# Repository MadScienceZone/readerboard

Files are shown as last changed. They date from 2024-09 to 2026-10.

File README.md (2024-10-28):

# Readerboard + Busylight
An Electronic Readerboard 64x8 Sign with Discrete "busylight status" LEDs (Arduino-powered).
There is also a smaller, standalone Busylight unit which just provides a status indicator with a 360° view. This was
previously developed in its own dedicated [github project](https://github.com/MadScienceZone/busylight), but it is
now merged into this one.

The next round of development will adapt the firmware and hardware design to drive the various RGB matrix displays
the author bought a couple of years ago from Adafruit as well.

## Description
This is mostly just a thing I put together for [hack value](http://www.catb.org/~esr/jargon/html/H/hack-value.html).

I had been experimenting for years with ideas for LED matrix readerboard design and
implementation, mostly focused on a 64x7 or 64x8 array of single-color LEDs.

Meanwhile, another weekend's idea to solve my need for an office availability
indicator resulted in the Busylight project, which consisted of a set of seven
360° rings of LEDs stacked in a column. By lighting different LED colors or
flashing them in different patterns, a number of statuses could be indicated
to anyone in viewing range.

In late 2024, when the readerboard project was at a point where I had upgraded
it to a full-color RGB LED design and I had a working prototype, it became
apparent that the busylight project should be merged with this one since the
readerboard includes a busylight-style status indicator, making it a superset
of the other device. Now they share a common firmware code base.

The project includes source code for the firmware that runs on the Busylight and Readerboard units,
PCB fabrication files, schematics, and support programs. The latter includes a server which manages
multiple devices attached to a central computer. Requests may be made over the local network to the
server to request changes to what the units are displaying.

The construction and operation of the system, including the protocol used to communicate with the hardware
and the server, is fully documented.

### 64x8 RGB Readerboard
The main project point is to
implement a 64x8 LED matrix display with 8 status LEDs available alongside the main matrix display,
which is driven by an Arduino microcontroller board attached directly to the back of the PCB.

It accepts commands sent via direct USB connection or over RS-485 serial network. The latter can accommodate multiple
daisy-chained units.  A full system can address up to 63 devices, although multiple RS-485 and/or USB circuits
will be required to have that many devices active at once.

### 64x8 Monochrome Readerboard
You can assemble a readerboard using the same PCB as the RGB version, but using monochrome LEDs instead of
RGB ones. A firmare source switch and recompile is needed for the microcontroller to correctly drive the hardware
in this configuration.

### Busylight
The Busylight unit is a 7-LED status indicator with 360° field of visibility. These can be used, for example,
to indicate if someone is busy or available to visitors, or on the phone. Or it could indicate the status
of a process, room occupancy, etc. (The 8 LED status LEDs on the Readerboard units are intended to achieve the
same purpose and accept the same commands as the Busylight units do.)

My original used these colors:
* Green: interrupt at will.
* Yellow: interrupt if important (this is shown if I happen to have anything scheduled on my Google calendars, such as a meeting or just some time blocked out to focus on a project)
* Red: in a meeting (this is shown if I'm actually connected to a video conference meeting)
* Flashing red: in a meeting, and my microphone is unmuted
* Flashing blue/red: urgent status
* Strobing green: (along with other lights) low-priority meeting, be aware I'm on camera but interruptions are ok

#### Software
On the PC, the normal mode of operation is to run the `busylightd` daemon. This monitors a set of Google calendars and reports busy/free times with the green and yellow
lights. It also responds to external signals from other processes which can inform it of other status changes.

In my case, I used [Hammerspoon](https://www.hammerspoon.org) which provides extensible automation capabilities for MacOS systems, including a very handy plugin that detects
when you join or leave a Zoom call, and tracks the state of the mute controls while in the meeting. I just configured that to send the appropriate signals to the
*busylightd* process when those statuses changed.

The upshot of that is that I can leave this running, put busy time on my calendars, join Zoom calls, and so forth, while the light indicator automatically displays
the appropriate colors.

##### API Access
To get access to the Google calendar API, you'll need to register with Google and get an API key. If I were distributing this as a pre-made app, I'd include my API key
with the distribution, but as a DIY project, if you make one of these based on my design, you're essentially creating your own app anyway so it makes sense to get a
separate API key for yours.

##### Documentation
There's a *busylight(1)* manual page included which explains the setup and operation of the software.

A schematic of how I wired up the hardware is also included, although it's fairly trivial, and can be adjusted to suit your needs.

##### GUI Tool
A simple tcl/tk script is supplied which provides a convenient front-end to the *busylight* program, with the addition of task time tracking.

A *blight(1)* manual page is provided to explain it.

# Release notes
See the `CHANGELOG.md` file.
## Current Status
I have a prototype Busylight and Readerboard built and being debugged.

There's a lot of pre-release development work underway which makes it to the `develop` branch occasionally.
This is where you can find the prototypes and experimental software and firmware images before they're ready
for full release (in which time they will be moved to the `main` branch).

## Copyright
This is all the original work of the author (Steve Willoughby). Copyright © 2023, 2024, All rights reserved. 
Portions based on prior work by the same author © 2008-2012. Released as open-source hardware and software 
under the terms and conditions of the BSD 3-Clause license.

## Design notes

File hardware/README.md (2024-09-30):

# Hardware
This directory contains the hardware design and manufacturing files necessary to understand and create
the PC boards for the readerboard and busylight devices.

## Readerboard
In the `readerboard` subdirectory, there is:
 * Schematic capture files prepared with KiCAD: `readerboard.kicad_*`
 * PCB layout design file prepared with the open source PCB program: `readerboard.pcb`
 * A `fab` subdirectory containing archives of files ready to be sent to a fab to be turned into physical circuit boards:
    * `readerboard-3.3.0.zip` Revision 3.3.0, can be assembled as RGB or single-color.
 * A PDF file `readerboard.pdf` produced from the `readerboard.pcb` file which shows all the board layers and drill locations.
 * A PDF file `readerboard_schematic.pdf` produced from the KiCAD files which is a human-readable schematic diagram.

## Busylight
In the `busylight` subdirectory, there is:
 * Schematic capture files prepared with KiCAD: `busyight.kicad_*` 
 * PCB layout design files prepared with the open source PCB program: `busylight.pcb`, `lighttree.pcb`, `lighttree-smd.pcb`
    * The `-smd` version is a variant which uses surface-mount resistors instead of through-hole components.
 * A `fab` subdirectory containing archives of files ready to be sent to a fab to be turned into physical circuit boards:
    * `busylight-2.1.1.zip` Revision 2.1.1 Busylight shield for the SparkFun Pro Micro.
    * `lighttree-1.1.zip` Revision 1.1 light tree octagonal disc to hold 8 LEDs for a level of the busylight unit.
    * `lighttree-1.1-S.zip` As above, but the alternate version of the board which uses surface-mount components.
 * PDF files `busylight.pdf`, `lighttree.pdf`, and `lighttree-smd.pdf` produced from the PCB files which shows the board layers and drill locations.
 * A PDF file `busylight_schematic.pdf` produced from the KiCAD files which is a human-readable schematic diagram.

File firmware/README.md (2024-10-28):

# Readerboard Firmware
The files in the `readerboard` sketch directory assume the Arduino Mega 2560 or Due (because I think that has adequate power for this task but mostly because I have a drawer full of them looking for something to do). My prototype that I actually built is based on the Due. I intend to make another and test it with a 2560 as well.

The font bitmaps are specified in `*.font` files in an easy-to-edit format and then "compiled" into `*.ino` files using the `mkfont` script.
Just run `make` in the `readerboard` directory to rebuild the font files if needed.

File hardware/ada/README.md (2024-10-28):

# Adafruit Matrix Support
The Arduino shield boards in this directory are experimental. If they work as expected, they can be used with the firmware as yet another model of readerboard
which uses the Adafruit 32x16, 32x32, and 64x64 RGB matrix boards, as well as a 64x16 display formed from two 32x16 boards connected together.

There are two shield designs here:
## adashield
This is an adaptation of the readerboard shield for our original 64x8 RGB matrix, but without any LEDs, and a ribbon cable connector intended to be
attached to one of the Adafruit matrix boards instead. It supports optional external EEPROM and RS-485 chips as the original 64x8 readerboard does,
as well as an 8-LED status "busylight" display (which is also external to the shield board, so a ribbon cable connector is supplied for that as well).
It also accommodates the same speaker output as the original readerboard.

## adashield_qs
This is a slight variation on the above shield for another of the author's personal projects which also uses readerboards and LED displays. It differs
in that it does not offer audio output, but supports 13 external discrete LEDs in addition to the RGB matrix, and an I2C-bus-connected LED alphanumeric
display.

## Directory Layout
The schematics and PCB layout files (in Kicad and gEDA PCB formats respectively) are in the main directory. The `fab` subdirectory contains zip archives
of the gerber files needed to have the actual printed circuit boards manufactured.

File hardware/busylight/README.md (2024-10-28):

# Busylight
This device is the author's original "busylight" project which gives a visual indicator of when he is on a video call, has an open microphone, or is otherwise
busy, so those nearby are aware. It has many other uses, such as indicating the status of long-running processes, occupancy status of rooms, etc.

It consists of a main board to which a SparkFun Pro Micro controller board is attached, and a set of "light tree" boards which make up the LED display itself.

## Directory Layout
The schematics and PCB layout files (in Kicad and gEDA PCB formats respectively) are in the main directory. The `fab` subdirectory contains zip archives
of the gerber files needed to have the actual printed circuit boards manufactured.

Two sets of light tree PCB files are provided. The ones with `-smt` added to their name use surface-mount resistors while the others use through-hole SIP resistor array packages.
Both are set up to use 3mm or 5mm through-hole LEDs, but these are actually mounted perpendicular to the board edges, with the leads soldered to the top and bottom board surfaces.

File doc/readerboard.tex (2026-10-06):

% NEED	ORDER
% 5	-	J0 stacking pins: 1x10, 5x8
% 5	-	J1a 179-TBLH10-381-08BK	or 6-pin
% 10	-	J2,J3 2p header
% 5	-	J4 3p header
% 5	-	J5 2p euro terminal block
% 6	-	J6 10p IDC header | 10p w2b header
% 6	-	10p IDC socket    | 10p w2b plug w/pins
% 10	-	J7,J8 16p IDC header | half 16p w2b header
% 10	-	16p IDC socket       | half 16p w2b plug w/pins
% 5	-	C0 10uF elec	(2560)
% 5	-	C1 0.1uF 
% 5 	-	D0 2A
% 25	-	R0-R4 10K
% 5	-	R5 1K (DUE)
% 5	-	R6 4x ___ ohms
% 5	-	R7 4x ___ ohms
% 5	-	R8 4x ___ ohms
% 5	-	R9 ___ ohms
% 5	-	R10 ___ ohms
% 15	-	2p shunt
% 5	-	U0 THVD1439DR
% 5	-	U1 24LC256
% 10	-	U2,3 ULN2003
%
% Nameplate R built-in jumper
% Nameplate G built-in jumper
% Nameplate B built-in jumper
% Button A 12V white 3v 450
% Button B 12V white 3v 450
% Button C 12V white 3v 450
% Button D 12V white 3v 450
% Button X R 12V 2v 500
% Button X G 12V 3v 450
% Button X B 12V 3v 450
% Button L R 12V 2v 500
% Button L Y 12V 2v 500
% Button L G 12V 3v 450
% Heartbeat B 12V 3v 450
%
% 16	-	white square button w/LED ABCD
% 4	-	lart switch
% 4	0	sets of r/g/y led side lights
% 4 	-	large round white button X
% 4 	-	RGB LED for X buttons
% 8	-	adafruit backpack segment displays
% 4	-	RGB nameplate lights
% 8	-	power connections? PSU?
% 
%
% 30	-	1N4148 diode
% 10	0	female centronics PCB 90deg sockets
% 5	-	8p IDC header | 8p w2b header
% 5	-	8p IDC socket | 8p w2b plug w/pins
% 5	-	10p euro terminal block
% 10-20	-	36p stacking headers | half sockets only w/o pins

% TODO: ^Jp in strings
% TODO: ^Up in strings
% TODO: H takes 0-63 value
% TODO: HK takes $-terminated list
% TODO: I takes height parameter
% TODO: Q returns matrix dimensions
% TODO: {up} and {down}
\input common
\frontmatter
\definecolor{reservedslot}{gray}{0.8}
\newcommand\api{\acronym{API}}
\newcommand\pc{\acronym{PC}}
\newcommand\cli{\acronym{CLI}}
\newcommand\ascii{\acronym{ASCII}}
\newcommand\led{\acronym{LED}}
\newcommand\ltp{\acronym{LTP}}
\newcommand\msb{\acronym{MSB}}
\newcommand\codetype[1]{\z{#1}}
\newcommand\ixz[1]{\index{#1@\z{#1}}\z{#1}}
\newcommand\tUnused{\cellcolor{gray!50}}
\newcommand\tControl{\cellcolor{yellow!50}}
\newcommand\tForbidden{\cellcolor{red!50}}
\newcommand\tSpecial{\cellcolor{blue!25}}
\newcommand\MUST{\mc{MUST}}
\newcommand\SHOULD{\mc{SHOULD}}
%\colorlet{tableheader}{blue!40}
%\colorlet{tablesubhead}{blue!20}
%\colorlet{recordbox}{blue!15}
%\colorlet{recordtext}{black}
%\usetikzlibrary{positioning,shapes,shadows,arrows}
%\tikzstyle{program}=[rectangle, draw=black, rounded corners, fill=recordbox, drop shadow,
%	anchor=north, text=recordtext, text width=2cm]
%\tikzstyle{instance}=[rectangle, draw=black, rounded corners, fill=green!15, drop shadow,
%	anchor=north, text=black, text width=3cm]
%\tikzstyle{line}=[-, thick]
%\tikzstyle{myarrow}=[->, >=triangle 45, thick]
\hypersetup{
	pdftitle={Readerboard User's Guide},
	pdfkeywords={Open Source Readerboard Hardware and Software},
	pdfauthor={Steve Willoughby / Mad Science Zone},
	pdfsubject={Readerboard Project Documentation * (c) 2023, 2024 * Creative Commons Licensing (See Document for details)},
	colorlinks=true,
	linkcolor=blue!30!black,
}
\thispagestyle{empty}
	\begin{center}
		{\Huge Readerboard and Busylight \\ User's Guide}

		\bigskip

		{\large Includes details on assembly, installation, and programming these messaging units.}

	\end{center}

\vfill
\begin{center}
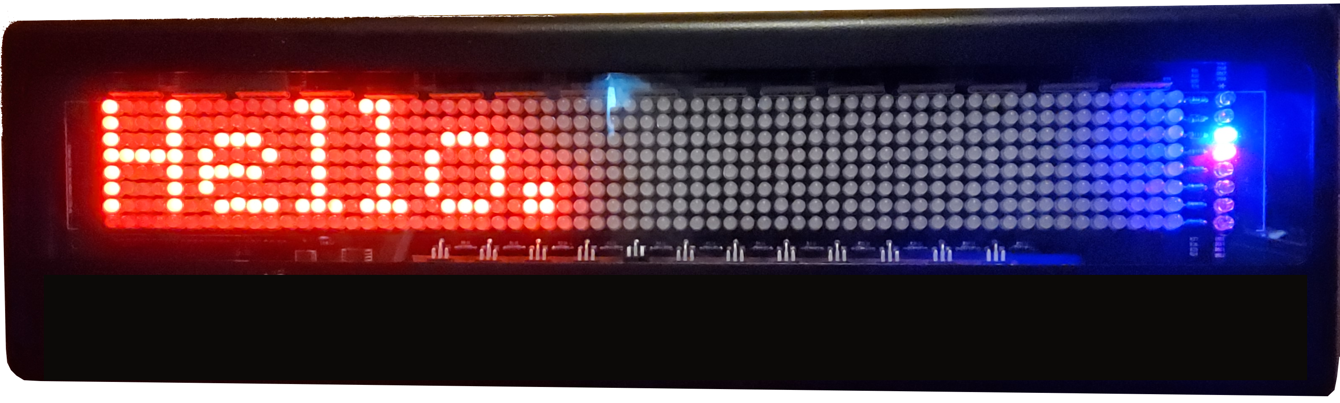
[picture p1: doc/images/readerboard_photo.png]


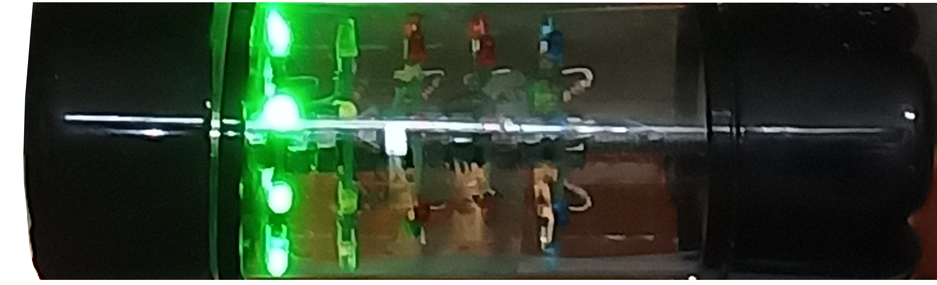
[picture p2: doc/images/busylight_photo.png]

\end{center}
\vfill
%\end{flushright}
\newpage
The information in this document, and the hardware and software it describes, are hobbyist
works created as an educational exercise and as a matter of personal interest for recreational
purposes.

It is not to be considered an industrial-grade or retail-worthy product.
It is assumed that the user has the necessary understanding and skill to use it appropriately.  The author makes NO
representation as to suitability or fitness for any purpose whatsoever, and disclaims any and all liability or 
warranty to the full extent permitted by applicable law.  It is explicitly not designed for use where the safety
of persons, animals, property, or anything of real value depends on the correct operation of the software.

As an educational exercise, it is assumed that the user has the necessary skill to appropriately set up, build,
and use this project. Do not proceed to use, whether exactly as provided in the repository or with modifications
of your own, unless you know exactly what you're doing and have verified that your actions and the product
materials are suitable for your purpose and function as expected.

\strut\vfill

\begin{center}\bfseries
	For Readerboard hardware (\acronym{PCB}) version 3.4.2, 
	Busylight hardware version 2.2.1 (light tree version 1.1), and firmware version 2.3.8.

	(Experimental support for Adafruit 16$\times$32, 32$\times$32, 16$\times$32$\times$2, and 64$\times$64 \acronym{RGB} matrix displays is a work in progress
	with current \acronym{PCB} revision 0.0.0.)
\end{center}

\strut\vfill

\noindent Copyright \copyright\ 2023, 2024 by Steven L. Willoughby
(aka MadScienceZone), Aloha, Oregon, USA. All Rights Reserved.
This document is released under the terms and conditions of the
Creative Commons ``Attribution-NoDerivs 3.0 Unported'' license.
In summary, you are free to use, reproduce, and redistribute this 
document provided you give full attribution to its author and do not
alter it or create derivative works from it.  See
\begin{center}
\href{http://creativecommons.org/licenses/by-nd-3.0}{http://creativecommons.org/licenses/by\-nd\-/\-3.0/} 
\end{center}
for the full set of licensing terms.

\begin{center}
\LJimg[width=.25in]{cc}\LJimg[width=.25in]{by}\LJimg[width=.25in]{nd}
\end{center}

\newpage
\tableofcontents
\newpage
\listoffigures
\listoftables
\mainmatter

%%%%%%%%%%%%%%%%%%%%%%%%%%%%%%%%%%%%%%%%%%%%%%%%%%%%%%%%%%%%%%%%%%%%%%%%%%%%%%%%%%%%%%%%%%%%%%%%%%%%
%  _   _    _    ____  ______        ___    ____  _____ 
% | | | |  / \  |  _ \|  _ \ \      / / \  |  _ \| ____|
% | |_| | / _ \ | |_) | | | \ \ /\ / / _ \ | |_) |  _|  
% |  _  |/ ___ \|  _ <| |_| |\ V  V / ___ \|  _ <| |___ 
% |_| |_/_/   \_\_| \_\____/  \_/\_/_/   \_\_| \_\_____|
%
\chapter{Hardware}
\epigraph{People who are really serious about software should make their own hardware.}{---Alan Kay}
\LJversal{A}{s a hobby project,} the design of the hardware and software for the read\-erboard
project ``grew in the telling'' as new ideas sprang to mind. As of this writing, there are three
different models of hardware prototypes which were designed and created.

\section{Version 1}
The initial prototype (\acronym{PCB} 1.0.1) was a fairly large board, approximately 20\sfrac{5}{8}$\times$6\sfrac{5}{8}$''$
with an \led\ pitch of \sfrac{1}{3}$''$.

It requires an Arduino Mega 2560 or Arduino Due to drive it. A custom-made shield board attaches to
the Arduino, which provides connectors for power and ribbon cables to drive the display (one to control
the matrix, the other for the 8 status \led s which appear in a horizontal row along the bottom
right of the matrix).

%One of the problems with this board is the use of the obsolete \acronym{TPIC6B595} chip. Later boards
%replaced this with a newer version. While it's technically possible to use the newer \acronym{STPIC6D595} chips
%on the 1.0.1 board, doing so requires a non-standard placement of the newer chip on the older chip's pads, 
%bending pins up, soldering jumper wires, possibly cutting traces, and and due
%to a pinout incompatibility between the two chips, the firmware also needs to be altered. As such, we don't
%recommend going this route. It would be best to use the newer board with the chips it was designed for.

\section{Version 2}
This version was based on the 1.0 design, but shrunk to a board size of about 18\sfrac{3}{16}$\times$5\sfrac{3}{16}$''$
with an \led\ pitch of \sfrac{1}{4}$''$. It also replaced the obsolete \acronym{TPIC6B595} with the newer \acronym{STPIC6D595} chip.
Further, it relocated the ribbon cable which connects the Arduino controller to the \led\ matrix, moved the
eight status \led s to a vertical column to the right of the matrix, and switched to resistor arrays
for the matrix current limiting resistors, instead of the individual discrete resistors used on the 1.0.1 board.

\section{Version 2}
Version 2.1 was a significant change to the 2.0 board in terms of how it interfaces with the Arduino, although it had the same size and physical
layout as the 2.0 board.

This one eliminates the need for the ribbon cables and shield board. Instead, the Arduino controller mounts
directly to the back of the display board. This means that the lower portion of the left edge of the enclosure
has all of the external connections in one place, including power, \acronym{RS-485} in and out, and the 
\acronym{USB} connector(s) on the Arduino itself.

\section{Version 3}
Revision 3.\Var{x} of the hardware expands on the version 2.1 design by replacing the single-color \led s with
\acronym{RGB} \led s arranged into 24 logical rows---each of the eight physical rows is logically a row of red,
green, and blue \led\ elements.

Note that the discrete status \led s are mislabeled on the revision 3.2.2 \acronym{PCB}. L$_0$ should be the \led\
on the bottom (canonically green) and L$_7$ is on top (white).

\subsection{Version 3.4.1 (current model)}
Version 3.4 added support for playing sounds on a speaker and added a diode (D520) to prevent
the Arduino from trying to power the \led s by itself if it is powered from the \acronym{USB}
port but the external 9\,V supply is not active.

\subsection{Version 3.3.1}
Version 3.3 of the hardware corrects some minor issues with the 3.2.2 revision by adding a cutout to avoid colliding with the
connectors on the Arduino board and adjusting the mounting holes slightly. It also corrects the mislabeled L$_0$--L$_7$ \led s

Additionally, it adds R51 for Arduino Due reset circuits, J3 to manually reset the Arduino, and J4, R52, R53, and U16 to support the addition of a external
\acronym{EEPROM} chip for microcontrollers (such as the Due) which don't have one onboard.

This was further improved with revision 3.3.1 (the current version), which replaced terminal block J1 with a higher-density terminal
which allows easier interconnection of two \acronym{CAT6} cables without the need for off-board splices. The power supply now connects to
a new terminal block J5. The power to the \acronym{RS-485} transceiver chip is also now switchable to either 3.3\,V or 5\,V so it can be
appropriately matched to the operating voltage of the Arduino board without damaging the Arduino's input ports.

\section{Firmware Implications}
The boards before \acronym{PCB} revision 3.3.0 are not supported by the firmware as currently stored in the project repository. They were prototype ideas
which were never built, so this shouldn't be a problem. 

There are compile-time switches documented starting on p.~\pageref{config-fw} which adjust the firmware
image for different microcontrollers, default settings---or the only settings if your hardware does not
include an \acronym{EEPROM} memory---and possibly, in the future, different board revisions.

\section{Construction}
Once you have created a printed circuit board (\acronym{PCB}) from the fabrication files included with the
readerboard Git repository and obtained the parts as listed in Figure~\ref{fig:bom}, carefully solder the components
in place. 

{\bfseries Warning! Danger! Only perform the assembly operation if you are qualified to do so. Soldering electronic components
may be hazardous due to the high temperatures, sharp objects, electrical voltages, potentially toxic materials,
and other dangers. This requires skill and expertise as well as personal protection equipment to perform safely.}
Please also observe all precautions to avoid damaging the electronic components themselves from harm due to
heat or static electricity discharge.
\newcommand\mouser[1]{{\sffamily\footnotesize#1}}
\begin{table}
	\begin{tabular}{lrll}\toprule
		{\bfseries Part No.}&{\bfseries Qty}&{\bfseries Mouser}&{\bfseries Description}\\\midrule
		&1&&Printed circuit board rev 3.2.2\\
		&1&&Arduino Due or Mega 2560\\
		C0--9,11,12&12&\mouser{810-FA18X7R1H10400}&\SI{0.1}{\micro\farad} capacitor\\
		C10&1&\mouser{667-ECA-1HM100I}&\SI{10}{\micro\farad} electrolytic capacitor\\
		C13&1&&\SI{100}{\micro\farad} electrolytic capacitor\\
		D0--511&512&[1]&\led, 5mm, \acronym{RGB}, common cathode\\
		D512&1&&\led, 5mm, green\\
		D513--14&2&&\led, 5mm, amber (yellow)\\
		D515--16&2&&\led, 5mm, red\\
		D517--18&2&&\led, 5mm, blue\\
		D519&1&&\led, 5mm, white\\
		D520&1&&power diode, 4\,A\\
		J0&1&&Arduino stacking pin set\\
		J1a,b&2&\mouser{179-TBLH10-381-08BK}&8-position terminal block\\
		J2,3&2&\mouser{649-69190-102HLF}&2-position jumper header\\
		J4&1&&3-position jumper header\\
		J5,6&2&&2-position Euro-style terminal block\\
		P0--2&3&&2-position jumper shunt\\
		Q0--23&24&\mouser{942-IRF9530NPBF}&\mc{IRF9530} p-channel \acronym{MOSFET}\\
		Q24&1&&\mc{2N2222} or \mc{BC547} \mc{NPN} transistor\\
		R0--7,35--51&24&\mouser{604-MFR-24FRF521K}&1K resistor\\
		R8--23&16&&4$\times$360$\Omega$ resistor array, isolated\\
		R24,29--31&4&\mouser{603-MFR-25FTE52-300R}&300$\Omega$ resistor\\
		R25--28&4&&360$\Omega$ resistor\\
		R32--34,52--54&6&\mouser{603-MFR-25FRF5210K}&10K resistor\\
		R$_{\text{TERM}}$&1&&120$\Omega$ resistor\\
		U0,12,13&3&\mouser{595-CD74HCT238PWR}&\mc{CD74HCT238PWR} non-inverting 3-to-8 decoder\\
		U1,2,14,15&4&&\mc{ULN2803CDWR} octal NPN Darlington array\\
		U3--10&8&&\mc{STPIC6D595MTR} power 8-bit shift register\\
		U11&1&\mouser{595-THVD1439VDR}&\mc{THVD1439} half-duplex RS-485 driver/receiver\\
		U16&1&\mouser{579-24LC256T-E/SN}&\mc{AT24C256} \acronym{EEPROM}\\
		%X0&1&&\mc{AT24C256} \acronym{EEPROM} module\\
		&24&&\mc{TO}-220 heat sinks for Q0--23 (optional)\\
		&1&&9V 2A DC power supply\\
		\bottomrule
		\multicolumn{4}{p{\textwidth}}{\tiny[1] I found these at Amazon.com: \href{https://www.amazon.com/EDGELEC-Tri-Color-Multicolor-Diffused-Resistors/dp/B077XGF3YR}{EDGELEC 5mm RGB Tri-Color 4Pin LED Diodes Common Cathode}.}
	\end{tabular}
	\caption{Bill of Materials\label{fig:bom}}
\end{table}

\subsection{Suggested Order}
For best results, solder components in a way that allows best access to the solder points without some parts getting
in the way of connecting subsequent ones. For example:

\begin{enumerate}
	\item Solder all the surface mount chips first: U0--U15 (and optionally, U16).
		\begin{itemize}
			\item U0, U12, U13: CD74HCT238PWR
			\item U1, U2, U14, U15: ULN2803CDWR (ULN2803A SOP-18 packages may be used if aligned to the top 18 pads, leaving the bottom two empty, if they have otherwise identical pinouts and characteristics)
			\item U3--U10: STPIC6D595MTR
			\item U11: THVD1439DR (Note that this chip is oriented 180$^{\circ}$ from the other chips on the board, with pin~1 to the lower right.)
			\item If needed for your microcontroller (Arduino Due, usually), solder U16: AT24C256 \acronym{EEPROM} chip.
		\end{itemize}
	\item Solder the discrete resistors: R0--R7, R24--R51, and R54 (and optionally, R52 and R53). See below first to ensure the correct values are used
		for R24--R31 based on your choice of corresponding \led s.
		\begin{itemize}
			\item R0--R7, R35--50: 1K
			\item R24, R29--R31: 300$\Omega$
			\item R25--R28: 360$\Omega$
			\item R32--R34: 10K
			\item If U16 is installed, solder in R52--R53: 10K
			\item If using sound output, solder in R54: 10K
		\end{itemize}
	\item Solder the \SI{0.1}{\micro\farad} capacitors: C0--C9, C11--C12.
	\item Solder the resistor arrays: R8--R23.
	\item Solder the \acronym{RGB} \led s D0--D511. Ensure that the common cathode goes to pin~2 so that pins 1, 3, and 4
		are respectvely the red, green, and blue anodes.
	\item Solder the single-color \led s D512--D519 in the colors of your choice, being mindful of the polarity. The anode has a square pin on the \acronym{PCB}. Our recommendation:
		\begin{itemize}
			\item D512 (bottom): green (with R24=300$\Omega$)\footnote{Resistor values based on typical \led\ voltage and current ratings. Check to see what is appropriate for your components.}
			\item D513: amber\footnote{In deference to the effort my high school drama teacher went through to get us to refer to any yellow stage lights and gels as ``amber'' and the
				preference to using ``amber'' for signal lamp colors in other contexts and regions, both terms will be used interchangeably in this project.} (with R25=360$\Omega$)
			\item D514: amber (with R26=360$\Omega$)
			\item D515: red (with R27=360$\Omega$)
			\item D516: red (with R28=360$\Omega$)
			\item D517: blue (with R29=300$\Omega$)
			\item D518: blue (with R30=300$\Omega$)
			\item D519 (top): white (with R31=300$\Omega$)
		\end{itemize}
	\item \strong{If you are using an Arduino Due:} solder R51 (1K).
	\item \strong{If you are using an Arduino Mega 2560:} Solder the \SI{10}{\micro\farad} capacitor C10, being mindful of the correct polarity. \strong{Do not solder both R51 and C10. Only one or the other will be appropriate for a given microcontroller.}
	\item Solder the Arduino bus stacking pins (six connectors---1$\times$10-pin, 5$\times$8-pin---all labeled collectively as ``J0'').
		Ensure the pins extend down and out the back of the board.
	\item Solder the 2-pin headers J2 and J3, and the 3-pin header J4.
	\item Solder the terminal blocks J1 (which is actually a pair of 8-pin terminal blocks J1a and J1b), and J5.
\end{enumerate}

\subsection{Option: Using Single-Color LEDs}
If you don't need \acronym{RGB} \led s for your application, the same \acronym{PCB}
may be used with single-color 5mm \led s instead. Simply solder them onto the board so
that their cathode is on pin~2 and the anode is on pin~4 of the \led\ footprint. This
means the \led s will electrically all be connected to the blue circuit. 

Since they won't be used, omit parts U0, U2, U12, U14, C0, C11, Q0--Q15, R0--R7, and R35--R42.

Set the firmware value \z{HW\_MODEL} to \z{MODEL\_3xx\_MONOCHROME} and recompile the firmware. This
changes the behavior of the controller so that it understands it can only drive one color which
is attached to the blue color plane. Now, all colors (other than ``off'') will turn the \led s
on.

\section{Busylight Devices}
The readerboard units are designed to be compatible with another project by the author. The ``Busylight''
is a small stand-alone indicator which can be used to indicate simple statuses like room occupancy or
whether someone is busy, free, on a phone call, etc.

The busylight can drive up to seven \led s. If directly connected to a host computer
via \acronym{USB}, it can be powered entirely from the \acronym{USB} port. Starting with version 2,
it can also receive commands via \acronym{RS-485} network. In that case it can be powered by a 9\,V
supply over the same \acronym{CAT5}, \acronym{CAT5e}, or \acronym{CAT6} cable carrying the serial
communications.

\subsection{Firmware}
Starting with revision 2 of the Busylight, it is driven by a firmware image compiled from the same
source code as the Readerboard units. Setting the compiler preprocessor symbol
\z{HW\_MODEL} to \z{MODEL\_BUSYLIGHT\_2} will cause the Arduino compiler to prepare the image
for a Busylight, excluding the code that drives the readerboard-specific functions.
In such firmware images, \z{HW\_MC} should be set to \z{HW\_MC\_PRO} since the Busylight is
based on the SparkFun Arduino-compatible Pro Micro microcontroller.

Also set the \z{SERIAL\_VERSION\_STAMP} symbol to reflect the device serial number, hardware and firmware
revision numbers. See Chapter~\ref{chap:firmware} starting on p.~\pageref{chap:firmware} for more information
about preparing firmware images.

\subsection{Construction}
Once you have created a printed circuit board (\acronym{PCB}) from the fabrication
files included with the Git repository and obtained the parts
as listed in Figure \ref{fig:busylightbom}, carefully solder the components in place.

\strong{Warning! Danger! Only perform the assembly operation if you
are qualified to do so. Soldering electronic components may be
hazardous due to the high temperatures, sharp objects, electrical
voltages, potentially toxic materials, and other dangers. This requires skill and expertise as well as personal protection equipment
to perform safely.} Please also observe all precautions to avoid damaging
the electronic components themselves from harm due to heat or static electricity discharge.
\begin{table}
    \begin{center}
	\begin{tabular}{lrll}\toprule
		{\bfseries Part}&{\bfseries Qty}&&{\bfseries Description}\\\midrule
		&1&&Printed circuit board rev 2.1\\
		&7&&\led\ tier printed circuit board rev 1.1\\
		%&7&&\led\ ring printed circuit board (if desired)\\
		&1&&SparkFun Pro Micro Arduino-compatible $\mu$C, \strong{5\,V version}\\
		C0&1&&\SI{0.1}{\micro\farad} capacitor\\
		C1&1&&\SI{100}{\micro\farad} capacitor\\
		D0&1&&power diode, 1\,A\\
		J0&1&&8-pin DIN connector, \acronym{PCB} mount\\
		J1&1&&16-pin Euro-style terminal block\\
		J2&1&&Arduino stacking pin set\\
		J3&1&&2-pin Euro-style terminal block\\
		P0&1&&8-pin DIN plug\\
		Q0&1&&BC547 or 2N2222 NPN transistor\\
		R0--3&4&&10K resistor\\
		U0&1&\mouser{595-ULN2003AIDR}&\mc{ULN2003A} NPN Darlington array\\
		U1&1&&\mc{THVD1439} half-duplex RS-485 driver/receiver\\
		  &14&&5-pin bussed resistor network (2/\led\ tier)*\\
		  &56&&\led, 5\,mm or 3\,mm, through-hole (8/\led\ tier)$\dagger$\\
		  &1&&\sfrac14$''$ screw rod\\
		  &1&&Enclosure$\ddagger$\\
		  &8&&Nylon spacers between (and above and below) the tiers\\
		  &2&&\sfrac14$''$ hex nuts\\
		\bottomrule
		\multicolumn{4}{p{\textwidth}}{\tiny *Choose each tier's pair of resistor arrays appropriately for the voltage drop
		for the LEDs to be used on that tier. Assuming a 5\,V supply and
		typical LED characteristics for a desired 20\,mA current draw, that would be 150$\Omega$ or larger for red and amber LEDs and 100$\Omega$ or larger
		for blue, green, and white LEDs. Check your LED datasheet to confirm. Examples: Mouser \mouser{652-4605X-1LF-100} (100$\Omega$)
		or \mouser{652-4605X-1LF-150} (150$\Omega$).

		\noindent$\dagger$Choose LED colors as desired for each tier (standard is green, 2$\times$amber, 2$\times$red,
		blue, and white).

		\noindent$\ddagger$One idea for an inexpensive enclosure is a clear plastic tube storage container with an inside
		diameter large enough to hold the LED tier boards.}
	\end{tabular}
	    \caption{Bill of Materials (Busylight)\label{fig:busylightbom}}
    \end{center}
\end{table}

\subsection{Suggested Order}
For best results, solder components in a way that allows best access to the
solder points without some parts getting in the way of connecting subsequent ones. For example:
\begin{enumerate}
	\item Solder the surface mount components:
		\begin{itemize}
			\item U0 \acronym{ULN2003A} 7-circuit \acronym{NPN} Darlington transistor array.
				Note that the board was designed for narrow \acronym{SOIC-16} packages but
				there is an additional column of pads for a wider version of this chip.
			\item U1 \acronym{THVD1439} \acronym{RS-485} driver/receiver.
		\end{itemize}
	\item Solder through-hole components:
		\begin{itemize}
			\item R0--R2 10K resistors
			\item C0 \SI{0.1}{\micro\farad} capacitor
		\end{itemize}
	\item Solder the sockets:
		\begin{itemize}
			\item J0 8-pin DIN socket
			\item J1 16-circuit Euro-style terminal block (alternatively you may choose to
				directly solder the \acronym{CAT6} wires into the holes on the \acronym{PCB}.
			\item Arduino stacking pins.
		\end{itemize}
	\item Place the microcontroller board onto the stacking pins.
	\item Build each \led\ tier of 8 \led s:
		\begin{itemize}
			\item Solder eight 3\,mm \led s around the edge of the board with their leads straddling
				the edge, so the anode is on the side of the \acronym{PCB} labelled ``anode side'' and the
				cathode is on the ``cathode side.'' Solder the leads to the exposed pads and trim the
				leads so they don't extend past the pads.
			\item Solder the two resistor arrays, making sure to select the correct values for the specific
				\led s used on this tier board.
		\end{itemize}
	\item Assemble the tier stack by threading the tiers onto the \sfrac14$''$ threaded rod with nylon spacers between them,
		secured in place with hex nuts on either end of the stack. The following assumes the use of a length of \acronym{CAT6}
		cable between the \acronym{PCB} and the light tree stack.
		\begin{itemize}
			\item Solder one end of the cable to P0, the 8-bin \acronym{DIN} plug. Suggested color assignments:
				\begin{itemize}
					\item Pin 1 (sixth tier/blue): blue	
					\item Pin 2 (third tier/amber): brown/white
					\item Pin 3 (fifth tier/red): orange/white
					\item Pin 4 (fourth tier/red): orange
					\item Pin 5 (seventh tier/white): blue/white
					\item Pin 6 (second tier/amber): brown
					\item Pin 7 (+5\,V supply): green
					\item Pin 8 (bottom tier/green): green/white
				\end{itemize}
			\item Strip the insulation from the green wire to the height of the assembled tier tree.
				As each tier is added, thread this bare wire through the ``V+'' hole of each tier, soldering it to
				each tier along the way.
			\item Attach the wire for each tier to its ``GND'' hole.
			\item Thread the remaining wires through the larger holes to pass them up to the next tiers.
		\end{itemize}
\end{enumerate}

\section{Controller for Adafruit Matrices}
We obtained a number of pre-made \acronym{RGB} \led\ matrix displays from Adafruit which have a similar
(but not quite the same) control logic to our own design, which allows us to also control those boards using
only a slight variation in our hardware and firmware design.

The hardware to drive them is a small shield board that plugs onto an Arduino Due or Mega 2560. It incorporates the
same control circuitry as our original readerboard circuit described above, without the actual \led s themselves or
the discrete chips that drive the rows and columns of the display, since those are already on the pre-made displays.

This shield provides two ribbon cable connectors: J7, a 16-pin cable which sends the control signals to the matrix display,
and J8, a 10-pin cable that can drive an 8-\led\ discrete status display such as is on the busylight and our original readerboard.

The following describes the assembly of one of these shield boards.
\begin{table}
	\begin{tabular}{lrll}\toprule
		{\bfseries Part}&{\bfseries Qty}&{\bfseries Mouser}&{\bfseries Description}\\\midrule
		&1&&AdaShield Printed circuit board rev 0.0.0\\
		&1&&Arduino Due or Mega 2560\\
		C0&1&&\SI{100}{\micro\farad} electrolytic capacitor\\
		C1&1&\mouser{810-FA18X7R1H10400}&\SI{0.1}{\micro\farad} capacitor\\
		C2&1&\mouser{667-ECA-1HM100I}&\SI{10}{\micro\farad} electrolytic capacitor\\
		D0&1&&power diode, 1\,A\\
		J0&1&&Arduino stacking pin set\\
		J1a,b&2&&8-position terminal block\\
		J2,3&2&&2-position jumper header\\
		J4&1&&3-position jumper header\\
		J5,6&2&&2-position Euro-style terminal block\\
		J7&1&&16-position \acronym{IDC} header\\
		J8&1&\mouser{517-89110-0101}&10-position \acronym{IDC} header\\
		P0--2&3&&2-position jumper shunt\\
		Q0&1&&\mc{2N2222} or \mc{BC547} \mc{NPN} transistor\\
		R0--5&6&\mouser{603-MFR-25FRF5210K}&10K resistor\\
		R6&1&\mouser{604-MFR-24FRF521K}&1K resistor\\
		R$_{\text{TERM}}$&1&&120$\Omega$ resistor\\
		U0&1&&\mc{THVD1439} half-duplex RS-485 driver/receiver\\
		U1&1&&\mc{AT24C256} \acronym{EEPROM}\\
		U2&1&&\mc{ULN2803CDWR} octal NPN Darlington array\\
		&1&&9V 2A DC power supply\\
		\bottomrule
	\end{tabular}
	\caption{Bill of Materials for AdaSheild Board\label{fig:bom-ada}}
\end{table}

\subsubsection{AdaShield/QS Variation}
The author produced a variation on the AdaSheild boards for another project, but they may still be useful for
general use as an alternative to the above-described board in that it lacks a speaker output, but adds an I$^2$C alphanumeric
\led\ display output and expands the discrete \led\ output from 8 \led s to 14.

\begin{table}
	\begin{tabular}{lrll}\toprule
		{\bfseries Part}&{\bfseries Qty}&{\bfseries Mouser}&{\bfseries Description}\\\midrule
		&1&&AdaShield/QS Printed circuit board rev 0.0.0\\
		&1&&Arduino Due or Mega 2560\\
		C0&1&\mouser{667-ECA-1HM100I}&\SI{10}{\micro\farad} electrolytic capacitor\\
		C1&1&\mouser{810-FA18X7R1H10400}&\SI{0.1}{\micro\farad} capacitor\\
		D0&1&&power diode, 2\,A\\
		J0&1&&Arduino stacking pin set\\
		J1a,b&2&&8-position terminal block\\
		J2,3&2&&2-position jumper header\\
		J4&1&&3-position jumper header\\
		J5&1&&2-position Euro-style terminal block\\
		J6&1&&10-position \acronym{IDC} header\\
		J7,8&2&&16-position \acronym{IDC} header\\
		P0--2&3&&2-position jumper shunt\\
		R0--4&5&\mouser{603-MFR-25FRF5210K}&10K resistor\\
		R5&1&\mouser{604-MFR-24FRF521K}&1K resistor\\
		R6-8&3&&Resistor array, isolated, 4-resistors*\\
		R9,10&2&&Resistor*\\
		R$_{\text{TERM}}$&1&&120$\Omega$ resistor\\
		U0&1&&\mc{THVD1439} half-duplex RS-485 driver/receiver\\
		U1&1&&\mc{AT24C256} \acronym{EEPROM}\\
		U2,3&2&\mouser{595-ULN2003AIDR}&\mc{ULN2003A} NPN Darlington array\\
		&1&&9V 2A DC power supply\\
		\bottomrule
		\multicolumn{4}{p{\textwidth}}{\tiny*R6--10 each limit current to the discrete \led s. Choose their values appropriately
		for the supply voltage and current needs of the \led s to be driven.}
	\end{tabular}
	\caption{Bill of Materials for AdaSheild Board (QS Variant)\label{fig:bom-ada-qs}}
\end{table}

%%%%%%%%%%%%%%%%%%%%%%%%%%%%%%%%%%%%%%%%%%%%%%%%%%%%%%%%%%%%%%%%%%%%%%%%%%%%%%%%%%%%%%%%%%%%%%%%%%%%
%  ____  ____   ___ _____ ___   ____ ___  _     
% |  _ \|  _ \ / _ \_   _/ _ \ / ___/ _ \| |    
% | |_) | |_) | | | || || | | | |  | | | | |    
% |  __/|  _ <| |_| || || |_| | |__| |_| | |___ 
% |_|   |_| \_\\___/ |_| \___/ \____\___/|_____|
%
\chapter{Protocol Description}\label{chap:protocol}
{\setlength{\epigraphwidth}{.5\textwidth}
\epigraph{I don't stand on protocol. Just call me your Excellency.}{---Henry Kissinger}}
\LJversal{T}{he control protocol} used to display information on the readerboard sign is very simple.
Commands are expressed largely in plain \ascii\ characters and are executed immediately
as they are received.\footnote{Technically, they may even be executed \emph{while} they
are being received.}
%It is not necessarily required for a command to be fully received first,
%so it is possible that the sign will have started operating on part of the command (e.g.,
%moving the current cursor column position) even if the rest of the command could not be
%performed.

In addition to plain, printable 7-bit \ascii\ characters, a few control codes are
recognized as described below. String data may include any 8-bit value except as otherwise
indicated.

%\section{JSON}
%The organization of the rest of this chapter is oriented toward a description of the
%protocol used to control the hardware directly over a \acronym{USB} or \acronym{RS-485}
%connection. However, you can set up a central server which is connected to all the
%readerboard signs and busylight indicators in a small area (via \acronym{USB} or \acronym{RS-485}).
%This allows clients to send commands to the server over the network for control of the readerboards.
%
%The protocol between clients and servers uses messages which are simple \acronym{JSON} representations
%of the underlying hardware protocol, which is more convenient for network clients and servers to use.
%Since this mirrors the hardware protocol, those \acronym{JSON} objects will be listed below as well.
%
%As a general rule, these messages are each terminated with a newline, and may not contain newlines otherwise.
%
%Clients and servers \MUST\ accept \acronym{UTF-8} but \SHOULD\ emit 7-bit \acronym{ASCII} with standard \acronym{JSON} escape
%codes for codepoints greater than 127.
\section{Web Service API}
The organization of the rest of this chapter is oriented toward a description of the
protocol used to control the hardware directly over a \acronym{USB} or \acronym{RS-485}
connection. However, you can set up a central server which is connected to all the
readerboard signs and busylight indicators in a small area (via \acronym{USB} and/or \acronym{RS-485}).
This allows clients to send commands to the server over the \acronym{LAN} for control of the readerboards.

The protocol between clients and servers uses messages which are simple \acronym{HTTP} requests
posted to the server's listening port \acronym{URL}. If the server were configured to run
on \z{example.org} on port \z{43210}, then all client requests to that server would begin with

\begin{Coding}
	|http://example.org:43210/readerboard/v1/|\Var*{message}|?a=|\Var*{targets}
\end{Coding}

\subsection{Message Data Fields}
As a general rule, if a message expects a field that is not provided, where possible, a suitable ``zero'' value will be assumed
for that field. Any extra fields sent that were not expected are silently ignored.

Boolean fields may have values \z{true} or \z{false}; if they are presented without a value, they are considered to be
\z{true}, and if completely missing they are assumed to be \z{false}. Thus,

\begin{Coding}
	\dots|/readerboard/v1/|\Var*{message}|?a=|\Var*{targets}|&status=true|
\end{Coding}

\noindent is equivalent to

\begin{Coding}
	\dots|/readerboard/v1/|\Var*{message}|?a=|\Var*{targets}|&status|
\end{Coding}

\noindent and

\begin{Coding}
	\dots|/readerboard/v1/|\Var*{message}|?a=|\Var*{targets}|&status=false|
\end{Coding}

\noindent is equivalent to

\begin{Coding}
	\dots|/readerboard/v1/|\Var*{message}|?a=|\Var*{targets}
\end{Coding}

\subsection{Message Target Addresses}
Every message also has a field called ``\z{a}'' which is a comma-separated list of target readerboards to which the message
applies.

So, for example, the message containing \z{a=2} would cause the server to transmit the corresponding command to the readerboard with address 2 directly connected to it via \acronym{USB}, or
would transmit to the \acronym{RS-485} network the command starting with the hex byte \z{92}$_{16}$. (Why that byte value is sent will make sense after you read the protocol
description that follows.)

If multiple devices are targeted, e.g., with a message containing the field \z{a=2,5,37} with address 15 (i.e., \z{0F}$_{16}$) configured as the global address \Var{ad$_G$},
it will transmit to the \acronym{RS-485} network a command starting with the hex byte sequence \z{BF}$_{16}$ \z{03}$_{16}$ \z{02}$_{16}$ \z{05}$_{16}$ \z{25}$_{16}$, or---if applicable---will send the message directly to any of devices 2, 5, and 37 which are directly connected via \acronym{USB}.

\section{Direct Host-to-Device Communication}
The host \acronym{PC} (which may or may not be running the server program) connects to one or more
readerboard and/or busylight devices by direct wire. The remainder of this chapter describes the
protocol used for this communication. If you consider the standard \acronym{ISO} \acronym{OSI} network
protocol stack, there are three layers of concern for us here, as illustrated in Figure~\ref{figure-layers}.

\begin{figure}
\begin{center}
\begin{bytefield}[endianness=little,bitwidth=0.05\textwidth]{9}
	\bitbox[]{1}{}&
	\bitbox[]{4}{\tiny ISO/OSI}&
	\bitbox[]{4}{\tiny Lumos}\\
	\begin{rightwordgroup}{Readerboard/Busylight}
	\bitbox[]{1}{7}&\bitbox{4}{Application}&\bitbox{4}{Application}
	\end{rightwordgroup}\\
	\bitbox[]{1}{6}&\bitbox{4}{\color{reservedslot}Presentation}\\
	\bitbox[]{1}{5}&\bitbox{4}{\color{reservedslot}Session}\\
	\begin{rightwordgroup}{USB or Lumos-compatible\\RS-485 network}
	\bitbox[]{1}{4}&\bitbox{4}{Transport}&\bitbox[lrt]{4}{Transport}\\
	\bitbox[]{1}{3}&\bitbox{4}{Network}&\bitbox[lrb]{4}{(LTP)}
	\end{rightwordgroup}\\
	\bitbox[]{1}{2}&\bitbox{4}{\color{reservedslot}Data Link}\\
	\bitbox[]{1}{1}&\bitbox{4}{Physical}&\bitbox{4}{Physical}
\end{bytefield}
\end{center}
	\caption{Protocol Stacks (ISO vs. Lumos Models)\label{figure-layers}}
\end{figure}

\section{Physical Layer}
At the lowest level, the serial bits are encoded and are carried over wires using either a direct \acronym{USB} connection
to the host or a wider-area \acronym{RS-485} serial network. We don't need to worry about that level of the communication
here.

It is worth noting, however, that the readerboard and busylight devices use half-duplex \acronym{RS-485} interfaces, so when
they are communicating over that network and are asked to send data back to the host, they will reverse the data direction
of these layers until that data are transmitted, then reverts back to receiving on the data channel.

\section{Transport Layer}
This layer is responsible for getting the signals to the correct devices. This layer adds some data packaging around the
message being sent to the device depending on the underlying physical connection type as described below.

\subsection{USB Transport Protocol}
Since each \acronym{USB} cable between the host and a device provides a single point-to-point connection, no addressing is
needed (since there can only be one device on the other end of the wire, the host already knows which device it's talking to
when sending messages on that \acronym{USB} port).

In this case, a single byte with value \z{04}$_{16}$ (character \z{\textasciicircum D}) is appended to the end of the
data packet.

\begin{center}
\begin{bytefield}[endianness=little,bitwidth=0.11111\textwidth]{9}
	\bitbox[]{1}{\scriptsize0}&
	\bitbox[]{1}{\scriptsize\dots}&
	\bitbox[]{1}{\scriptsize$n-1$}&
	\bitbox[]{1}{\scriptsize$n$}\\
	\bitbox{3}{\Var*{packet}}&
	\bitbox{1}{\z{\textasciicircum D}}
\end{bytefield}
\end{center}

If there is an error parsing or executing a command, the device will ignore
all subsequent input until a \z{\textasciicircum D} byte is received, whereupon it will
expect to see the start of another command. Thus, \z{\textasciicircum D} may not
appear in any transmitted data except to terminate commands.

\subsection{RS-485 Transport Protocol}
The \acronym{RS-485} standard is a differential serial signal which can be run up to
1,000 meters over unshielded twisted-pair cables such as \acronym{CAT5} or \acronym{CAT6}.
Up to 32 devices (including the host itself) can ``tap into'' this serial bus at various
points (although physically this generally takes the form of ``daisy chaining'' connections
where a cable plugs each device into the next one in the chain, with terminators plugged into
the first and last devices).

Since multiple devices may exist on the same bus, they will all see the signals sent on that
bus and thus must at least understand those messages enough to differentiate their messages
from those destined for other devices even if they don't know how to fully interpret other
devices' command sets.

To accomplish this, the \acronym{RS-485} transport layer employed here uses a transport protocol
the author designed for his Lumos light control devices. By being compatible with this standard,
any set of readerboards, busylights, Lumos controllers, and any other devices following the same
standard may be mixed on the same \acronym{RS-485} network without conflict as long as they have
distinct addresses assigned to them.

All data sent over \acronym{RS-485} must conform to the following simple rules to be compatible
with the Lumos Transport Protocol (hereafter \ltp):
\begin{itemize}
	\item The first byte in a command packet has its \msb\ set (\z1).
		\begin{itemize}
			\item The lowest four bits of this byte specify the target device's address (0--15).
			\item The device may ignore this and all subsequent bytes if the address isn't the global address or its own.
			\item The remaining three bits specify the command to be executed on the target device.
			\item Devices MAY implement extended commands in subsequent bytes to allow more than 8 commands, and/or
				respond to global target addresses by decoding additional target IDs in subsequent bytes to allow
				for multiple targets per device and/or device IDs greater than 15, but this is optional.
		\end{itemize}
	\item All subsequent bytes in a command packet must have their \msb\ cleared (\z0).
	\item Devices MAY implement an escape code mechanism which does not otherwise violate the above rules to represent arbitrary
		8-bit values in the data packet, which will be translated as the packet passes through the transport layer.
	\item Following this header, the remaining bytes of the packet are the application-layer command as documented later
		in this document. No trailing bytes are added to the end of the packet (unlike \acronym{USB}).
\end{itemize}

The specifics of how these rules translate to various packet headers are described in detail below.

\subsubsection{Single Target or All Readerboards}
To send a command to a single sign, the \ltp\ packet header is a single byte encoded as:
\begin{center}
	\begin{bytefield}[endianness=big]{8}
		\bitheader{0-7} \\
		\bitbox{1}{\z{1}}&
		\bitbox[tbl]{1}{\z0}&
		\bitbox[tb]{1}{\z0}&
		\bitbox[tbr]{1}{\z1}&
		\bitbox{4}{\Var*{ad}}
	\end{bytefield}
\end{center}
where \Var*{ad} is the sign's address on the bus, which must be a value in the
range 0--15. This byte is followed by any command as described below. 
If the global address \Var{ad$_G$} is given as the \Var*{ad} value, then all readerboards
which have that set as their global address will obey the command.

\subsubsection{Multiple Targets}
Alternatively, a command may be targeted to multiple signs; in this case the \ltp\ packet header
is a multi-byte code:
\begin{center}
	\begin{bytefield}[endianness=big]{8}
		\bitheader{0-7} \\
		\bitbox{1}{\z{1}}&
		\bitbox[tbl]{1}{\z0}&
		\bitbox[tb]{1}{\z1}&
		\bitbox[tbr]{1}{\z1}&
		\bitbox{4}{\Var*{ad$_G$}}\\
		\bitbox{1}{\z0}&
		\bitbox{1}{\z0}&
		\bitbox{6}{\Var*{n}}\\
		\bitbox{1}{\z0}&
		\bitbox{1}{\z0}&
		\bitbox{6}{\Var*{ad$_0$}}\\
		\bitbox[]{8}{$\vdots$\strut}\\
		\bitbox{1}{\z0}&
		\bitbox{1}{\z0}&
		\bitbox{6}{\Var*{ad$_{n-1}$}}
	\end{bytefield}
\end{center}
where \Var*{ad$_G$} is the ``global'' device address which signals readerboards
generally (see the \z= command below).
This will send to the \Var*{n} devices addressed as \Var*{ad$_0$} through \Var*{ad$_{n-1}$}.

Note that device addresses are constrained to the range 0--15 if they are to be addressed in
the initial \ltp\ header start byte. However, using the multiple target header, device addresses in the
range 0--63 may be used.

%\subsubsection{All Targets}
%If you wish to send a command to all attached readerboards, simply send the
%following byte ahead of the command:
%\begin{center}
%	\begin{bytefield}[endianness=big]{8}
%		\bitheader{0-7} \\
%		\bitbox{1}{\z{1}}&
%		\bitbox[tbl]{1}{\z1}&
%		\bitbox[tb]{1}{\z0}&
%		\bitbox[tbr]{1}{\z1}&
%		\bitbox{4}{\Var*{ad$_G$}}
%	\end{bytefield}
%\end{center}
%where \Var*{ad$_G$} is the ``global'' device address which signals readerboards
%generally (see the \z= command below).

\subsubsection{Response Headers}
For commands which send a response back to the computer, the RS-485 response data stream begins with the \ltp\ header
\begin{center}
	\begin{bytefield}[endianness=big]{8}
		\bitheader{0-7} \\
		\bitbox{1}{\z1}&
		\bitbox[tbl]{1}{\z1}&
		\bitbox[tb]{1}{\z0}&
		\bitbox[tbr]{1}{\z1}&
		\bitbox{4}{\Var*{ad}}
	\end{bytefield}
\end{center}
where \Var*{ad} is the device address of the responding unit if \Var*{ad} $<$ 16. For devices with
higher-numbered addresses, the following extended format is used instead:
\begin{center}
	\begin{bytefield}[endianness=big]{8}
		\bitheader{0-7} \\
		\bitbox{1}{\z1}&
		\bitbox[tbl]{1}{\z1}&
		\bitbox[tb]{1}{\z1}&
		\bitbox[tbr]{1}{\z1}&
		\bitbox{4}{\Var*{ad$_{G}$}}\\
		\bitbox{1}{\z0}&
		\bitbox{7}{1}\\
		\bitbox{1}{\z0}&
		\bitbox{1}{\z0}&
		\bitbox{6}{\Var*{ad}}
	\end{bytefield}
\end{center}
\subsubsection{All Off}
As a special case, the single byte
\begin{center}
	\begin{bytefield}[endianness=big]{8}
		\bitheader{0-7} \\
		\bitbox{1}{\z{1}}&
		\bitbox[tbl]{1}{\z0}&
		\bitbox[tb]{1}{\z0}&
		\bitbox[tbr]{1}{\z0}&
		\bitbox{4}{\Var*{ad}}
	\end{bytefield}
\end{center}
will cause the readerboard addressed as \Var*{ad} to turn off all \led s.
If \Var*{ad} is the \Var{ad$_G$} address, then all readerboards will turn off
all \led s.

No other command bytes need to follow; this byte is sufficient to turn off
the sign(s). In other words, the \ltp\ packet header itself is all that is sent---the command payload is empty.

%The corresponding \acronym{JSON} message is
%\begin{Coding}
%|{"m":"off","a":[|\Var*{ad}|]}|
%\end{Coding}
The corresponding \acronym{HTTP} message is
\begin{Coding}
	|/readerboard/v1/alloff?a=|\Var*{ad}
\end{Coding}

\subsubsection{Subsequent Command Bytes}
All subsequent \ltp\ bytes which follow the above binary headers \emph{must} have their
\acronym{MSB} cleared to \z0. 

To cover cases where a value sent as part of a command must have the \acronym{MSB}
set, we use the following escape codes:
\begin{itemize}
	\item A hex byte \z{7E}$_{16}$ causes the next byte received to have its
		\acronym{MSB} set upon receipt.
	\item A hex byte \z{7F}$_{16}$ causes the next byte to be accepted without
		any further interpretation.
\end{itemize}
Thus, the byte \z{C4}$_{16}$ is sent as the two-byte sequence \z{7E~44},
while a literal \z{7E} is sent as \z{7F~7E} and a literal \z{7F} as \z{7F~7F}.

If there is an error parsing or executing a command, the readerboard will ignore
all subsequent input until a byte arrives with its \acronym{MSB} set to \z1,
whereupon it will expect to see the start of another command. 

A few illustrative examples are shown in Table~\ref{tbl:escapes}.
\begin{table}
	\begin{center}
		\begin{tabular}{ll}\toprule
			\multicolumn{1}{c}{\bfseries Input Sequence}&
			\multicolumn{1}{c}{\bfseries Resulting Byte}\\\midrule
			\z{00}    & \z{00} \\
			\z{7D}    & \z{7D} \\
			\z{7F 7E} & \z{7E} \\
			\z{7F 7F} & \z{7F} \\
			\z{7E 00} & \z{80} \\
			\z{7E 01} & \z{81} \\
			\z{7E 7D} & \z{FD} \\
			\z{7E 7E} & \z{FE} \\
			\z{7E 7F} & \z{FF} \\\bottomrule
		\end{tabular}
		\caption{Examples of RS-485 Escape Bytes.\label{tbl:escapes}}
	\end{center}
\end{table}

\section{Application Layer}
Once a command packet has been received and has been processed up through the transport layer, the remaining
contents of the packet are interpreted by the target device as the command to be carried out. In the descriptions
that follow, we will consider the matter of how the packet got to the device to have been fully resolved already
so no mention will be made of the transport protocol. Assume the \acronym{RS-485} header or \acronym{USB} trailer
have been removed at this point.

Commands which contain arbitrary-size data fields, such as text strings or lists of
\led s to light in sequence, end such fields with a terminator byte. In most cases
this may be
either a dollar-sign (``\z{\$}'') character or the
escape control character (hex byte \z{1B}$_{16}$), indicated in the protocol diagrams below
simply as ``\z{\$}''. In cases where a dollar-sign could be part of the data, then
only an escape character may be used to terminate the field, in which case the protocol
description will show the terminator as ``\z{ESC}''.

%\section{Command Addressing}
%Commands may be received over the \acronym{USB} port (a point-to-point connection with a host computer)
%or the RS-485 port (as part of a network of devices all connected to a single host computer's port).
%Commands received over the \acronym{USB} port \mc{MAY} be prefixed by an address specifier as described
%below. Those received over the RS-485 network \mc{MUST} have such a prefix (unless 
%using Lumos-compatible mode as described below).
%
%The address specifier prefix has the form:
%\begin{center}
%\begin{bytefield}[endianness=little,bitwidth=0.11111\textwidth]{9}
%	\bitbox[]{1}{\scriptsize0}&
%	\bitbox[]{1}{\scriptsize1}&
%	\bitbox[]{1}{\scriptsize\dots}&
%	\bitbox[]{1}{\scriptsize$n$}&
%	\bitbox[]{1}{\scriptsize$n+1$}\\
%	\bitbox{1}{\z{/}} &
%	\bitbox[tbl]{1}{\Var*{ad$_0$}}&
%	\bitbox[tb]{1}{$\cdots$}&
%	\bitbox[tbr]{1}{\Var*{ad$_{n-1}$}}&
%	\bitbox{1}{\z{\$}}
%\end{bytefield}
%\end{center}
%
%The \Var*{ad} parameters give the address(es) of the sign(s) which should obey the following
%command. Each is a value from 0--63 encoded as shown in Table~\ref{tbl:int063}. If the list of
%addresses is empty,
%all signs should respond to the command. The address list
%terminator may be a dollar-sign or escape
%character (hex byte \z{1B}), indicated in the protocol description as \z{\$}.
%
%If sent over the \acronym{USB} port, the address prefix is allowed but ignored, and the readerboard
%acts as if all commands are addressed to it, since the commands are received over a private connection
%between the host and that readerboard.
%
%If sent over the RS-485 port, the following escape codes are recognized.
%To send a byte value greater than 127, it is necessary to send it as the two-byte sequence:
%\begin{center}
%	\begin{bytefield}[endianness=big]{8}
%		\bitheader{0-7} \\
%		\bitbox{1}{\z0}&
%		\bitbox[tbl]{1}{\z1}&
%		\bitbox[tb]{1}{\z1}&
%		\bitbox[tb]{1}{\z1}&
%		\bitbox[tb]{1}{\z1}&
%		\bitbox[tb]{1}{\z1}&
%		\bitbox[tb]{1}{\z1}&
%		\bitbox[tbr]{1}{\z0}\\
%		\bitbox{1}{\z0}&
%		\bitbox{7}{\Var*{x}}
%	\end{bytefield}
%\end{center}
%This accepts the byte \Var*{x}, with its \acronym{MSB} set to \z1.
%
%To send a literal value of \z{7E}$_{16}$ rather than having it start the above
%escape, simply start with the other escape sequence:
%\begin{center}
%	\begin{bytefield}[endianness=big]{8}
%		\bitheader{0-7} \\
%		\bitbox{1}{\z0}&
%		\bitbox[tbl]{1}{\z1}&
%		\bitbox[tb]{1}{\z1}&
%		\bitbox[tb]{1}{\z1}&
%		\bitbox[tb]{1}{\z1}&
%		\bitbox[tb]{1}{\z1}&
%		\bitbox[tb]{1}{\z1}&
%		\bitbox[tbr]{1}{\z1}\\
%		\bitbox{1}{\z0}&
%		\bitbox{7}{\Var*{y}}
%	\end{bytefield}
%\end{center}
%This accepts the byte \Var*{y}, without interpreting it further. Thus, to send
%the hex byte \z{7E}, you send the two bytes \z{7F~7E}. To send a literal \z{7F}
%byte, send the two bytes \z{7F~7F}.
%
%The readerboard \acronym*{MAY} accept 8-bit values in the range 128--255 (hex
%\z{80}--\z{FF}) without using these escape codes, but this will confuse any other
%Lumos-compatible devices on the same serial network with them, so the best practice
%is to always use these escape codes for any value greater than or equal to 126 (hex
%\z{7E}). If using with other Lumos devices, you \acronym*{MUST} do so.
%
%\section{Lumos Compatibility}
%The readerboard may be connected to an RS-485 network that includes Lumos-protocol
%devices.\footnote{These include the Lumos power control boards and quiz show equipment
%created by the author.} 
%
%In this case, readerboard commands must begin with a start byte in the form
%\begin{center}
%	\begin{bytefield}[endianness=big]{8}
%		\bitheader{0-7} \\
%		\bitbox{1}{\z{1}}&
%		\bitbox{3}{\Var*{cmd}}&
%		\bitbox{4}{\Var*{ad$_0$}}
%	\end{bytefield}
%\end{center}
%and the address \Var*{ad$_0$} must be in the range 0--15. In this mode, all following
%bytes sent to the readerboard must have their \acronym{MSB} cleared (\z0).
%
%Only two \Var*{cmd} values are recognized by the readerboard.  For compatibility with
%other Lumos devices which recognize \Var*{cmd}=0 to mean turn off all output, the single-byte command
%\begin{center}
%	\begin{bytefield}[endianness=big]{8}
%		\bitheader{0-7} \\
%		\bitbox{1}{\z1}&
%		\bitbox[tbl]{1}{\z0}&
%		\bitbox[tb]{1}{\z0}&
%		\bitbox[tbr]{1}{\z0}&
%		\bitbox{4}{\Var*{ad$_0$}}
%	\end{bytefield}
%\end{center}
%will cause the readerboard addressed as \Var*{ad$_0$} to immediately turn off all
%\led s.
%
%For any other readerboard command, the start byte must be
%\begin{center}
%	\begin{bytefield}[endianness=big]{8}
%		\bitheader{0-7} \\
%		\bitbox{1}{\z{1}}&
%		\bitbox[tbl]{1}{\z1}&
%		\bitbox[tb]{1}{\z0}&
%		\bitbox[tbr]{1}{\z1}&
%		\bitbox{4}{\Var*{ad$_0$}}
%	\end{bytefield}
%\end{center}
%
%This may be followed by an address specifier (starting with a ``\z/'' character)
%documented above to include more sign addresses other than \Var*{ad$_0$}. If no such
%specifier is sent, then only sign \Var*{ad$_0$} will act on the command. If an empty
%specifier is sent, then \emph{all} signs will act on it.
%
%That is
%then followed by any of the readerboard commands documented below.\footnote{This
%is cheating just a little bit but is based on the assumption that no other Lumos
%device on any address will have \Var*{cmd} value 5 with the next byte being a
%``\z/'' character followed by zero or more encoded values 0--63 and an escape or
%dollar-sign.}
%
%\section{Command Termination and Error Handling}
%The command terminator is ``\z{\textasciicircum D}'' (hex byte value \z{04}). %We
%%\emph{recommend} that every command---or group of commands which together represent
%%a logical update to the sign---be followed by a \z{\textasciicircum D} character.
%This character \emph{must} follow each readerboard command, since the interpretation
%of the next command won't start until receipt of the 
%\z{\textasciicircum D},
%effectively
%ignoring any data sent after the end of the command and before the terminating
%\z{\textasciicircum D}.
%
%The exception to this rule is the set of Busylight-compatible commands
%\z*,
%\z?,
%\z{F},
%\z{S},
%and
%\z{X}.
%Since the Busylight unit did not use any command terminator in its protocol, the readerboard
%unit won't demand one either, although we \emph{recommend} that you do anyway. At the very least,
%you should have a
%\z{\textasciicircum D}
%character sent after a sequence of one or more Busylight-compatible commands.
%
%%The individual commands are executed immediately upon receipt, without requiring the
%%\z{\textasciicircum D} byte. For example, in the sequence ``\z{H1H2H3\textasciicircum D}''
%%the first bar graph data point will be displayed as soon as ``\z{H1}'' is received.
%
%In case of an error, such as the inability to parse the incoming command or an invalid
%field value, the readerboard will signal the error condition by lighting the white and
%both red discrete \led s, and will then ignore all input until the next
%\z{\textasciicircum D} byte is received.
%
%Whenever a \z{\textasciicircum D} byte is received, any command being parsed is aborted
%and the sign's input parser is reset. Thus, this byte may be sent in case a partial command
%has been sent but the host becomes aware that it cannot be completed. Note that the command
%may have been partially acted upon by that point, so no assumption should be made as to the
%sign's state.
%
%In the descriptions that follow, a trailing \z{\textasciicircum D} is shown at the end
%of each command to remind you of the recommendation to send this terminator, even though
%the commands themselves do not require them, strictly speaking.

\section{Command Summary}
The eight discrete \led s are intended for a simple display of status information
in a manner analogous to the Busylight project by the same author.\footnote{See
\href{https://github.com/MadScienceZone/busylight}{github.com/MadScienceZone/busylight}.}
To support this usage, the \z{F}, \z{S}, \z{X}, \z*, and \z? commands are recognized
in a manner compatible with how Busylight uses those same commands. These are categorized
as ``Busylight compatibility commands.'' Unlike all other commands listed here, these are
recognized regardless of case.  Since the readerboard has a power supply capable of illuminating
all of the status \led s at once,\footnote{The Busylight cannot, since it is powered
from the host computer's \acronym{USB} port.} a new command \z{L} is added which allows any
arbitrary pattern of steady \led s to be turned on.

The remaining commands are used for management of the matrix display. All commands are summarized in Table~\ref{tbl:commands}.
\begin{table}
	\begin{center}
		\begin{tabular}{lcll}\toprule
			\multicolumn{1}{c}{\bfseries Message}&
			\multicolumn{1}{c}{\bfseries Cmd}&
			\multicolumn{1}{c}{\bfseries Description}&
			\multicolumn{1}{c}{\bfseries Notes}\\\midrule
			\z{alert}&\z{!} & Briefly flash set of \led s & [3] \\
			\z{strobe}&\z{*} & Strobe \led s in Sequence & [1]\\
			\z{busy}&\z{?} & Query discrete \led\ status & [1] [2] [5]\\
			\z{flash}&\z{F} & Flash \led s in Sequence & [1]\\
			\z{light}&\z{L} & Light one or more \led s steady & [3]\\
			\z{light}&\z{S} & Light one \led\ steady & [1]\\
			\z{off}&\z{X} & All \led s off & [1]\\
			\midrule
			&\z{\textasciicircum D} & Abort/terminate command & \\
			\z{test}&\z{\%T@} & Full lamp test & \\
			\z{scroll}&\z{<} & Scroll text across display & \\
			\z{configure-device}&\z{=} & Set operational parameters &[4] [5]\\
			\z{diag-banners}&\z{=*}&Display POST banners&\\
			\z{save}&\z{=\&}&Persist Settings in EEPROM&\\
			&\z{=\#}&Set serial number & [4] [5]\\
			\z{move}&\z{@} & Move current column cursor & \\
			\z{font}&\z{A} & Select character font & \\
			\z{sound}&\z{B}&Beep / Play sounds&\\
			\z{clear}&\z{C} & Clear matrix display & \\
			\z{dim}&\z{D}&Set light dimmer levels & \\
			\z{graph}&\z{H} & Add histogram/bargraph data point & \\
			\z{bitmap}&\z{I} & Draw bitmap graphic image & \\
			\z{color}&\z{K} & Set current color & \\
			\z{morse}&\z{M}&Send message via Morse code&\\
			\z{query}&\z{Q} & Query full device status & [2] [5]\\
			\z{text}&\z{T} & Display text on matrix & \\
			\z{alpha}&\z{V} & Manipulate segmented LED display & [6]\\
			\midrule
			\z{current}&& Report current status display& \\
			\z{post}&& Add queued display message& \\
			\z{postlist}&& Report queued display message(s)& \\
			\z{unpost}&& Remove queued display message(s)& \\
			\z{update}&& Update user-defined variables& \\
			\bottomrule
			\multicolumn{4}{p{\textwidth}}{\tiny[1] Busylight compatibile command

			\noindent[2] Sends response

			\noindent[3] Busylight extension (not in original Busylight)

			\noindent[4] \acronym{USB} only

			\noindent[5] Must be targeted to a specific device at a time; does not respond on the global address

			\noindent[6] On supported hardware only}
		\end{tabular}
		\caption{Summary of All Commands\label{tbl:commands}}
	\end{center}
\end{table}

\section{\z{\%T@}---Run Full Lamp Test Pattern}
\begin{center}
\begin{bytefield}[endianness=little,bitwidth=0.11111\textwidth]{1}
	\bitheader{0-2} \\
	\bitbox{1}{\z{\%}} &
	\bitbox{1}{\z{T}} &
	\bitbox{1}{\z{@}} 
\end{bytefield}
\\
%|{"m":"clear","a":[|\Var*{ad$_0$}|,|\dots|]}|
\begin{Coding}
	|/readerboard/v1/test?a=|\Var*{ad}
\end{Coding}
\end{center}

Displays various test patterns on the display to show that each element of each \led\ is working correctly
individually and in concert with others.

While running the test pattern set, the device is not responsive to other inputs or background operations.

\section{\z{!}---Alert Signal on Discrete Lights}
\begin{center}
\begin{bytefield}[endianness=little,bitwidth=0.11111\textwidth]{7}
%	\bitheader{0-3} \\
	\bitbox[]{1}{\scriptsize0}&
	\bitbox[]{1}{\scriptsize1}&
	\bitbox[]{1}{\scriptsize2}&
	\bitbox[]{1}{\scriptsize3}&
	\bitbox[]{1}{\scriptsize\dots}&
	\bitbox[]{1}{\scriptsize$n$}&
	\bitbox[]{1}{\scriptsize$n+1$}\\
	\bitbox{1}{\z{!}} &
	\bitbox[tlb]{1}{\Var*{led$_0$}} &
	\bitbox[tb]{1}{\Var*{led$_1$}} &
	\bitbox[tb]{1}{\Var*{led$_2$}} &
	\bitbox[tb]{1}{$\cdots$} &
	\bitbox[tbr]{1}{\Var*{led$_{n-1}$}} &
	\bitbox{1}{\z\$}
\end{bytefield}
\begin{Coding}
|/readerboard/v1/alert?a=|\Var*{ad}|&l=|\Var*{led$_0$}\Var*{led$_1$}\dots\Var*{led$_{n-1}$}
\end{Coding}
\end{center}

Each \Var*{led} value is an \ascii\ character corresponding to a discrete
\led\ as shown in Table~\ref{tbl:lightcodes}. 

All of the \led s in the list are flashed briefly together to indicate an urgent status, after which
the previous state of the discrete \led\ display is restored.

{\color{red} Not yet implemented.}

\section{\z{*}---Strobe Lights in Sequence}
\begin{center}
\begin{bytefield}[endianness=little,bitwidth=0.11111\textwidth]{7}
%	\bitheader{0-3} \\
	\bitbox[]{1}{\scriptsize0}&
	\bitbox[]{1}{\scriptsize1}&
	\bitbox[]{1}{\scriptsize2}&
	\bitbox[]{1}{\scriptsize3}&
	\bitbox[]{1}{\scriptsize\dots}&
	\bitbox[]{1}{\scriptsize$n$}&
	\bitbox[]{1}{\scriptsize$n+1$}\\
	\bitbox{1}{\z{*}} &
	\bitbox[tlb]{1}{\Var*{led$_0$}} &
	\bitbox[tb]{1}{\Var*{led$_1$}} &
	\bitbox[tb]{1}{\Var*{led$_2$}} &
	\bitbox[tb]{1}{$\cdots$} &
	\bitbox[tbr]{1}{\Var*{led$_{n-1}$}} &
	\bitbox{1}{\z\$}
\end{bytefield}
%%%%%%%%%	|{"m":"strobe","a":[|\Var*{ad$_0$}|,|\dots|],"l":[|\Var*{led$_0$}|,|\Var*{led$_1$}|,|\dots|,|\Var*{led$_{n-1}$}|]}|
\begin{Coding}
|/readerboard/v1/strobe?a=|\Var*{ad}|&l=|\Var*{led$_0$}\Var*{led$_1$}\dots\Var*{led$_{n-1}$}
\end{Coding}
\end{center}

Each \Var*{led} value is an \ascii\ character corresponding to a discrete
\led\ as shown in Table~\ref{tbl:lightcodes}. An \Var*{led} value of ``\z{\_}'' means
there is no \led\ illuminated at that point in the sequence.

This command functions identically to the \z{F} command (see below), except that the lights
are ``strobed'' (flashed very briefly with a pause between each light in the sequence).

\section{\z<---Scroll Text Across Display}
\begin{center}
\begin{bytefield}[endianness=little,bitwidth=0.11111\textwidth]{8}
%	\bitheader{0-8} \\
	\bitbox[]{1}{\scriptsize0}&
	\bitbox[]{1}{\scriptsize1}&
	\bitbox[]{1}{\scriptsize2}&
	\bitbox[]{3}{\scriptsize\dots}&
	\bitbox[]{1}{\scriptsize$n$+1}&
	\bitbox[]{1}{\scriptsize$n$+2}\\
	\bitbox{1}{\z{<}} &
	\bitbox{1}{\Var*{loop}}&
	\bitbox{5}{\Var*{string}}&
	\bitbox{1}{\z{ESC}}
\end{bytefield}

\smallskip

\begin{bytefield}[endianness=little,bitwidth=0.11111\textwidth]{8}
%	\bitheader{0-8} \\
	\bitbox[]{1}{\scriptsize0}&
	\bitbox[]{1}{\scriptsize1}&
	\bitbox[]{1}{\scriptsize2}&
	\bitbox[]{1}{\scriptsize3}&
	\bitbox[]{1}{\scriptsize4}&
	\bitbox[]{1}{\scriptsize5}&
	\bitbox[]{1}{\scriptsize\dots}&
	\bitbox[]{1}{\scriptsize$n$+4}&
	\bitbox[]{1}{\scriptsize$n$+5}\\
	\bitbox{1}{\z{<}} &
	\bitbox{1}{\z{@}} &
	\bitbox{1}{\Var*{row}}&
	\bitbox{1}{\Var*{height}}&
	\bitbox{1}{\Var*{loop}}&
	\bitbox{3}{\Var*{string}}&
	\bitbox{1}{\z{ESC}}
\end{bytefield}

\medskip

%|{"m":"scroll","a":[|\Var*{ad$_0$}|,|\dots|],"loop":|\Var*{bool}|,"t":|\Var*{string}|}|
\begin{Coding}
	|/readerboard/v1/scroll?a=|\Var*{ad}|&loop=|\Var*{bool}|&t=|\Var*{string}\\
	|&row=|\Var*{row}|&height=|\Var*{height}
\end{Coding}
\end{center}

In the second form, the \Var*{row} and \Var*{height} parameters define a region of the display that extends to the full width of the
display but includes \Var*{height} pixel rows starting at pixel \#\Var*{row} (with row \#0 being the topmost row of the device). In this
case, the command behaves as though this region is the only part of the sign that exists as far as where characters will be drawn and
scrolled through. {\color{red} Not yet implemented. May be limitations on how many simultaneous
transition effects may be playing at once, including scrolling text.}

Displays the text \Var*{string} by scrolling it across the display from right to left.
If \Var*{loop} is ``\z.'', the text is only scrolled once; if it is ``\z{L}'' then it
repeatedly scrolls across the screen in an endless loop.

The text is rendered in the current font and may contain any 8-bit bytes except as otherwise
noted (but avoiding \ascii\ control codes is wise to be safe from conflict with
future control codes which may be added to the protocol). The string is terminated by an
escape character (hex byte \z{1B}$_{16}$), indicated in the protocol description as \z{ESC}.

The string may include control codes as listed in Table~\ref{tbl:controlcodes}. These allow
for special effects such as color and font changes to appear mid-message. They also include
the three-character sequence \z{\textasciicircum X}\Var*{hh} to add any arbitrary 8-bit codepoint
specified as the 2-digit hex value \Var*{hh} to compensate for interference from your terminal
program or transport protocols which may, e.g., encode non-7-bit-\acronym{ASCII} characters
to a multi-byte \acronym{UTF-8} representation which the readerboard doesn't grok.
\begin{table}
	\begin{center}
		\begin{tabular}{lll}\toprule
			\multicolumn{1}{c}{\bfseries Code} &
			\multicolumn{1}{c}{\bfseries Hex} &
			\multicolumn{1}{c}{\bfseries Description} \\\midrule
			\z{\textasciicircum @} & \z{00} & Never allowed in strings (null byte)\\
			\z{\textasciicircum C}\Var*{pos} & \z{03}\Var*{pos} & Move current column cursor to \Var*{pos}\\
			\z{\textasciicircum D} & \z{04} & Never allowed in strings (command terminator)\\
			\z{\textasciicircum F}\Var*{digit} & \z{06}\Var*{digit} & Switch current font\\
			\z{\textasciicircum H}\Var*{pos} & \z{08}\Var*{pos} & Move cursor left \Var*{pos} columns\\
			\z{\textasciicircum J}\Var*{pos} & \z{0A}\Var*{pos} & Move cursor down \Var*{pos} rows\\
			\z{\textasciicircum K}\Var*{rgb} & \z{0B}\Var*{rgb} & Change color to \Var*{rgb}\\
			\z{\textasciicircum L}\Var*{pos} & \z{0C}\Var*{pos} & Move cursor right \Var*{pos} columns\\
			\z{\textasciicircum U}\Var*{pos} & \z{15}\Var*{pos} & Move cursor up \Var*{pos} rows\\
			\z{\textasciicircum X}\Var*{hex} & \z{18}\Var*{hex} & Specify character code as 2-digit hex value\\
			\z{\textasciicircum [} & \z{1B} & Never allowed in strings (string terminator)\\
			\bottomrule
		\end{tabular}
		\caption{Control Codes in String Values\label{tbl:controlcodes}}
	\end{center}
\end{table}

\section{\z{=}---Set Operational Parameters}
\begin{center}
\begin{bytefield}[endianness=little,bitwidth=0.11111\textwidth]{8}
%	\bitheader{0-3} \\
	\bitbox[]{1}{\scriptsize0}&
	\bitbox[]{1}{\scriptsize1}&
	\bitbox[]{1}{\scriptsize2}&
	\bitbox[]{1}{\scriptsize3}&
	\bitbox[]{1}{\scriptsize4}\\
	\bitbox{1}{\z{=}} &
	\bitbox{1}{\Var*{ad$'$}}&
	\bitbox{1}{\Var*{uspd}}&
	\bitbox{1}{\Var*{rspd}}&
	\bitbox{1}{\Var*{ad$_{G}'$}}
\end{bytefield}
\\
\begin{Coding}
	|/readerboard/v1/configure-device?a=|\Var*{ad}|&rspeed=|\Var*{baud}\\
	|&uspeed=|\Var*{baud}|&address=|\Var*{ad$'$}|&global=|\Var*{ad$_{G}'$}
\end{Coding}
\end{center}

This command sets a few operational parameters for the sign. Once set, these will be persistent across
power cycles and reboots.

If the \Var*{ad$'$} parameter is ``\z{.}'' then the RS-485 interface is disabled entirely. Otherwise it is a
value from 0--63 encoded as described in Table~\ref{tbl:int063}. This enables the RS-485 interface and assigns
this sign's address to \Var*{ad$'$}. (In the \acronym{HTTP} \acronym{API}, use ``\z{address=\_}'' to indicate this.)

The baud rate for the \acronym{USB} and RS-485 interfaces is set by the \Var*{uspd} and \Var*{rspd} values
respectively. Each is encoded as per Table~\ref{tbl:baudcodes}.

The \Var*{ad$_{G}'$} value is an address in the range 0--15 which is not assigned
to any other device on the RS-485 network. This is used to signal that all
readerboards should pay attention to the start of the command because it might
target them either as part of a list of specific readerboards or because the
command is intended for all readerboards at once. This is encoded in the 
same way as \Var*{ad$'$}.
%If you only have one readerboard or do not wish to assign a global address,
%just set \Var*{ad$_{G}'$} to the same value as \Var*{ad$'$}.

This command may only be sent over the \acronym{USB} port.

By default, an unconfigured readerboard is set to 9,600 baud with the RS-485 port disabled, but these
defaults may be changed when compiling the firmware for specific devices.
\begin{table}
	\begin{center}
		\begin{tabular}{crl}\toprule
			\bfseries Code & \multicolumn{1}{c}{\bfseries Speed} \\\midrule
			0 & 300\\
			1 & 600\\
			2 & 1,200\\
			3 & 2,400\\
			4 & 4,800\\
			5 & 9,600 & (default)\\
			6 & 14,400\\
			7 & 19,200\\
			8 & 28,800\\
			9 & 31,250\\
			A & 38,400\\
			B & 57,600\\
			C & 115,200\\
		\bottomrule
		\end{tabular}
		\caption{Baud Rate Codes\label{tbl:baudcodes}}
	\end{center}
\end{table}

\section{\z{=\#}---Set Serial Number}
\begin{center}
\begin{bytefield}[endianness=little,bitwidth=0.11111\textwidth]{8}
%	\bitheader{0-3} \\
	\bitbox[]{1}{\scriptsize0}&
	\bitbox[]{1}{\scriptsize1}&
	\bitbox[]{1}{\scriptsize2}&
	\bitbox[]{1}{\scriptsize\dots}\\
	\bitbox{1}{\strut\z{=}} &
	\bitbox{1}{\strut\z{\#}} &
	\bitbox{3}{\strut\Var*{Serial}}&
	\bitbox{1}{\strut\z{\$}} &
	\bitbox{1}{\strut\z{\#}} &
	\bitbox{1}{\strut\z{=}} &
\end{bytefield}
\end{center}

To avoid recompiling the firmware image for every single device, the serial number
may be set in the field using this command. The serial number is stored in
\acronym{EEPROM}, so it won't be persistent on units that are not equipped with
\acronym{EEPROM}.

This command may only be sent over the \acronym{USB} port.

The serial number may be arbitrary alphanumeric text of up to six characters.
Numbers \z{RB0000}--\z{RB0299} and \z{B00000}--\z{B00299} are reserved for use by the author.

\section{\z{=*}---Display POST Banners}
\begin{center}
\begin{bytefield}[endianness=little,bitwidth=0.11111\textwidth]{8}
	\bitheader{0-2} \\
	\bitbox{1}{\strut\z{=}} &
	\bitbox{1}{\strut\z{*}} &
	\bitbox{1}{\strut\z{=}} 
\end{bytefield}
\\
\begin{Coding}
	|/readerboard/v1/diag-banners?a=|\Var*{ad}
\end{Coding}
\end{center}

Causes the readerboard to display the same banners as it does during power-on self-test.
Busylights don't display the equivalent series of messages when they power up, but if you
send them this command they will send the same information as the readerboard \acronym{POST} banners,
but will do so by flashing out the information in Morse code on the bottom \led.

\section{\z{=\&}---Persist Settings in EEPROM}
\begin{center}
\begin{bytefield}[endianness=little,bitwidth=0.11111\textwidth]{8}
	\bitheader{0-3} \\
	\bitbox{1}{\strut\z{=}} &
	\bitbox{1}{\strut\z{\&}} &
	\bitbox{1}{\strut\Var*{type}} &
	\bitbox{1}{\strut\z{=}} 
\end{bytefield}
\\
\begin{Coding}
	|/readerboard/v1/save?a=|\Var*{ad}|&type=|\Var*{type}
\end{Coding}
\end{center}

Saves current system state in \acronym{EEPROM} so they remain in effect across reboots.
Currently, the only supported \Var*{type} is ``\z{D}'' which saves the current dimmer settings.

\section{\z?---Query Discrete \led\ Status}
\begin{center}
\begin{bytefield}[endianness=little,bitwidth=0.11111\textwidth]{1}
	\bitheader{0} \\
	\bitbox{1}{\z{?}}
\end{bytefield}
\\
\begin{Coding}
	|/readerboard/v1/busy?a=|\Var*{ad}
\end{Coding}
\end{center}

This command causes the sign to send a status report back to the host to indicate
what the discrete \led s (usually showing a person's ``busy'' status) are currently showing. 

This cannot be sent to the global device address, although you can request the server
to query the global address in which case it will individually poll each device.

This response has the form:

\medskip

\begin{center}\begin{bytefield}[endianness=little,bitwidth=0.11111\textwidth]{9}
	\bitheader{0-8} \\
	\bitbox[ltb]{1}{\z{L}} &
	\bitbox[rtb]{1}{\z0} &
	\bitbox[tbl]{1}{\Var*{led$_0$}} &
	\bitbox[tb]{1}{\Var*{led$_1$}} &
	\bitbox[tb]{1}{\Var*{led$_2$}} &
	\bitbox[tb]{1}{\Var*{led$_3$}} &
	\bitbox[tb]{1}{\Var*{led$_4$}} &
	\bitbox[tb]{1}{\strut$\cdots$} &
	\bitbox[tbr]{1}{\Var*{led$_{n-1}$}} \\
	\bitbox{1}{\z{\$}} &
	\bitbox{1}{\z{F}} &
	\bitbox{6}{flasher status (see below)} &
	\bitbox{1}{\z{\$}} \\
	\bitbox{1}{\z{S}} &
	\bitbox{6}{strober status (see below)} &
	\bitbox{1}{\z{\$}} &
	\bitbox{1}{\z{\textbackslash n}}
\end{bytefield}
\end{center}

The initial bytes ``\z{L0}'' identify the format of the data that follows. If the format changes
in a way that breaks the previous parsing rules, the ``\z0'' will be incremented according to the
conventions of 6-bit integer encoding as described in Table~\ref{tbl:int063}.

Each \Var*{led$_x$} value is a single character which is ``\z{\_}'' if the corresponding \led\ is
off, or the \led's color code or position number if it is on. One such value is sent for each \led\ installed
in the sign (typically eight for readerboards), followed by a ``\z{\$}'' to mark the end of the list.

The flasher and strober status values are variable-width fields which indicate the
state of the flasher (see \z{F} command) and strober (see \z{*} command) functions.
In each case, if there is no defined sequence, the status field will be:

\medskip

\begin{center}\begin{bytefield}[endianness=little,bitwidth=0.11111\textwidth]{2}
	\bitheader{0-1} \\
	\bitbox{1}{\Var*{run}} &
	\bitbox{1}{\strut\z{\_}}
\end{bytefield}

\smallskip

or

\smallskip

\begin{bytefield}[endianness=little,bitwidth=0.11111\textwidth]{7}
%	\bitheader{0-6} \\
	\bitbox[]{1}{\scriptsize0}&
	\bitbox[]{1}{\scriptsize1}&
	\bitbox[]{1}{\scriptsize2}&
	\bitbox[]{1}{\scriptsize3}&
	\bitbox[]{1}{\scriptsize4}&
	\bitbox[]{1}{\scriptsize5}&
	\bitbox[]{1}{\scriptsize6}\\
	\bitbox{1}{\z{/}} &
	\bitbox{1}{\Var*{up}} &
	\bitbox{1}{\Var*{on}} &
	\bitbox{1}{\Var*{down}} &
	\bitbox{1}{\Var*{off}} &
	\bitbox{1}{\Var*{run}} &
	\bitbox{1}{\strut\z{\_}}
\end{bytefield}

\end{center}

\smallskip

\noindent Otherwise, the state of the flasher or strober unit is indicated by:

\medskip

\begin{center}
	\begin{bytefield}[endianness=little,bitwidth=0.11111\textwidth]{7}
%	\bitheader{0-6} \\
	\bitbox[]{1}{\scriptsize0}&
	\bitbox[]{1}{\scriptsize1}&
	\bitbox[]{1}{\scriptsize2}&
	\bitbox[]{1}{\scriptsize3}&
	\bitbox[]{1}{\scriptsize4}&
	\bitbox[]{1}{\scriptsize\dots}&
	\bitbox[]{1}{\scriptsize$n+3$}\\
	\bitbox{1}{\Var*{run}} &
	\bitbox{1}{\Var*{pos}} &
	\bitbox{1}{\z{@}} &
	\bitbox[tbl]{1}{\Var*{led$_0$}} &
	\bitbox[tb]{1}{\Var*{led$_1$}} &
	\bitbox[tb]{1}{$\cdots$} &
	\bitbox[tbr]{1}{\Var*{led$_{n-1}$}} 
\end{bytefield}

\smallskip

or

\smallskip

\begin{bytefield}[endianness=little,bitwidth=0.11111\textwidth]{7}
%	\bitheader{0-6} \\
	\bitbox[]{1}{\scriptsize0}&
	\bitbox[]{1}{\scriptsize1}&
	\bitbox[]{1}{\scriptsize2}&
	\bitbox[]{1}{\scriptsize3}&
	\bitbox[]{1}{\scriptsize4}&
	\bitbox[]{1}{\scriptsize5}&
	\bitbox[]{1}{\scriptsize6}&
	\bitbox[]{1}{\scriptsize7}\\
	\bitbox{1}{\z{/}} &
	\bitbox{1}{\Var*{up}} &
	\bitbox{1}{\Var*{on}} &
	\bitbox{1}{\Var*{down}} &
	\bitbox{1}{\Var*{off}} &
	\bitbox{1}{\Var*{run}} &
	\bitbox{1}{\Var*{pos}} &
	\bitbox{1}{\z{@}} \\
	\bitbox[tbl]{1}{\Var*{led$_0$}} &
	\bitbox[tb]{1}{\Var*{led$_1$}} &
	\bitbox[tb]{1}{$\cdots$} &
	\bitbox[tbr]{1}{\Var*{led$_{n-1}$}} 
\end{bytefield}
\end{center}

If the flasher has custom timings defined for it, a five-character block starting with ``\z{/}''
will appear at the start of the status and will contain the four timing values in the
same format as specified to the \z{F} command when they were set (q.v.).

In any case, \Var*{run} is the \ascii\ character ``\z{S}'' if the unit is
stopped or ``\z{R}'' if it is currently running.  If there is a defined sequence,
\Var*{pos} indicates the 0-origin position within the sequence of the light currently
being flashed or strobed, encoded as described in Table~\ref{tbl:int063}. 
The \Var*{led$_x$} values are as allowed for the \z{F} or \z{*}
command that set the sequence. (Regardless of the actual \z{F} or \z{*} command parameters,
the report will show symbolic color codes where possible, or numeric position codes otherwise.)

%Note that the \Var*{pos} value may be the character ``\z{X}'' to indicate the position
%value of 40, so it is important to distinguish between the field value
%``\Var*{run}\z{X}'' vs.\@ ``\Var*{run}\z{X@}\Var*{sequence}''.

The status message sent to the host is terminated by a newline character (hex byte \z{0A}),
indicated in the protocol description above as ``\z{\textbackslash n}''.
\begin{table}
	\begin{center}
		\begin{bytefield}[endianness=big,bitwidth=0.11111\textwidth]{8}
			\bitheader{0-7}\\
			\bitbox{1}{\z0} &
			\bitbox{1}{\z0} &
			\bitbox{1}{\z1} &
			\bitbox{1}{\z1} &
			\bitbox{4}{\Var*{n} \quad($n<16$)} \\
			\bitbox{1}{\z0} &
			\bitbox{1}{\z1} &
			\bitbox{6}{\Var*{n}--16 \quad($n\ge16$)}
		\end{bytefield}

		\medskip

		\begin{tabular}{cc|cc}\toprule
			\multicolumn{1}{c}{\bfseries Value} &
			\multicolumn{1}{c}{\bfseries Code} &
			\multicolumn{1}{c}{\bfseries Value} &
			\multicolumn{1}{c}{\bfseries Code} \\\midrule
			0--9 & \z0--\z9 & 17--42 & \z{A}--\z{Z} \\
			10 & \z: & 43 & \z[ \\
			11 & \z; & 44 & \z\textbackslash \\
			12 & \z< & 45 & \z] \\
			13 & \z= & 46 & \z\textasciicircum \\
			14 & \z> & 47 & \z{\_} \\
			15 & \z? & 48 & \z` \\
			16 & \z@ & 49--63 & \z{a}--\z{o} \\
			\bottomrule
		\end{tabular}

		{\footnotesize (Each code is the numeric value plus 48.)}
		\caption{\ascii\ Encoded Integer Values (0--63)\label{tbl:int063}}
	\end{center}
\end{table}

%This command may only be sent on the \acronym{USB} port.

\section{\z{@}---Set Column Cursor Position}
\begin{center}
\begin{bytefield}[endianness=little,bitwidth=0.11111\textwidth]{2}
	\bitheader{0-1} \\
	\bitbox{1}{\z{@}} &
	\bitbox{1}{\Var*{pos}} 
\end{bytefield}
\\
%|{"m":"move","a":[|\Var*{ad$_0$}|,|\dots|],"pos":|\Var*{col}|}|
\begin{Coding}
	|/readerboard/v1/move?a=|\Var*{ad}|&pos=|\Var*{pos}
\end{Coding}
\end{center}

Sets the column cursor position to the value indicated by \Var*{pos}. See Table~\ref{tbl:int063}. 
%(The \acronym{JSON} message uses integer values for \Var*{col} without the encoding used for \Var*{pos}.)

\section{\z{A}---Select Font}
\begin{center}
\begin{bytefield}[endianness=little,bitwidth=0.11111\textwidth]{2}
	\bitheader{0-1} \\
	\bitbox{1}{\z{A}} &
	\bitbox{1}{\Var*{digit}} 
\end{bytefield}
\\
%|{"m":"font","a":[|\Var*{ad$_0$}|,|\dots|],"idx":|\Var*{digit}|}|
\begin{Coding}
	|/readerboard/v1/font?a=|\Var*{ad}|&idx=|\Var*{digit}
\end{Coding}
\end{center}

Sets the font to use for rendering text with the \z< and \z{T} commands.
The font codes for \Var*{digit} are listed in Table~\ref{tbl:fontcodes}.
The full text fonts support the printable \ascii\ characters plus a majority
of the Unicode glyphs with codepoints less than 256.  See Tables~\ref{tbl:font0}--\ref{tbl:font3}
for a complete font glyph listing with codepoint assignments.

Font~3 is a double-height font which is really only useful on boards with 16 or more rows of \led s.

\begin{table}
	\begin{center}
		\begin{tabular}{ll}\toprule
			\multicolumn{1}{c}{\bfseries Code} &
			\multicolumn{1}{c}{\bfseries Font Description} \\\midrule
			\z0 & Fixed-width 5$\times$7 matrix plus descenders in 8th row \\
			\z1 & Variable-width version of font 0 \\
			\z2 & Bold alphanumerics and special symbols \\
			\bottomrule
		\end{tabular}
		\caption{Font Codes\label{tbl:fontcodes}}
	\end{center}
\end{table}
\begin{table}
	\begin{center}
		\begin{tabular}{r|c|c|c|c|c|c|c|c|l}
			&\emph{0} &\emph{1} &\emph{2} &\emph{3}
			&\emph{4} &\emph{5} &\emph{6} &\emph{7}&\\\hline
			\emph{00x}&\tForbidden\tiny null&\tUnused&\tUnused&\tControl\tiny move&\tForbidden\tiny end&\tUnused&\tControl\tiny font&\tUnused&\multirow{2}{*}{\z{0}\emph{x}}\\\cline{1-9}
			\emph{01x}&\tControl\tiny back&\tUnused&\tControl\tiny down&\tControl\tiny color&\tControl\tiny forw&\tUnused&\tUnused&\tUnused&\\\hline
			\emph{02x}&\tUnused&\tUnused&\tUnused&\tUnused&\tUnused&\tControl\tiny up&\tUnused&\tUnused&\multirow{2}{*}{\z{1}\emph{x}}\\\cline{1-9}
			\emph{03x}&\tControl\tiny hex&\tUnused&\tUnused&\tForbidden\tiny esc&\tUnused&\tUnused&\tUnused&\tUnused&\\\hline
			\emph{04x}&&!&\z"&\#&\$&\%&\&&\z'&\multirow{2}{*}{\z{2}\emph{x}}\\\cline{1-9}
			\emph{05x}&(&)&*&+&,&-&.&/&\\\hline
			\emph{06x}&0&1&2&3&4&5&6&7&\multirow{2}{*}{\z{3}\emph{x}}\\\cline{1-9}
			\emph{07x}&8&9&:&;&\z<&=&\z>&?&\\\hline
			\emph{10x}&@&A&B&C&D&E&F&G&\multirow{2}{*}{\z{4}\emph{x}}\\\cline{1-9}
			\emph{11x}&H&I&J&K&L&M&N&O&\\\hline
			\emph{12x}&P&Q&R&S&T&U&V&W&\multirow{2}{*}{\z{5}\emph{x}}\\\cline{1-9}
			\emph{13x}&X&Y&Z&[&\textbackslash&]&\textasciicircum&\_&\\\hline
			\emph{14x}&`&a&b&c&d&e&f&g&\multirow{2}{*}{\z{6}\emph{x}}\\\cline{1-9}
			\emph{15x}&h&i&j&k&l&m&n&o&\\\hline
			\emph{16x}&p&q&r&s&t&u&v&w&\multirow{2}{*}{\z{7}\emph{x}}\\\cline{1-9}
			\emph{17x}&x&y&z&\{&|&\}&\textasciitilde&///&\\\hline
			\emph{20x}&``&''&`&'&$\dagger$&$\ddagger$&\dots&$'$&\multirow{2}{*}{\z{8}\emph{x}}\\\cline{1-9}
			\emph{21x}&$''$&!!&$\overline{\hbox{\phantom{x}}}$&$\leftarrow$&$\rightarrow$&$\uparrow$&$\downarrow$&$\ne$&\\\hline
			\emph{22x}&$\le$&$\ge$&$\approx$&$\Gamma$&$\Delta$&$\Xi$&$\Pi$&$\Sigma$&\multirow{2}{*}{\z{9}\emph{x}}\\\cline{1-9}
			\emph{23x}&$\Omega$&$\pi$&$\rho$&$\sigma$&---&\textperthousand&\tUnused&\tUnused&\\\hline
			\emph{24x}&&!`&\textcent&\textsterling&\textcurrency&\textyen&\textbrokenbar&\S&\multirow{2}{*}{\z{A}\emph{x}}\\\cline{1-9}
			\emph{25x}&``&\textcopyright&\textordfeminine&\guillemotleft&$\neg$&-&\textregistered&\tUnused&\\\hline
			\emph{26x}&$^\circ$&$\pm$&$^2$&$^3$&\tUnused&$\mu$&\P&$\bullet$&\multirow{2}{*}{\z{B}\emph{x}}\\\cline{1-9}
			\emph{27x}&`&$^1$&\textordmasculine&\guillemotright&1/4&1/2&3/4&?`&\\\hline
			\emph{30x}&\`A&\'A&\^A&\~A&\"A&\AA&\AE&\c C&\multirow{2}{*}{\z{C}\emph{x}}\\\cline{1-9}
			\emph{31x}&\`E&\'E&\^E&\"E&\`I&\'I&\^I&\"I&\\\hline
			\emph{32x}&\DH&\~N&\`O&\'O&\^O&\~O&\"O&$\times$&\multirow{2}{*}{\z{D}\emph{x}}\\\cline{1-9}
			\emph{33x}&\O&\`U&\'U&\^U&\"U&\'Y&\TH&\ss&\\\hline
			\emph{34x}&\`a&\'a&\^a&\~a&\"a&\aa&\ae&\c c&\multirow{2}{*}{\z{E}\emph{x}}\\\cline{1-9}
			\emph{35x}&\`e&\'e&\^e&\"e&\`\i&\'\i&\^\i&\"\i&\\\hline
			\emph{36x}&\dh&\~n&\`o&\'o&\^o&\~o&\"o&$\div$&\multirow{2}{*}{\z{F}\emph{x}}\\\cline{1-9}
			\emph{37x}&\o&\`u&\'u&\^u&\"u&\'y&\th&\"y&\\\hline
%			&\emph{x}\z{0} &\emph{x}\z{1} &\emph{x}\z{2} &\emph{x}\z{3}
%			&\emph{x}\z{4} &\emph{x}\z{5} &\emph{x}\z{6} &\emph{x}\z{7}\\
			&\z{8} &\z{9} &\z{A} &\z{B}
			&\z{C} &\z{D} &\z{E} &\z{F}
		\end{tabular}
	\end{center}
	\caption{Font Table for Fonts \#0 and \#1\label{tbl:font0}}
\end{table}
\begin{table}
	\begin{center}
		\begin{tabular}{r|c|c|c|c|c|c|c|c|l}
			&\emph{0} &\emph{1} &\emph{2} &\emph{3}
			&\emph{4} &\emph{5} &\emph{6} &\emph{7}&\\\hline
			\emph{00x}&\tForbidden\tiny null&\tUnused&\tUnused&\tControl\tiny move&\tForbidden\tiny end&\tUnused&\tControl\tiny font&\tUnused&\multirow{2}{*}{\z{0}\emph{x}}\\\cline{1-9}
			\emph{01x}&\tControl\tiny back&\tUnused&\tControl\tiny down&\tControl\tiny color&\tControl\tiny forw&\tUnused&\tUnused&\tUnused&\\\hline
			\emph{02x}&\tUnused&\tUnused&\tUnused&\tUnused&\tUnused&\tControl\tiny up&\tUnused&\tUnused&\multirow{2}{*}{\z{1}\emph{x}}\\\cline{1-9}
			\emph{03x}&\tControl\tiny hex&\tUnused&\tUnused&\tForbidden\tiny esc&\tUnused&\tUnused&\tUnused&\tUnused&\\\hline
			\emph{04x}&&\bfseries!&$\square$&$\blacksquare$&\tUnused&\tUnused&\tUnused&\tUnused&\multirow{2}{*}{\z{2}\emph{x}}\\\cline{1-9}
			\emph{05x}&\tUnused&\tUnused&\tUnused&\tUnused&,&\tUnused&.&thin .&\\\hline
			\emph{06x}&\bfseries 0&\bfseries 1&\bfseries 2&\bfseries 3&\bfseries 4&\bfseries 5&\bfseries 6&\bfseries 7&\multirow{2}{*}{\z{3}\emph{x}}\\\cline{1-9}
			\emph{07x}&\bfseries 8&\bfseries 9&\bfseries :&\tUnused&\tUnused&\tUnused&\tUnused&\tUnused&\\\hline
			\emph{10x}&\textcopyright&\bfseries A&\bfseries B&\bfseries C&\bfseries D&\bfseries E&\bfseries F&\bfseries G&\multirow{2}{*}{\z{4}\emph{x}}\\\cline{1-9}
			\emph{11x}&\bfseries H&\bfseries I&\bfseries J&\bfseries K&\bfseries L&\bfseries M&\bfseries N&\bfseries O&\\\hline
			\emph{12x}&\bfseries P&\bfseries Q&\bfseries R&\bfseries S&\bfseries T&\bfseries U&\bfseries V&\bfseries W&\multirow{2}{*}{\z{5}\emph{x}}\\\cline{1-9}
			\emph{13x}&\bfseries X&\bfseries Y&\bfseries Z&\tUnused&\tUnused&\tUnused&\tUnused&\tUnused&\\\hline
			\emph{14x}&\textregistered&\faArrowLeft&\faArrowRight&\faArrowUp&\faArrowDown&$\nwarrow$&$\nearrow$&$\searrow$&\multirow{2}{*}{\z{6}\emph{x}}\\\cline{1-9}
			\emph{15x}&$\swarrow$&$\leftarrow$&$\rightarrow$&$\uparrow$&$\downarrow$&\raise1ex\hbox{\rule{1ex}{1ex}}\rule{1ex}{1ex}&\rule{1em}{1em}&\tUnused&\\\hline
			\emph{16x}&\checkmark&$\sqrt{}$&$\infty$&\OE&\oe&\texteuro&$\therefore$&$\because$&\multirow{2}{*}{\z{7}\emph{x}}\\\cline{1-9}
			\emph{17x}&\XSolidBold&$\blacktriangleleft$&$\blacktriangleright$&$\blacktriangle$&$\blacktriangledown$&$\updownarrow$&$\blacklozenge$&$\lozenge$&\\\hline
			\emph{20x}&$\lambda$&$\Theta$&$\Phi$&$\Psi$&\male&\female&\tUnused&zero&\multirow{2}{*}{\z{8}\emph{x}}\\\cline{1-9}
			\emph{21x}&$\pm$&$\mp$&$\oplus$&$\odot$&$\equiv$&clover&notes&EE&\\\hline
			\emph{22x}&\tiny{AM}&\tiny{PM}&$^\circ$F&$^\circ$C&{\tiny wide} \OE&{\tiny wide} \oe&\tUnused&\tUnused&\multirow{2}{*}{\z{9}\emph{x}}\\\cline{1-9}
			\emph{23x}&\multicolumn{8}{c|}{The phases of the moon}&\\\hline
			\emph{24x}&&\tSpecial\tiny{TS1}&\tSpecial\tiny{TS2}&\tSpecial\tiny{TS3}&\tSpecial\tiny{TS4}&\tSpecial\tiny{TS5}&\tSpecial\tiny{TS6}&\tSpecial\tiny{TS7}&\multirow{2}{*}{\z{A}\emph{x}}\\\cline{1-9}
			\emph{25x}&\tSpecial\tiny{TS8}&\tUnused&\tUnused&\tUnused&\tUnused&\tUnused&\tUnused&\tUnused&\\\hline
			\emph{26x}&\multicolumn{8}{c|}{The eight trigrams 0--7}&\multirow{2}{*}{\z{B}\emph{x}}\\\cline{1-9}
			\emph{27x}&\tUnused&\tUnused&\tUnused&\tUnused&\tUnused&\tUnused&\tUnused&\tUnused&\\\hline
%			\emph{30x}&\tUnused&\tUnused&\tUnused&\tUnused&\tUnused&\tUnused&\tUnused&\tUnused&\multirow{2}{*}{\z{C}\emph{x}}\\\cline{1-9}
%			\emph{31x}&\tUnused&\tUnused&\tUnused&\tUnused&\tUnused&\tUnused&\tUnused&\tUnused&\\\hline
%			\emph{32x}&\tUnused&\tUnused&\tUnused&\tUnused&\tUnused&\tUnused&\tUnused&\tUnused&\multirow{2}{*}{\z{D}\emph{x}}\\\cline{1-9}
%			\emph{33x}&\tUnused&\tUnused&\tUnused&\tUnused&\tUnused&\tUnused&\tUnused&\tUnused&\\\hline
%			\emph{34x}&\tUnused&\tUnused&\tUnused&\tUnused&\tUnused&\tUnused&\tUnused&\tUnused&\multirow{2}{*}{\z{E}\emph{x}}\\\cline{1-9}
%			\emph{35x}&\tUnused&\tUnused&\tUnused&\tUnused&\tUnused&\tUnused&\tUnused&\tUnused&\\\hline
%			\emph{36x}&\tUnused&\tUnused&\tUnused&\tUnused&\tUnused&\tUnused&\tUnused&\tUnused&\multirow{2}{*}{\z{F}\emph{x}}\\\cline{1-9}
%			\emph{37x}&\tUnused&\tUnused&\tUnused&\tUnused&\tUnused&\tUnused&\tUnused&\tUnused&\\\hline
%			&\emph{x}\z{0} &\emph{x}\z{1} &\emph{x}\z{2} &\emph{x}\z{3}
%			&\emph{x}\z{4} &\emph{x}\z{5} &\emph{x}\z{6} &\emph{x}\z{7}\\
			&\z{8} &\z{9} &\z{A} &\z{B}
			&\z{C} &\z{D} &\z{E} &\z{F}
		\end{tabular}

		\smallskip

		{\footnotesize TS\Var*{n} = Thin space of \Var*{n} pixels}
	\end{center}
	\caption{Font Table for Font \#2\label{tbl:font2}}
\end{table}
\begin{table}
	\begin{center}
		\begin{tabular}{r|c|c|c|c|c|c|c|c|l}
			&\emph{0} &\emph{1} &\emph{2} &\emph{3}
			&\emph{4} &\emph{5} &\emph{6} &\emph{7}&\\\hline
			\emph{00x}&\tForbidden\tiny null&\tUnused&\tUnused&\tControl\tiny move&\tForbidden\tiny end&\tUnused&\tControl\tiny font&\tUnused&\multirow{2}{*}{\z{0}\emph{x}}\\\cline{1-9}
			\emph{01x}&\tControl\tiny back&\tUnused&\tControl\tiny down&\tControl\tiny color&\tControl\tiny forw&\tUnused&\tUnused&\tUnused&\\\hline
			\emph{02x}&\tUnused&\tUnused&\tUnused&\tUnused&\tUnused&\tControl\tiny up&\tUnused&\tUnused&\multirow{2}{*}{\z{1}\emph{x}}\\\cline{1-9}
			\emph{03x}&\tControl\tiny hex&\tUnused&\tUnused&\tForbidden\tiny esc&\tUnused&\tUnused&\tUnused&\tUnused&\\\hline
			\emph{04x}&&!&\z"&\#&\$&\%&\&&\z'&\multirow{2}{*}{\z{2}\emph{x}}\\\cline{1-9}
			\emph{05x}&(&)&*&+&,&-&.&/&\\\hline
			\emph{06x}&0&1&2&3&4&5&6&7&\multirow{2}{*}{\z{3}\emph{x}}\\\cline{1-9}
			\emph{07x}&8&9&:&;&\z<&=&\z>&?&\\\hline
			\emph{10x}&@&\tUnused&\tUnused&\tUnused&\tUnused&\tUnused&\tUnused&\tUnused&\multirow{2}{*}{\z{4}\emph{x}}\\\cline{1-9}
			\emph{11x}&\tUnused&\tUnused&\tUnused&\tUnused&\tUnused&\tUnused&\tUnused&\tUnused&\\\hline
			\emph{12x}&\tUnused&\tUnused&\tUnused&\tUnused&\tUnused&\tUnused&\tUnused&\tUnused&\multirow{2}{*}{\z{5}\emph{x}}\\\cline{1-9}
			\emph{13x}&\tUnused&\tUnused&\tUnused&[&\tUnused&]&\textasciicircum&\_&\\\hline
			\emph{14x}&\tUnused&\tUnused&\tUnused&\tUnused&\tUnused&\tUnused&\tUnused&\tUnused&\multirow{2}{*}{\z{6}\emph{x}}\\\cline{1-9}
			\emph{15x}&\tUnused&\tUnused&\tUnused&\tUnused&\tUnused&\tUnused&\tUnused&\tUnused&\\\hline
			\emph{16x}&\tUnused&\tUnused&\tUnused&\tUnused&\tUnused&\tUnused&\tUnused&\tUnused&\multirow{2}{*}{\z{7}\emph{x}}\\\cline{1-9}
			\emph{17x}&\tUnused&\tUnused&\tUnused&\tUnused&\tUnused&\tUnused&\tUnused&\tUnused&\\\hline
			\emph{20x}&``&''&`&'&\tUnused&\tUnused&\tUnused&\tUnused&\multirow{2}{*}{\z{8}\emph{x}}\\\cline{1-9}
			\emph{21x}&\tUnused&\tUnused&\tUnused&\tUnused&\tUnused&\tUnused&\tUnused&\tUnused&\\\hline
			\emph{22x}&\tUnused&\tUnused&\tUnused&\tUnused&\tUnused&\tUnused&\tUnused&\tUnused&\multirow{2}{*}{\z{9}\emph{x}}\\\cline{1-9}
			\emph{23x}&\tUnused&\tUnused&\tUnused&\tUnused&\tUnused&\tUnused&\tUnused&\tUnused&\\\hline
			\emph{24x}&\tUnused&\tUnused&\tUnused&\tUnused&\tUnused&\tUnused&\tUnused&\tUnused&\multirow{2}{*}{\z{A}\emph{x}}\\\cline{1-9}
			\emph{25x}&\tUnused&\tUnused&\tUnused&\tUnused&\tUnused&\tUnused&\tUnused&\tUnused&\\\hline
			\emph{26x}&\tUnused&\tUnused&\tUnused&\tUnused&\tUnused&\tUnused&\tUnused&\tUnused&\multirow{2}{*}{\z{B}\emph{x}}\\\cline{1-9}
			\emph{27x}&\tUnused&\tUnused&\tUnused&\tUnused&\sfrac14&\sfrac12&\sfrac34&\tUnused&\\\hline
%			\emph{30x}&\tUnused&\tUnused&\tUnused&\tUnused&\tUnused&\tUnused&\tUnused&\tUnused&\multirow{2}{*}{\z{C}\emph{x}}\\\cline{1-9}
%			\emph{31x}&\tUnused&\tUnused&\tUnused&\tUnused&\tUnused&\tUnused&\tUnused&\tUnused&\\\hline
%			\emph{32x}&\tUnused&\tUnused&\tUnused&\tUnused&\tUnused&\tUnused&\tUnused&\tUnused&\multirow{2}{*}{\z{D}\emph{x}}\\\cline{1-9}
%			\emph{33x}&\tUnused&\tUnused&\tUnused&\tUnused&\tUnused&\tUnused&\tUnused&\tUnused&\\\hline
%			\emph{34x}&\tUnused&\tUnused&\tUnused&\tUnused&\tUnused&\tUnused&\tUnused&\tUnused&\multirow{2}{*}{\z{E}\emph{x}}\\\cline{1-9}
%			\emph{35x}&\tUnused&\tUnused&\tUnused&\tUnused&\tUnused&\tUnused&\tUnused&\tUnused&\\\hline
%			\emph{36x}&\tUnused&\tUnused&\tUnused&\tUnused&\tUnused&\tUnused&\tUnused&\tUnused&\multirow{2}{*}{\z{F}\emph{x}}\\\cline{1-9}
%			\emph{37x}&\tUnused&\tUnused&\tUnused&\tUnused&\tUnused&\tUnused&\tUnused&\tUnused&\\\hline
			&\emph{x}\z{0} &\emph{x}\z{1} &\emph{x}\z{2} &\emph{x}\z{3}
			&\emph{x}\z{4} &\emph{x}\z{5} &\emph{x}\z{6} &\emph{x}\z{7}\\
			&\z{8} &\z{9} &\z{A} &\z{B}
			&\z{C} &\z{D} &\z{E} &\z{F}
		\end{tabular}
	\end{center}
	\caption{Font Table for Font \#3\label{tbl:font3}}
\end{table}
\begin{table}
	\begin{center}
		\begin{tabular}{r|c|c|c|c|c|c|c|c|l}
			&\emph{0} &\emph{1} &\emph{2} &\emph{3}
			&\emph{4} &\emph{5} &\emph{6} &\emph{7}&\\\hline
			\emph{00x}&\tForbidden\tiny null&\tUnused&\tUnused&\tControl\tiny move&\tForbidden\tiny end&\tUnused&\tControl\tiny font&\tUnused&\multirow{2}{*}{\z{0}\emph{x}}\\\cline{1-9}
			\emph{01x}&\tControl\tiny back&\tUnused&\tControl\tiny down&\tControl\tiny color&\tControl\tiny forw&\tUnused&\tUnused&\tUnused&\\\hline
			\emph{02x}&\tUnused&\tUnused&\tUnused&\tUnused&\tUnused&\tControl\tiny up&\tUnused&\tUnused&\multirow{2}{*}{\z{1}\emph{x}}\\\cline{1-9}
			\emph{03x}&\tControl\tiny hex&\tUnused&\tUnused&\tForbidden\tiny esc&\tUnused&\tUnused&\tUnused&\tUnused&\\\hline
			\emph{04x}&&\tUnused&$\tUnused$&$\tUnused$&\tUnused&\tUnused&\tUnused&\tUnused&\multirow{2}{*}{\z{2}\emph{x}}\\\cline{1-9}
			\emph{05x}&\tUnused&\tUnused&\tUnused&\tUnused&\tUnused&\tUnused&\tUnused&\tUnused&\\\hline
			\emph{06x}&0&1&2&3&4&5&6&7&\multirow{2}{*}{\z{3}\emph{x}}\\\cline{1-9}
			\emph{07x}&8&9&\tUnused&\tUnused&\tUnused&\tUnused&\tUnused&\tUnused\\\hline
			&\z{8} &\z{9} &\z{A} &\z{B}
			&\z{C} &\z{D} &\z{E} &\z{F}
		\end{tabular}
	\end{center}
	\caption{Font Table for Fonts \#4--\#5\label{tbl:font4}\label{tbl:font5}}
\end{table}
			
\section{\z{B}---Beep/Play Sound Sequence}
\begin{center}
\begin{bytefield}[endianness=little,bitwidth=0.11111\textwidth]{8}
%	\bitheader{0-8} \\
	\bitbox[]{1}{\scriptsize0}&
	\bitbox[]{1}{\scriptsize1}&
	\bitbox[]{1}{\scriptsize2}&
	\bitbox[]{1}{\scriptsize3}&
	\bitbox[]{1}{\scriptsize4}&
	\bitbox[]{1}{\dots}\\
	\bitbox{1}{\z{B}} &
	\bitbox{1}{\Var*{loop}}&
	\bitbox[ltb]{1}{\Var*{note}}&
	\bitbox[tb]{2}{\Var*{cs (hex)}}&
	\bitbox[tbr]{1}{\dots}&
	\bitbox{1}{\z{\$}}
\end{bytefield}
\\
\begin{Coding}
	|/readerboard/v1/sound?a=|\Var*{ad}|&loop=|\Var*{bool}|&notes=|\Var*{note}\Var*{cs}\dots\\
\end{Coding}
\end{center}

This command causes the device to play a sequence of notes on the speaker. If \Var*{loop} is ``\z{L}'', the note sequence is
played repeatedly until another \z{B} command is received. If the sequence is empty, all sound is stopped. If \Var*{loop} is ``\z{.}'',
it is only played once.

The sequence consists of a series of \Var*{note} values, each of which is followed by the note duration \Var*{cs} which is a two-character
hexadecimal integer in centiseconds. (1/100th of a second).  Each \Var*{note} begins with a letter \z{A}--\z{G}, optionally followed by
\z{\#} or \z{b} to indicate a sharp ($\sharp$) or flat ($\flat$) note, respectively, followed by a digit \z0--\z8 to indicate the octave. The notes range from \z{B0} (B$_0$ at 31\,Hz)
to \z{D\#8} (D$_8^{\sharp}$ at 4.978\,kHz). A rest is indicated by ``\z{R}'' as the note letter.

An example 3-note attention tone where the first two notes are played for \sfrac12 second and the final one is held for a full second
is ``\z{G432E532C564}'' (note G$_4$, \z{32}$_{16}$\,cs=0.50\,s, note E$_5$, \z{32}$_{16}$\,cs=0.50\,s, note C$_5$, \z{64}$_{16}$\,cs=1.00\,s).
Duration codes range from \z{00} (\z0$_{16}$=0$_{10}$\,cs=0.00\,s) to \z{FF} (\z{FF}$_{16}$=255$_{10}$\,cs=2.55\,s),
in increments of 0.01\,s.

The letters may be upper- or lower-case (the letter \z{b} is distinguished as a note name vs.\ a ``$\flat$'' half-step shift indicator from context).

Some devices are not able to play notes but can sound a beep at a fixed frequency (typically 490\,Hz or just ever so slightly flat of B$_4$
for SparkFun Pro Micro and Adruino Mega 2560 microcontrollers and 1\,kHz or between B$_5$ and C$_6$ for Arduino Due). These will play that single
tone regardless of the note specified in the sequence.

\section{\z{C}---Clear Matrix Display}
\begin{center}
\begin{bytefield}[endianness=little,bitwidth=0.11111\textwidth]{1}
	\bitheader{0} \\
	\bitbox{1}{\z{C}} 
\end{bytefield}
\\
%|{"m":"clear","a":[|\Var*{ad$_0$}|,|\dots|]}|
\begin{Coding}
	|/readerboard/v1/clear?a=|\Var*{ad}
\end{Coding}
\end{center}

Clears the matrix display so that no \led s are illuminated. Does not affect
the discrete \led s.

\section{\z{D}---Set Dimmer Levels}
\begin{center}
\begin{bytefield}[endianness=little,bitwidth=0.11111\textwidth]{2}
	\bitheader{0-3} \\
	\bitbox{1}{\z{D}} &
	\bitbox{1}{\Var*{led}} 
	\bitbox{2}{\Var*{level (hex)}} 
\end{bytefield}
\\
%|{"m":"graph","a":[|\Var*{ad$_0$}|,|\dots|],"v":|\Var*{n}|}|
\begin{Coding}
	|/readerboard/v1/dim?a=|\Var*{ad}|&l=|\Var*{led}|&d=|\Var*{level}
\end{Coding}
\end{center}
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

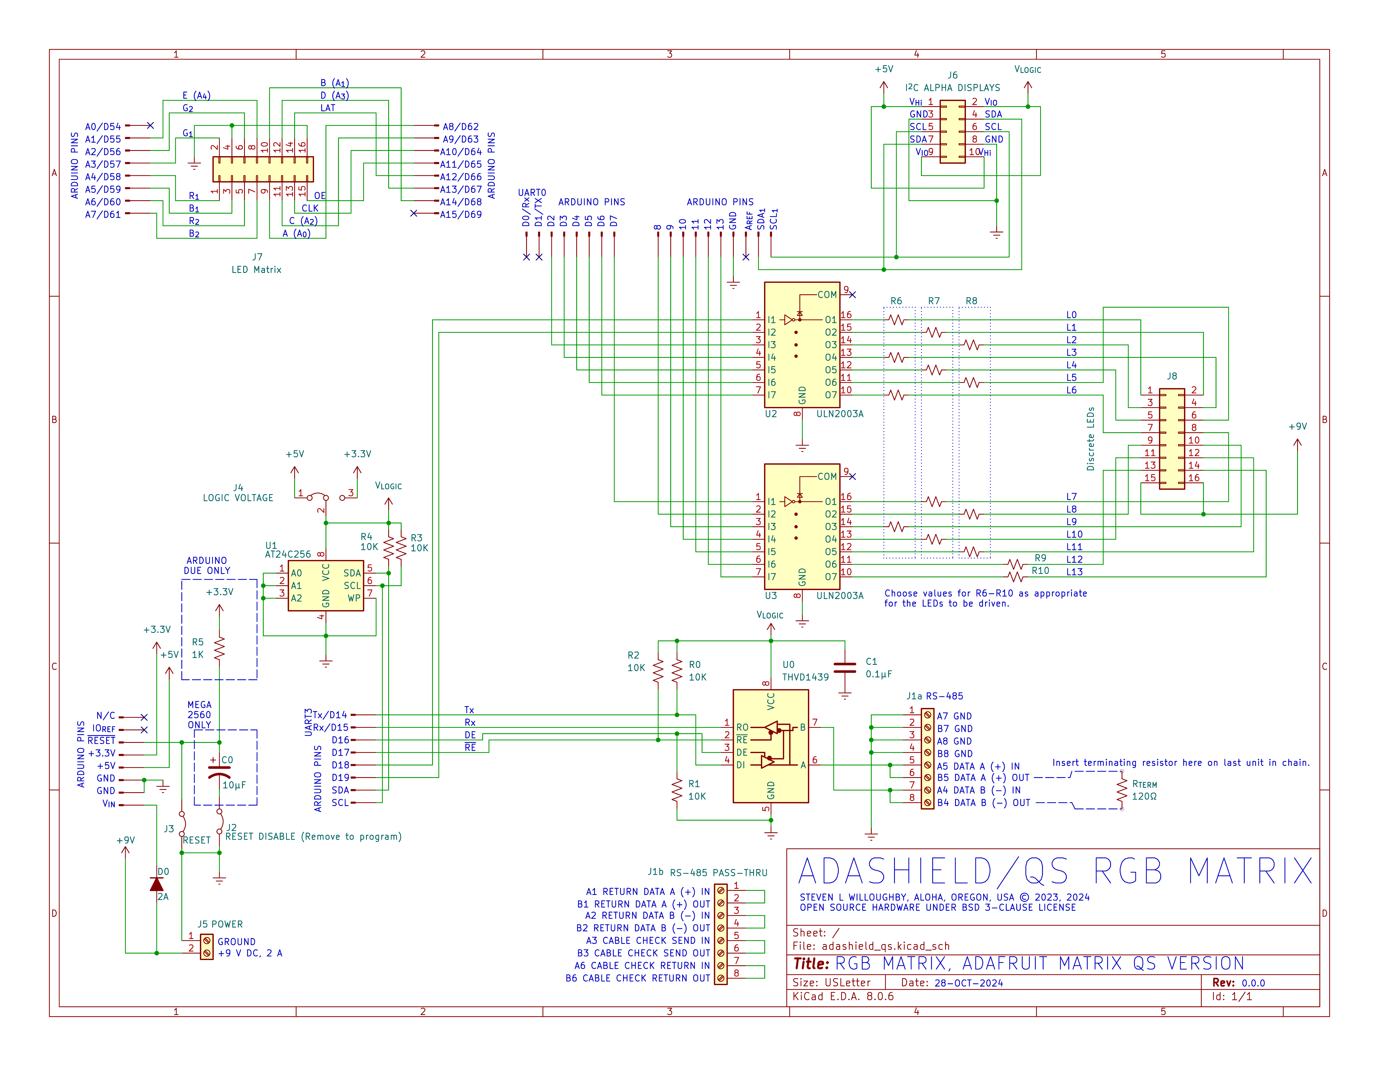
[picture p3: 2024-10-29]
doc/images/adashield_qs_schematic.png

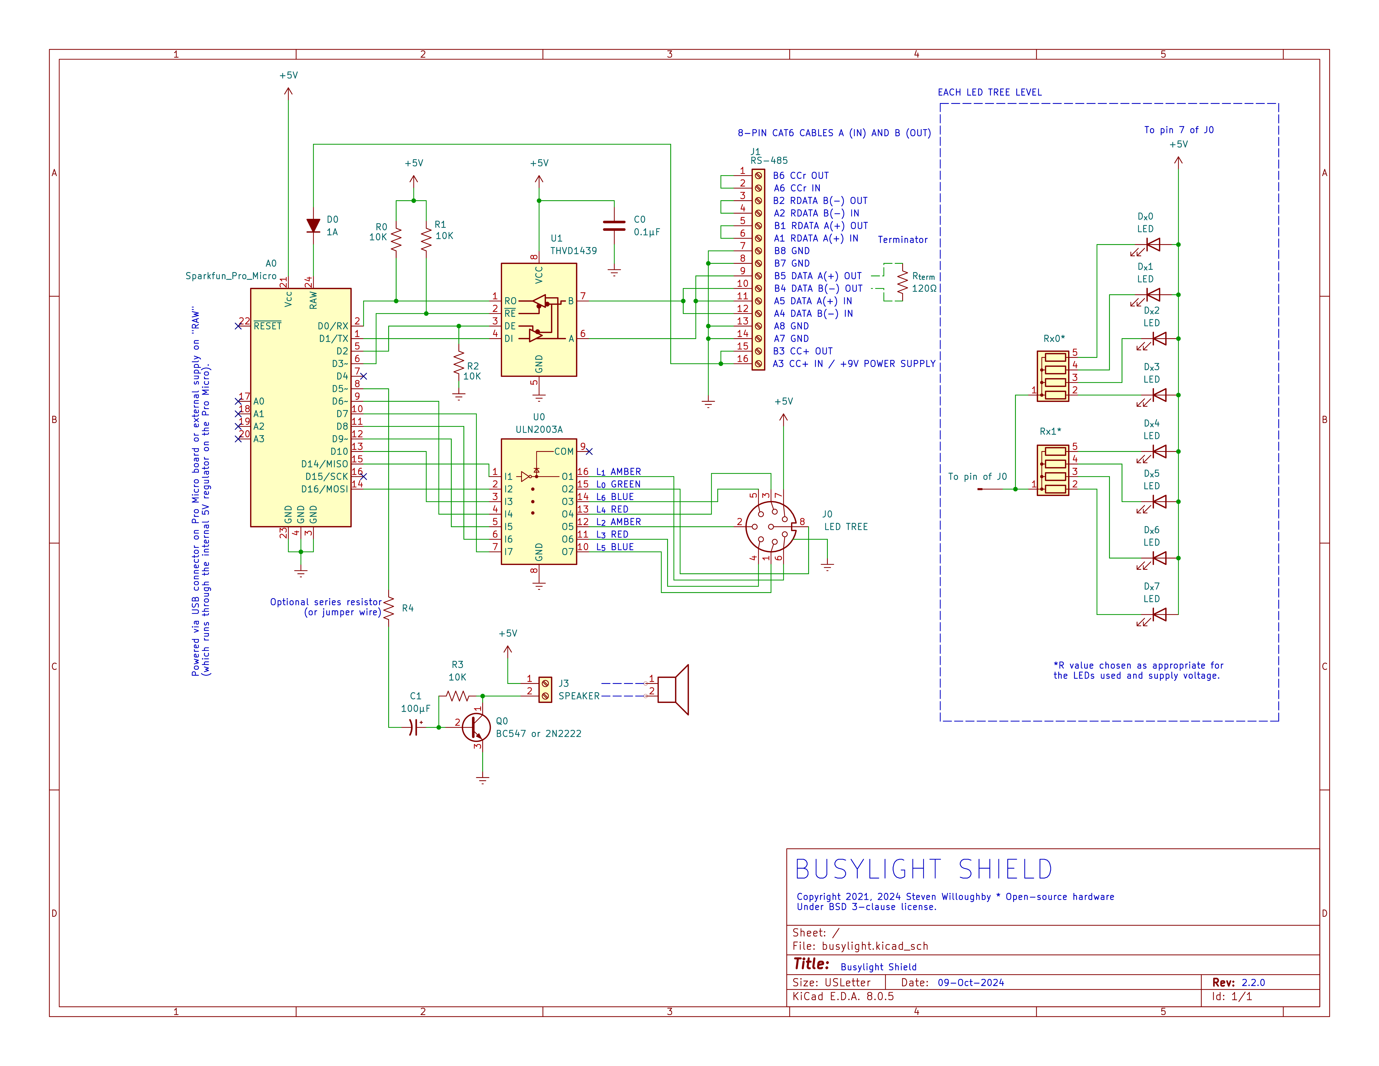
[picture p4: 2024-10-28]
doc/images/busylight_schematic.png

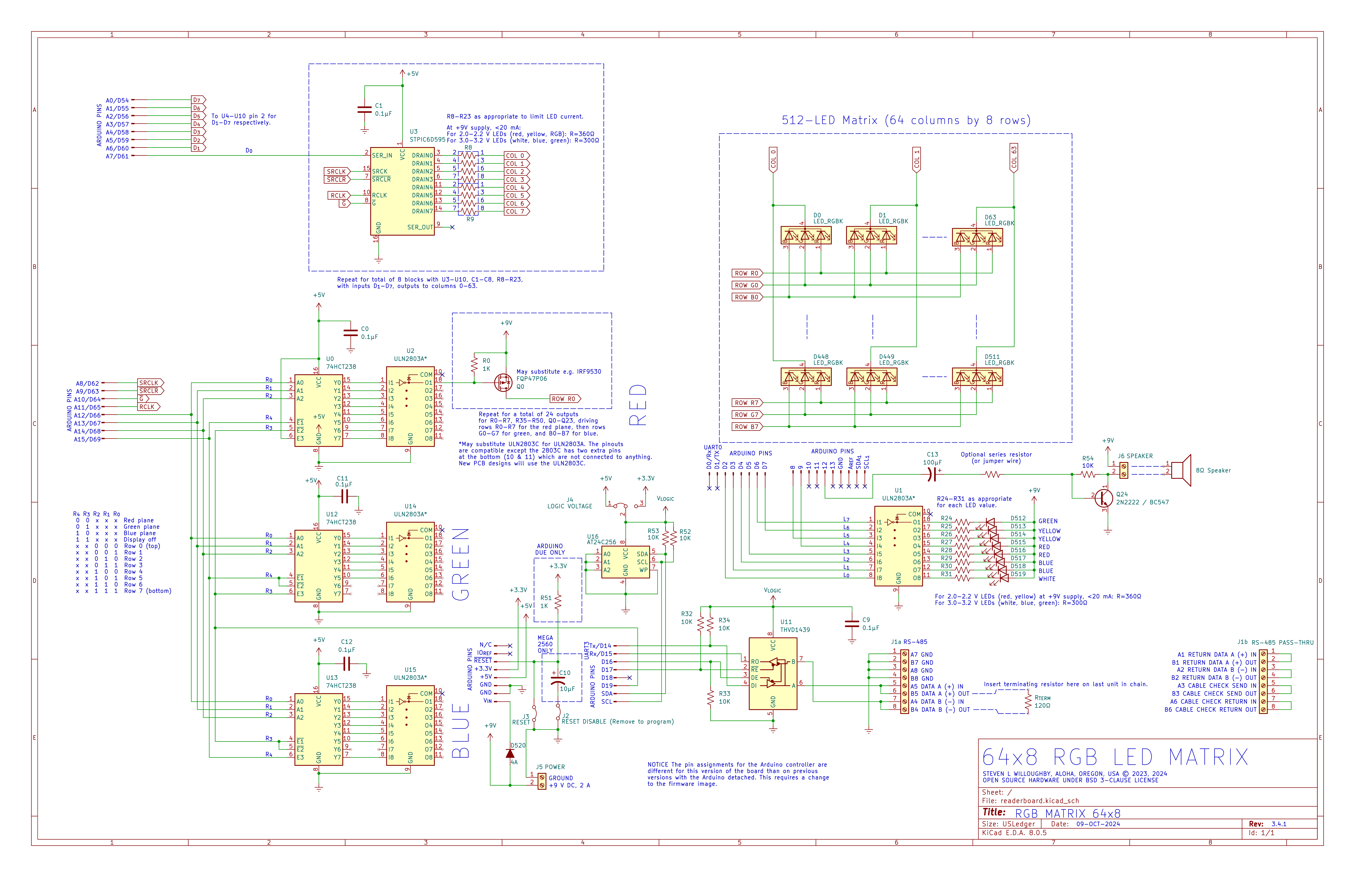
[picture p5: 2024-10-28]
doc/images/readerboard_schematic.png

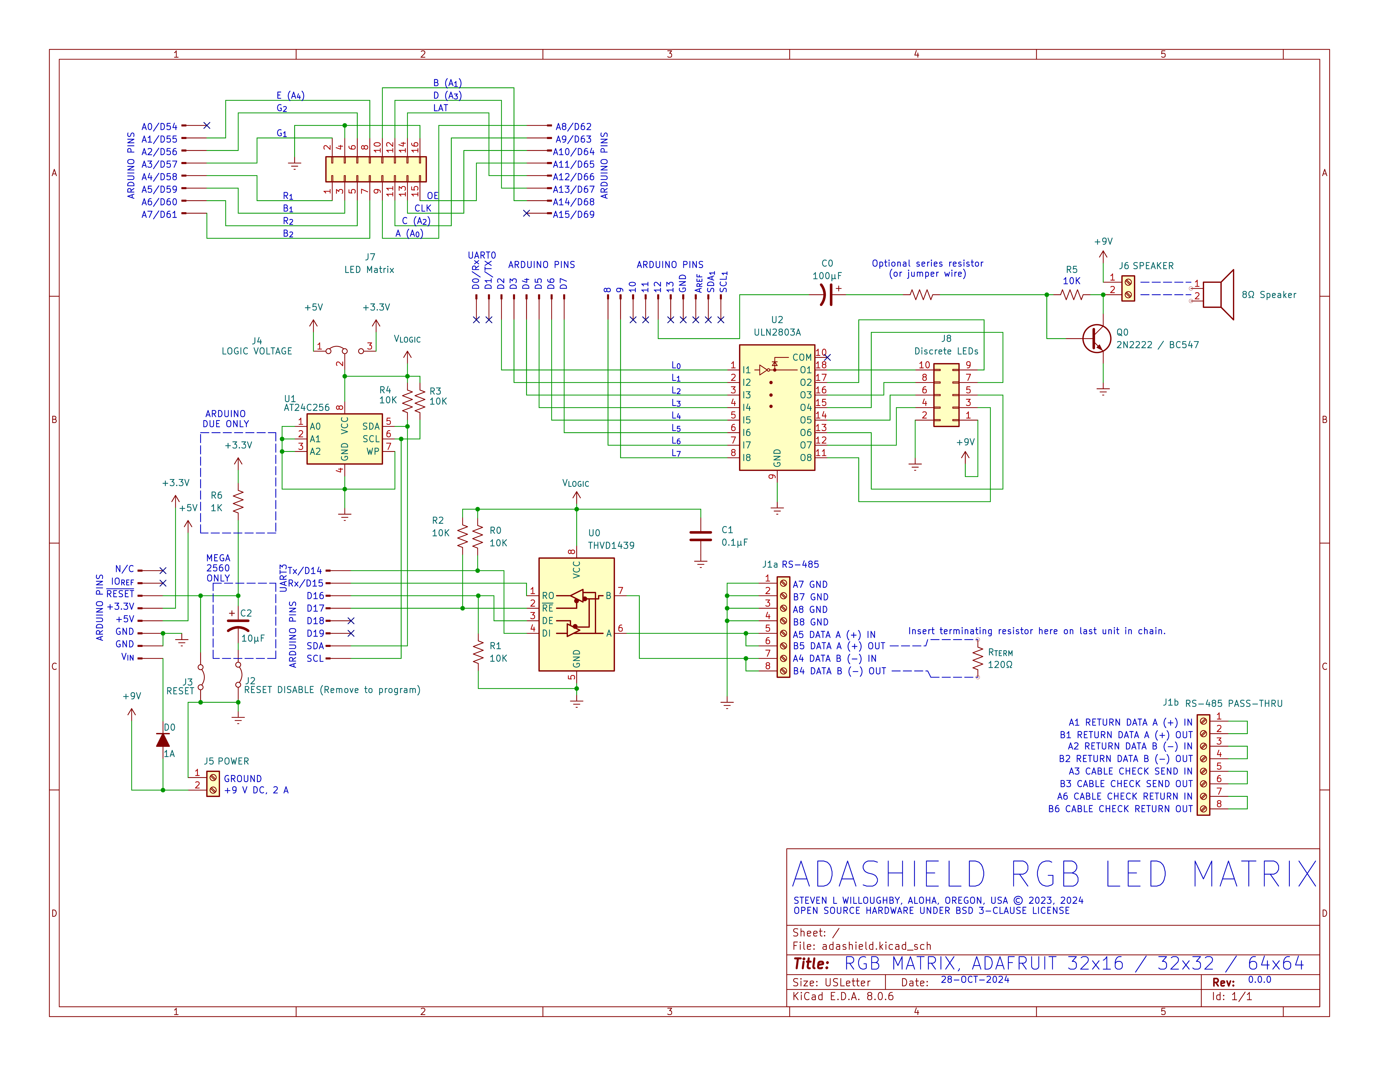
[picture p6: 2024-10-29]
doc/images/adashield_schematic.png

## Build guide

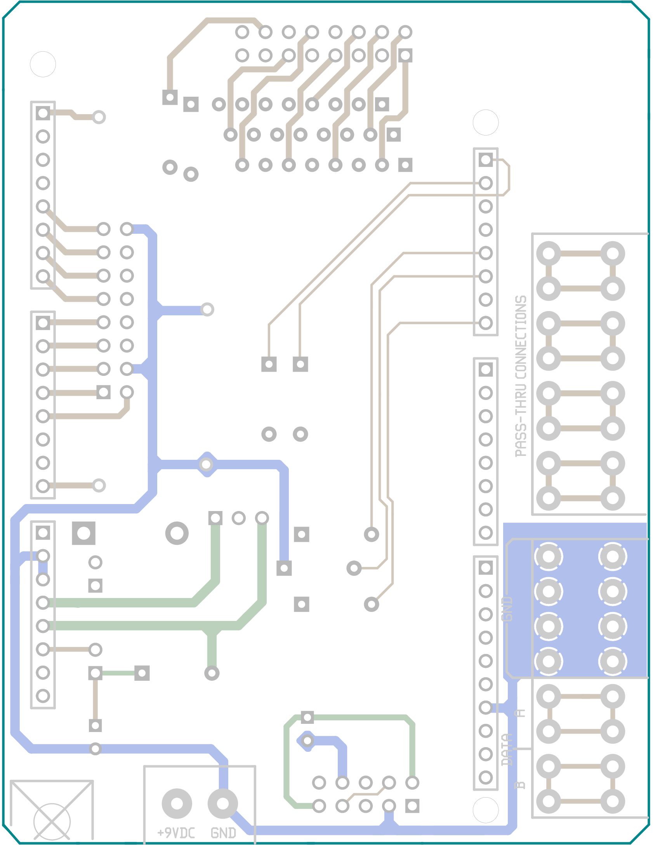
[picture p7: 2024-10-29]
doc/images/adashield_qs-assembly-1.png

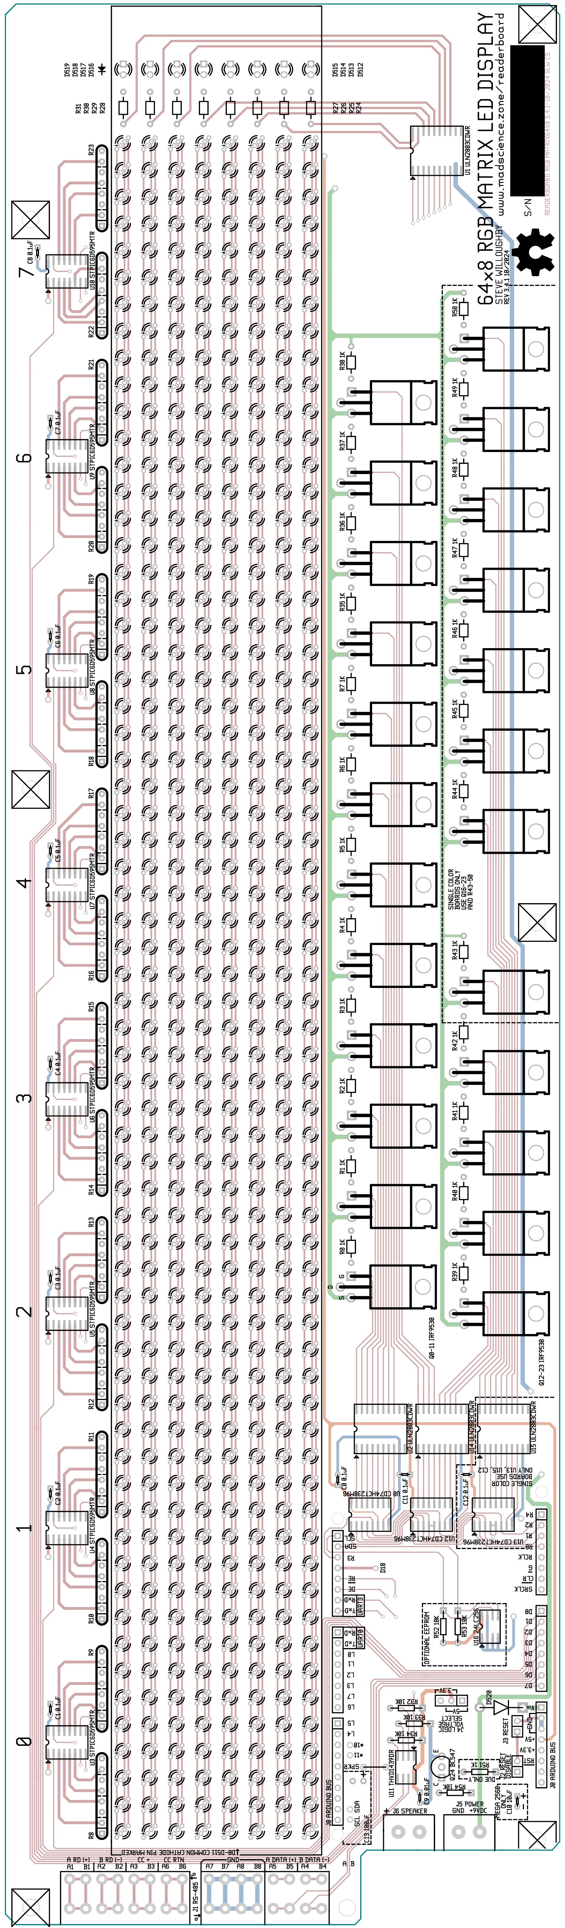
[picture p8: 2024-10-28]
doc/images/readerboard-assembly-0.png

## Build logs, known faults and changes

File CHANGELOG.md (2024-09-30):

# Change history for Readerboard
## Project Version v0.0.0 (unreleased, under development)
This includes the following:
  * Application version 0.0.0 (pre-alpha)
  * Busylight hardware revision 2.1.1
  * Light tree hardware revision 1.1
  * Readerboard hardware revision 3.3.0
  * Firmware revision 2.1.3

### Application Changes
  * Added new program `rbserver` and the supporting `readerboard` Go libraries to centrally manage a fleet of readerboards and busylights.
  * Added new program `setsn` to field program the serial number into a readerbaord or busylight unit.

### Hardware Changes
  * Major updates to the readerboard PCB. Moved from separate boards connected with ribbon cables to a single board with attached Arduino controller as a daughter board, upgraded from monochrome to RGB LEDs, added support for RS-485 and external EEPROM chips.
  * Updates to busylight PCB to add RS-485 support and convenient daisy-chain RS-485 cable connections.
  * Updated the light tree PCB used with busylight to correct space issues with resistors and lack of pass-through capacity.

### Firmware Changes
  * Unified busylight and readerboard firmware into a single image. Compile-time switches select the target device.

## Older Change History for Busylight
The following history describes the releases of Busylight before it was merged with the Readerboard project.

## Version 1.10.0
### Blight changes
 * Added "Clear times" button and improved support for tracking activity times.
 * Introduced 1 second delay before updating display to allow time for the light device to complete what it was supposed to do. 

## Version 1.9.1
Improved blight script, also added `ColorValues` field to `config.json`.

## Version 1.9.0
Added a simple GUI front-end which provides buttons to change status on the lights as well
as simple time tracking of activities.

## Version 1.8.2
Added an output line to the `-query` option to indicate whether the daemon is
currently running or not.

## Version 1.8.1
Added the ability to name the light colors for a more human-friendly output
from the `-query` option.

## Version 1.8
Added a `-query` option to `busylight` and corresponding firmware support to allow
the user to ask the hardware which lights are on and what sequences are playing.

## Version 1.7
Added a `-list` option to `busylight` which lists out all the defined status codes
(from the configuration file) that the user can specify with the `-status` option.

## Version 1.6.1
Made a slight change to the order in which `busylight` sends commands to the daemon,
so that `-wake` happens first in the sequence and `-zzz` happens last.

## Version 1.6
Colors are now arbitrary and up to 7 lights are supported. New shield PCB introduced.
New protocol introduced to support more arbitrary light patterns.

Removed superfluous `busylight-standalone` command. Now both `busylight` and `busylightd` can
directly update the device since as of this version neither leaves the I/O
port open all the time. In case of a collision, the programs will wait for the other to
let go of the port before proceeding.

## Version 1.5
Adds a low-priority indicator to be added in addition to the other
markers so you can say things like "I'm in a video call but it's not
so important that I can't be interrupted. Just understand I'm on camera."

Also re-added the 1.4 changes to the repo since apparently they didn't get
committed correctly before.

Also also becoming very apparent that using signals to notify the daemon
of changes in state was a bad idea (given the limited availability of
signals that are safe to co-opt for this usage), so a future version will 
likely introduce a new mechanism for that.

## Version 1.4
Allows a regular expression for the device name now, so that the daemon
can search for whatever name the OS randomly chose for the hardware device.

## Version 1.3
The daemon now closes the serial port when put in inactive state and
re-opens it when going active again. It also reloads its configuration
file at that time, making it possible to change the serial device in case
the system gave it a new dynamic device name during the time the daemon
was sleeping.

This also allows other configuration changes to be made  without restarting
the daemon (just set it to inactive state and back to active again).

Refactored some code to clean it up a little. 

## Version 1.2
The 1.2 release includes the ability to ignore long-running appointments on selected calendars, to avoid
signalling that the user is "busy" because of an all-day event on a group calendar.

This made it necessary to change the `config.json` file's list of calendars to be monitored. Users of the 1.1 version will need to 
update this configuration file after upgrading to 1.2.

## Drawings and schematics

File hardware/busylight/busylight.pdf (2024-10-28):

## busylight.pcb

## 1. Table of Contents (This Page) Created on Tue Oct 22 19:48:34 2024 2. top 3. ground 4. outline 5. plated-drill 6. componentmask 7. soldermask 8. topsilk 9. bottomsilk 10. toppaste 11. topassembly 12. bottomassembly 13. fab

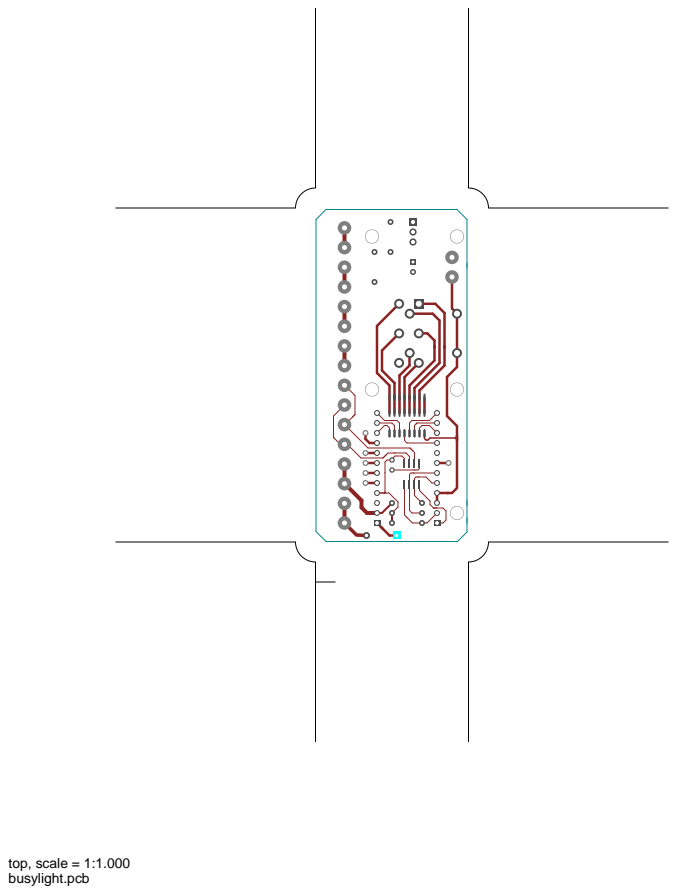
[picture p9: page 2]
top, scale = 1:1.000

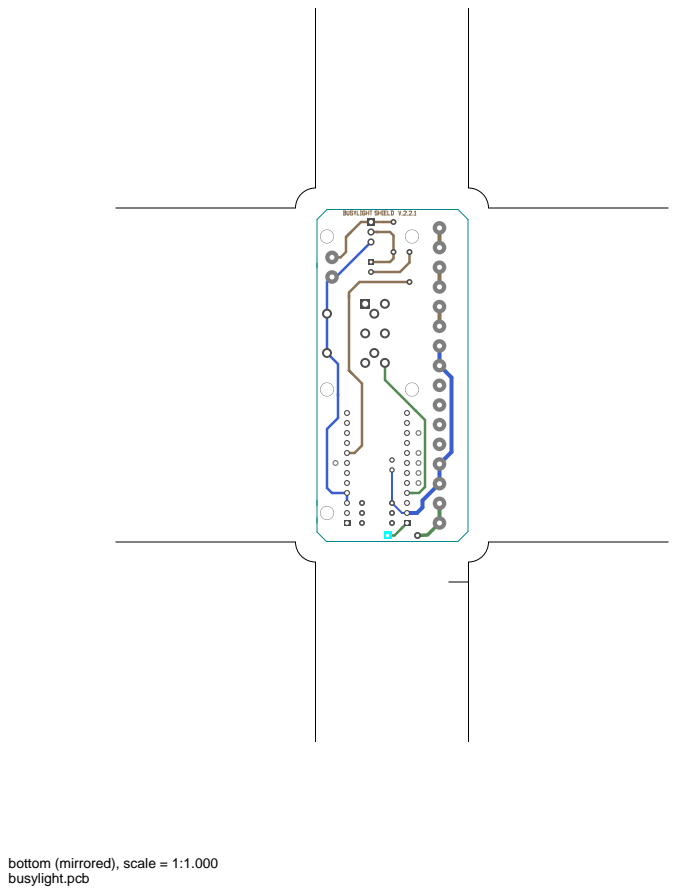
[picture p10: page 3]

bottom (mirrored), scale = 1:1.000

outline, scale = 1:1.000

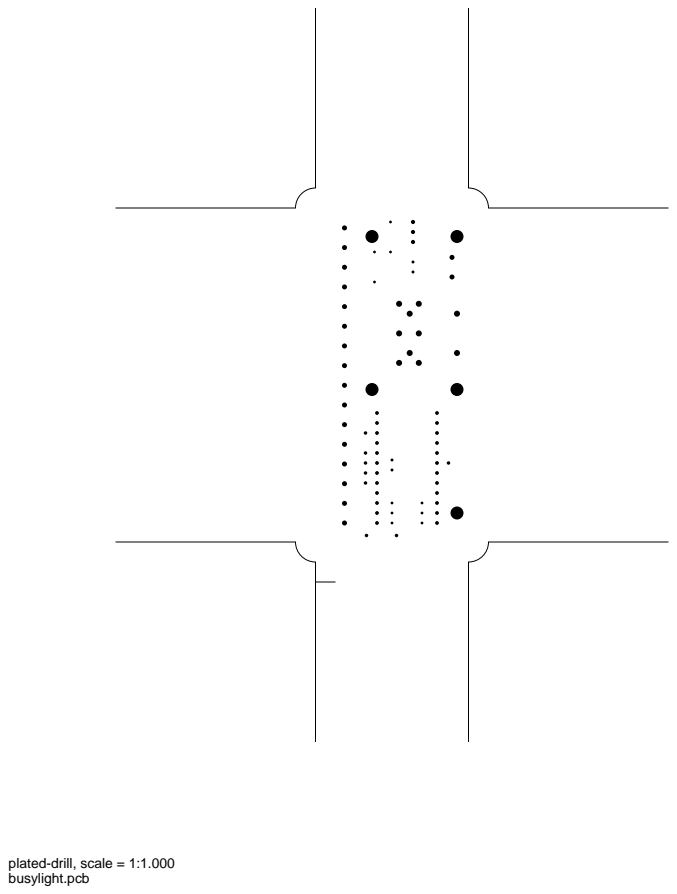
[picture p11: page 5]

plated-drill, scale = 1:1.000

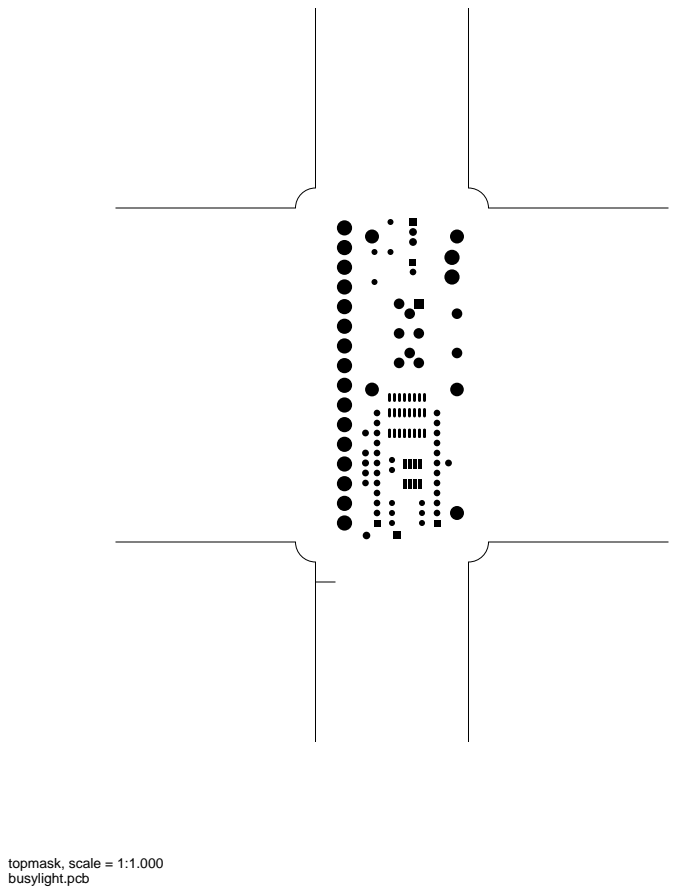
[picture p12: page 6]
topmask, scale = 1:1.000

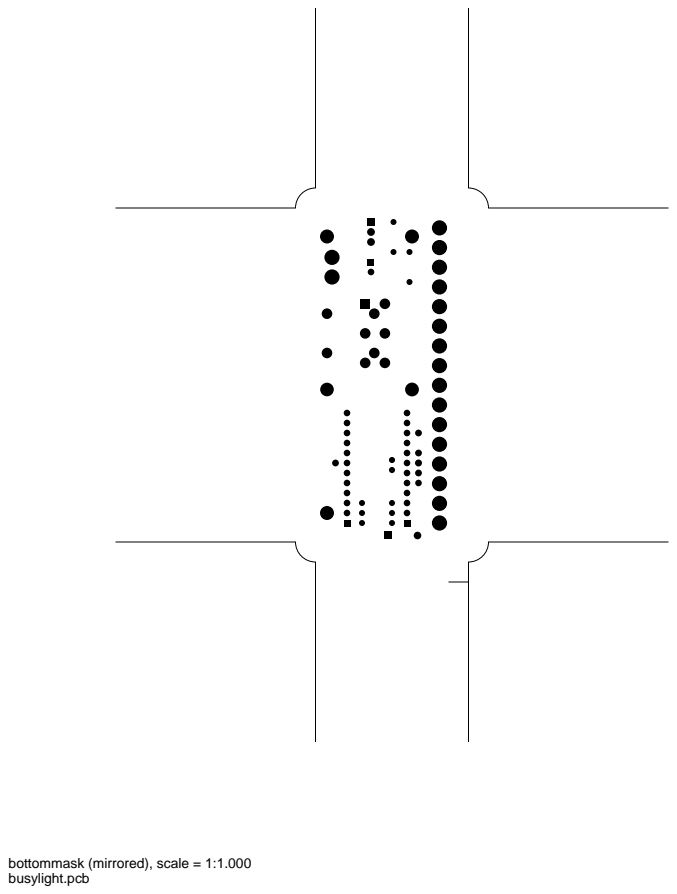
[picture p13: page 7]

bottommask (mirrored), scale = 1:1.000

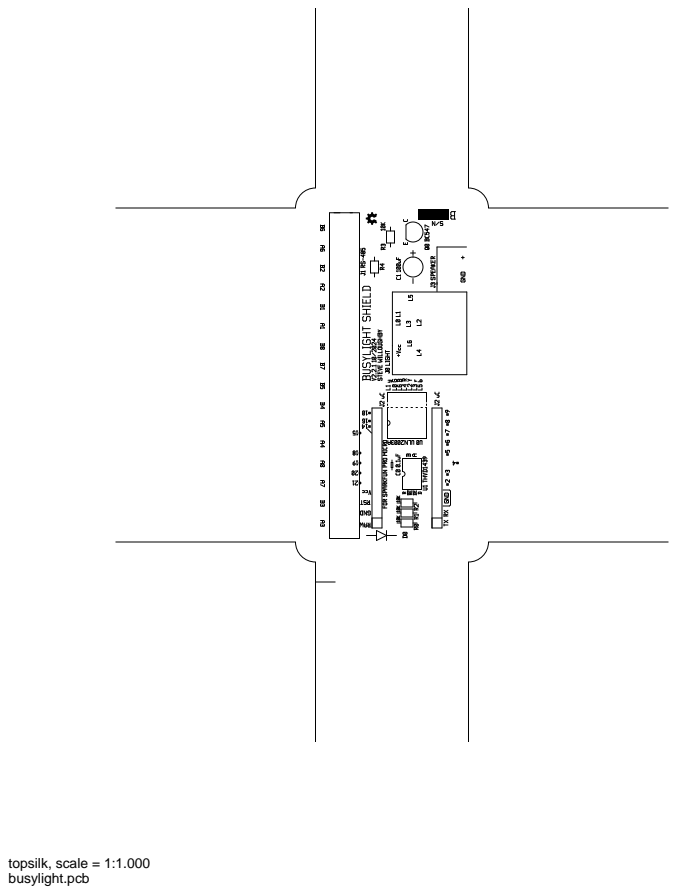
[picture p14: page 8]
topsilk, scale = 1:1.000

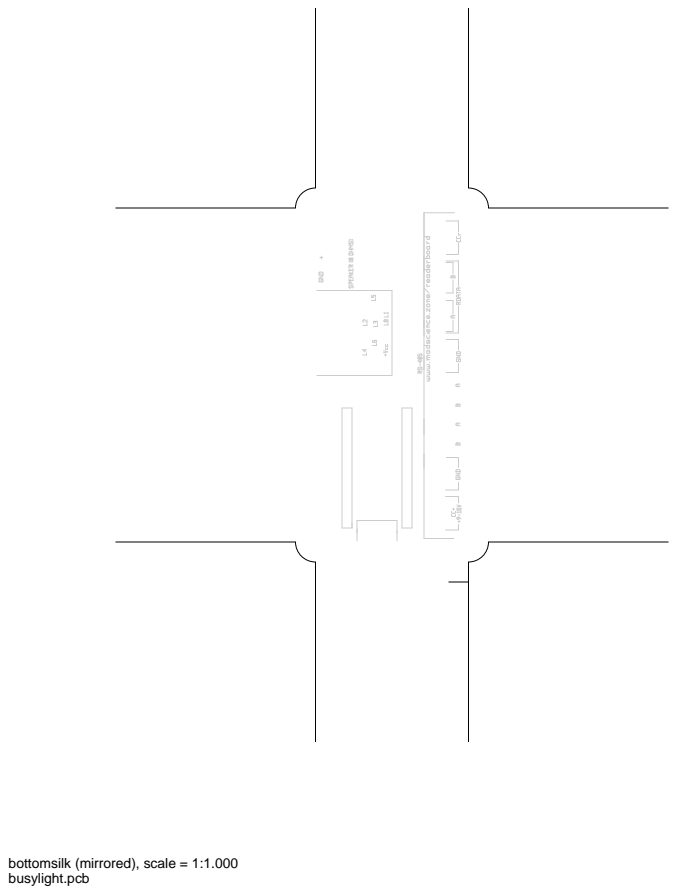
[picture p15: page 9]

bottomsilk (mirrored), scale = 1:1.000

toppaste, scale = 1:1.000

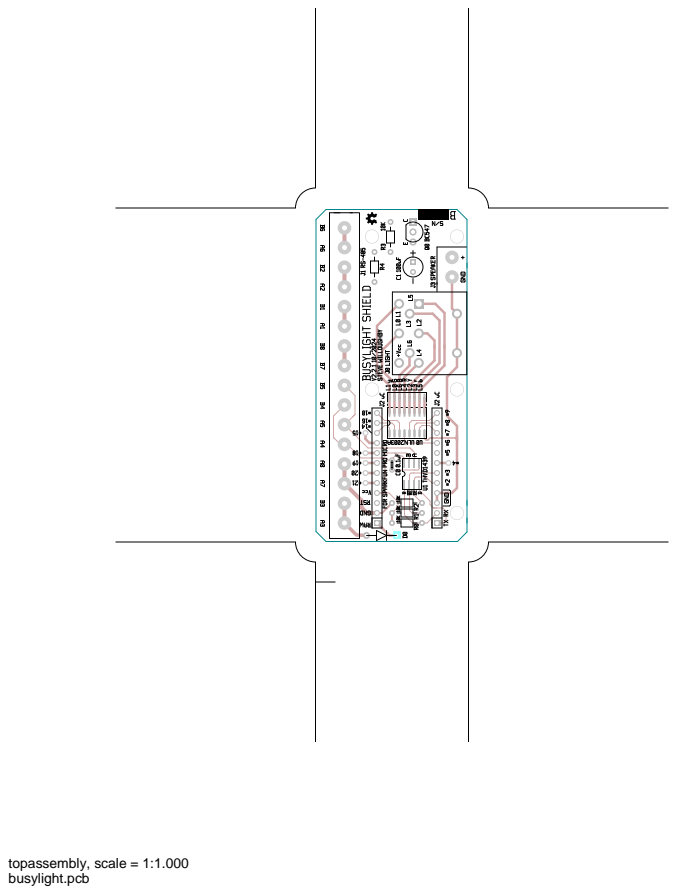
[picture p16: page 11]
topassembly, scale = 1:1.000

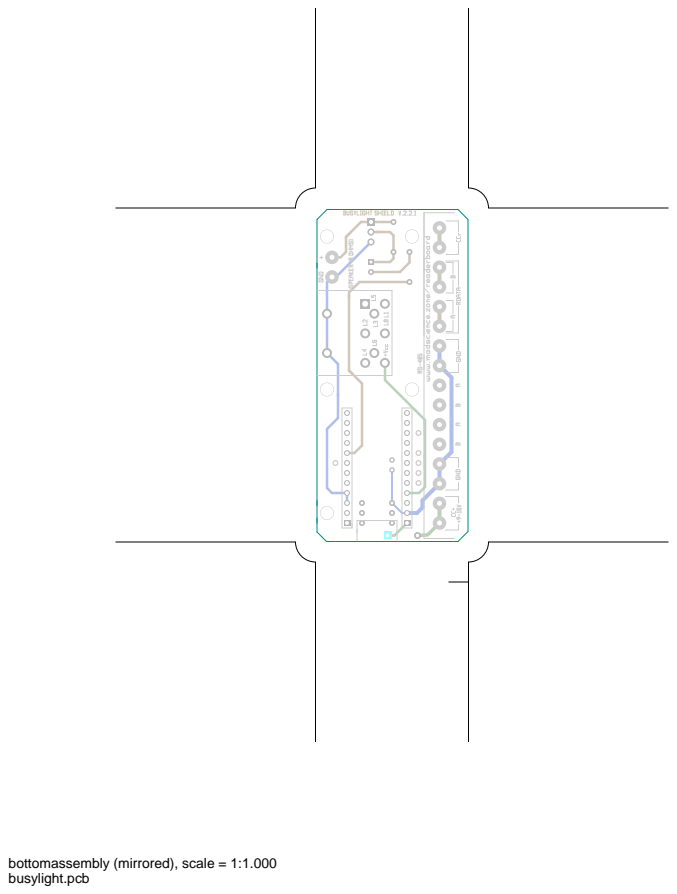
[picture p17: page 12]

bottomassembly (mirrored), scale = 1:1.000

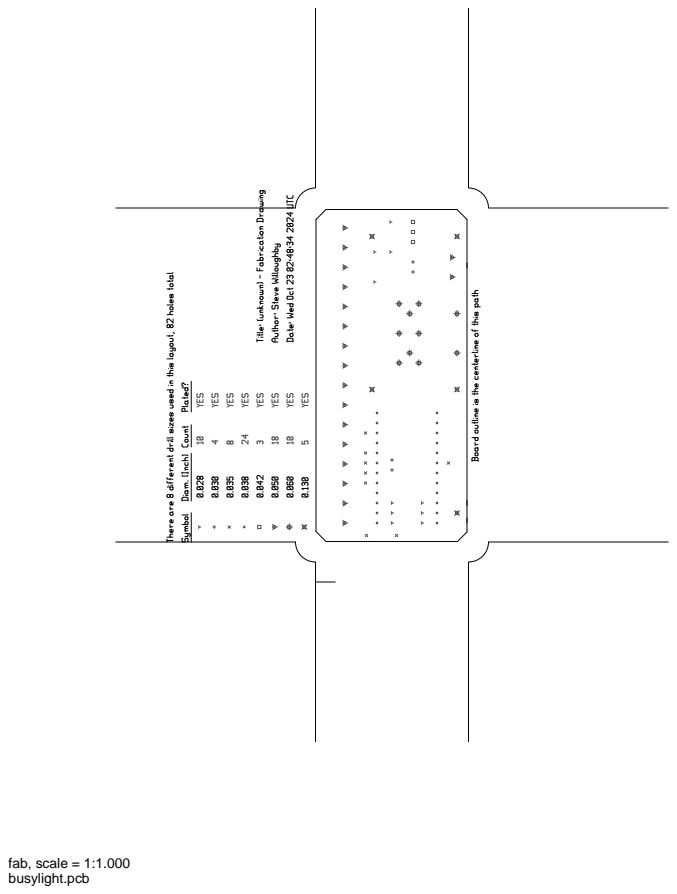
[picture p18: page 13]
fab, scale = 1:1.000

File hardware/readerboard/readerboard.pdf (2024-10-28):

## readerboard.pcb

## 1. Table of Contents (This Page) Created on Thu Oct 17 09:53:21 2024 2. top 3. ground 4. outline 5. plated-drill 6. unplated-drill 7. componentmask 8. soldermask 9. topsilk 10. bottomsilk 11. toppaste 12. topassembly 13. bottomassembly 14. fab

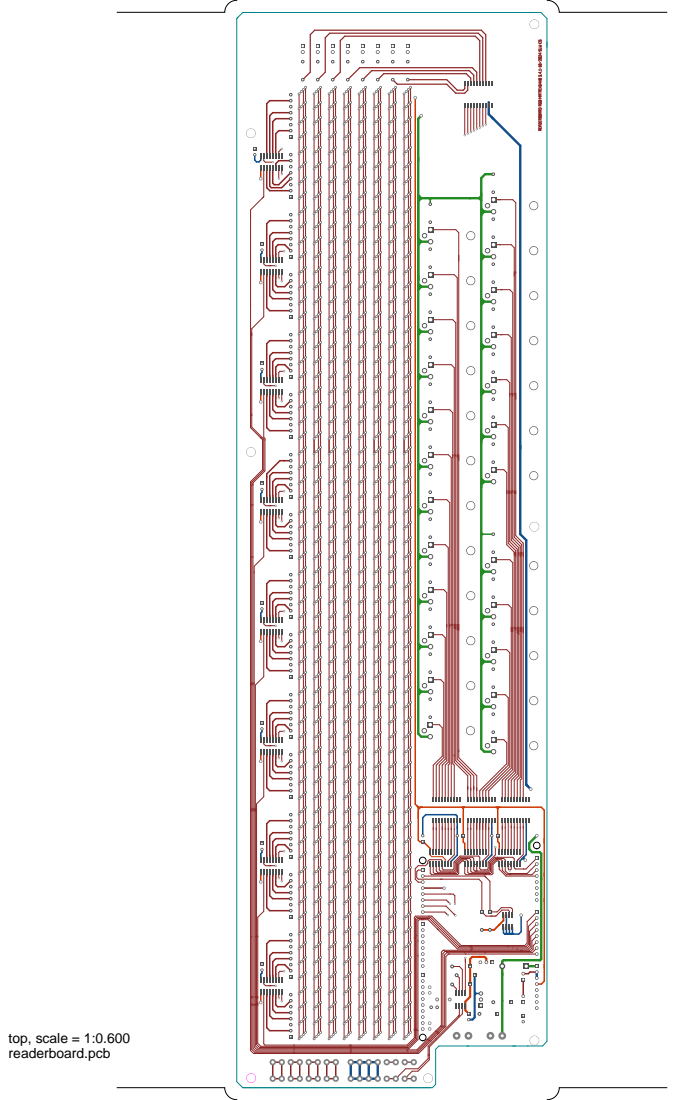
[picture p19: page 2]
top, scale = 1:0.600

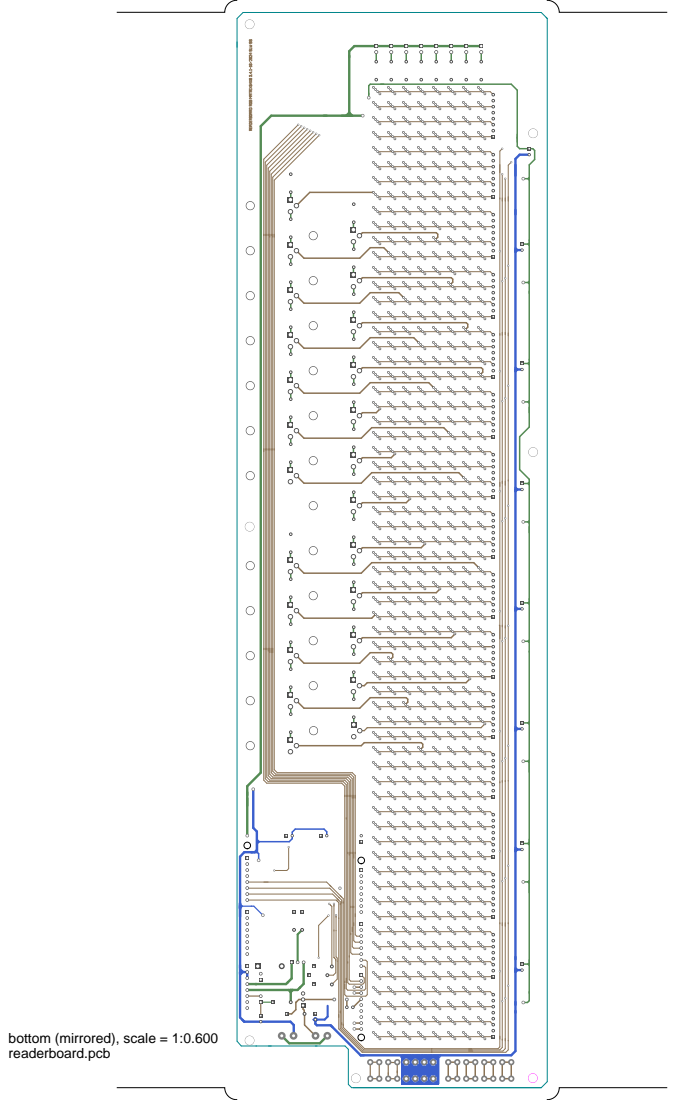
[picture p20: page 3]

bottom (mirrored), scale = 1:0.600

outline, scale = 1:0.600

plated-drill, scale = 1:0.600

unplated-drill, scale = 1:0.600

topmask, scale = 1:0.600


bottommask (mirrored), scale = 1:0.600

topsilk, scale = 1:0.600


bottomsilk (mirrored), scale = 1:0.600

toppaste, scale = 1:0.600

topassembly, scale = 1:0.600


bottomassembly (mirrored), scale = 1:0.600

fab, scale = 1:0.600





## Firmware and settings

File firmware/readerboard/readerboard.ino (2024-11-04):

//TODO bounds checking on setting font index
/* 
 *  ____  _____    _    ____  _____ ____  ____   ___    _    ____  ____  
 * |  _ \| ____|  / \  |  _ \| ____|  _ \| __ ) / _ \  / \  |  _ \|  _ \
 * | |_) |  _|   / _ \ | | | |  _| | |_) |  _ \| | | |/ _ \ | |_) | | | |
 * |  _ <| |___ / ___ \| |_| | |___|  _ <| |_) | |_| / ___ \|  _ <| |_| |
 * |_| \_\_____/_/   \_\____/|_____|_| \_\____/ \___/_/   \_\_| \_\____/ 
 *   __   _  _       ___  
 *  / /_ | || |__  _( _ ) 
 * | '_ \| || |\ \/ / _ \
 * | (_) |__   _>  < (_) |
 *  \___/   |_|/_/\_\___/ 
 *                        
 * Arduino Mega 2560/Due (or equiv.) firmware to drive revision 3 readerboards.
 * Previous versions of this code also supported my older readerboard designs
 * including 64x7 matrix layouts and 64x8 monochrome revision 1 and 2 boards.
 * These are no longer supported.
 *
 * Steve Willoughby (c) 2023, 2024
 */

#include <TimerEvent.h>
#include "fonts.h"
#include "readerboard.h"
#if HAS_I2C_EEPROM
# include "I2C_eeprom.h"
I2C_eeprom xEEPROM(0x50, I2C_DEVICESIZE_24LC256);
#elif HW_MC != HW_MC_DUE
# include <EEPROM.h>
#endif
#include "commands.h"

byte USB_baud_rate_code = EE_DEFAULT_USB_SPEED;
byte RS485_baud_rate_code = EE_DEFAULT_485_SPEED;
byte my_device_address = EE_DEFAULT_ADDRESS;
byte global_device_address =  EE_DEFAULT_GLOBAL_ADDRESS;
int USB_baud_rate = 0;
int RS485_baud_rate = 0;
bool RS485_enabled = false;
bool setup_completed = false;

#if IS_READERBOARD
void debug_image_buffer(byte buf[N_ROWS][N_COLS]);
void debug_hw_buffer(void);
#endif

//
// EEPROM locations
// $00 0x4B (sentinel)
// $01 0x00 (EEPROM layout version)
// $02 USB baud rate code
// $03 485 baud rate code
// $04 device address
// $05 global address
// $06 serial number [0]       <-- EE_ADDR_SERIAL_NO
// $07 serial number [1]                 |
// $08 serial number [2]                 V +EE_LENGTH_SERIAL_NO
// $09 serial number [3]
// $0A serial number [4]
// $0B serial number [5]
// $0C serial number [6]
// $0D matrix dimmer           <-- EE_ADDR_DIMMERS
// $0E L0 dimmer                         |
// $0F L1 dimmer                         V +EE_LENGTH_DIMMERS
// $10 L2 dimmer
// $11 L3 dimmer
// $12 L4 dimmer
// $13 L5 dimmer
// $14 L6 dimmer
// $15 L7 dimmer
// $16 0x4B (sentinel)
//
#define EE_VALUE_LAYOUT (1)
#define EE_VALUE_SENTINEL (0x4b)

#define EE_ADDR_SENTINEL  (0x00)
#define EE_ADDR_LAYOUT (0x01)
#define EE_ADDR_USB_SPEED (0x02)
#define EE_ADDR_485_SPEED (0x03)
#define EE_ADDR_DEVICE_ADDR (0x04)
#define EE_ADDR_GLOBAL_ADDR (0x05)
#define EE_ADDR_SERIAL_NO (0x06)
#define EE_LENGTH_SERIAL_NO (7)
#define EE_ADDR_DIMMERS (EE_ADDR_SERIAL_NO + EE_LENGTH_SERIAL_NO)
#define EE_LENGTH_DIMMERS (8)
#define EE_ADDR_SENTINEL2  (EE_ADDR_DIMMERS + EE_LENGTH_DIMMERS)
char serial_number[EE_LENGTH_SERIAL_NO] = "";

/* I/O port to use for full 8-bit write operations to the sign board */
/* On the Mega 2560, PORTF<7:0> corresponds to <A7:A0> pins */
/* On the Due, we just toggle the bits separately. */
/* TODO consider if using PORTF is even a good idea considering interrupts and such */
#if IS_READERBOARD
# if HW_MC == HW_MC_MEGA_2560
#  define MATRIX_DATA_PORT    PORTF   
# endif
#endif

#define LENGTH_OF(A) (sizeof(A) / sizeof(A[0]))

#if IS_READERBOARD
/* Refresh the display every REFRESH_MS milliseconds. For an 8-row
 * display, an overall refresh rate of 30 FPS =  4.16 mS
 *                                     25 FPS =  5.00 mS
 *                                     20 FPS =  6.26 mS
 *                                     15 FPS =  8.33 mS
 *                                     10 FPS = 12.50 mS
 *                                      5 FPS = 25.00 mS
 */
const int ROW_HOLD_TIME_US = 500;   /* how long in microseconds to hold the row on during refresh */
#endif

#if HW_MC != HW_MC_PRO
const int PIN_STATUS_LED = 13;
#endif

// Hardware notes
// DUE    MEGA                 READERBOARD              DUE    MEGA     PRO
//                                                  LED 13~    13~
//                                    SPEAKER           12~    12~      05
//                                                      11~    11~
//                                                      10~    10~
//                                    L4                09~    09~      06
//                                    L5                08~    08~      07
//     
//                                    L6                07~    07~      10
//                                    L7                06~    06~      --
//  A0/54  A0/54                 D7   L3                05~    05~      08
//  A1/55  A0/55                 D6   L2                04~    04~      09
//  A2/56  A0/56                 D5   L1                03~    03~      14
//  A3/57  A0/57                 D4   L0                02~    02~      16
//  A4/58  A0/58                 D3   USB TxD           01/TX0 01/TX0~
//  A5/59  A0/59                 D2   USB RxD           00/RX0 00/RX0~
//  A6/60  A0/60                 D1                     
//  A7/61  A0/61                 D0   485 TxD           14/TX3 14/TX3
//                                    485 RxD           15/RX3 15/RX3
//  A8/62  A0/62              SRCLK   485 DE            16/TX2 16/TX2   02
//  A9/63  A0/53               /CLR   485 /RE           17/RX2 17/RX2   03
// A10/64 A10/64                  /G                    18/TX1 18/TX1
// A11/65 A11/65                RCLK   R3               19/RX1 19/RX1
//     66 A12/66                  R0                    20/SDA 20/SDA
//     67 A13/67                  R1                    21/SCL 21/SCL
//     68 A14/68                  R2
//     69 A15/69                  R4
// 
//     --    4K  EEPROM
//    96K    8K  SRAM
//   512K  256K  flash memory
//     32    16  word size (bits)
//    ARM ATmga  architecture
// (Due uC is Atmel SAM3X8E ARM Cortex-M3 at 84MHz)
// (Mega uC is ATmega2560 at 16MHz)
// Use programming port for USB connection
//
// Auto-reset
// Classic Arduinos reset when DTR or RTS is triggered on connection. Prevent with 10uF cap on RST to GND.
// Leonardo resets when port is "touched" at 1200bps, not merely opened.
// NOTE: "while (!Serial);" waits for the port to be connected to.
// Due native port doesn't reset the system, so using that prevents resets
// Due programming port: open at 1200 to erase; other opens cause reset like other boards. Cap doesn't work.
// but a 1K resistor between RST and 3.3V will keep reset high.



#if IS_HW_LOGIC(MODEL_LOGIC_3xx)
const int PIN_D0    = 61;   // column data bit 0
const int PIN_D1    = 60;   // column data bit 1
const int PIN_D2    = 59;   // column data bit 2
const int PIN_D3    = 58;   // column data bit 3
const int PIN_D4    = 57;   // column data bit 4
const int PIN_D5    = 56;   // column data bit 5
const int PIN_D6    = 55;   // column data bit 6
const int PIN_D7    = 54;   // column data bit 7
const int PIN_SRCLK = 62;   // strobe bits into shift reg
const int PIN__SRCLR= 63;   // ~clear shift register
const int PIN__G    = 64;   // ~output enable
const int PIN_RCLK  = 65;   // strobe shift reg to output buffer
const int PIN_R0    = 66;   // row address 0
const int PIN_R1    = 67;   // row address 1
const int PIN_R2    = 68;   // row address 2
const int PIN_R4    = 69;   // row address 4
const int PIN_R3    = 19;   // row address 3
const int PIN_L0    =  2;   // discrete LED 0 (bottom)
const int PIN_L1    =  3;   // discrete LED 1 
const int PIN_L2    =  4;   // discrete LED 2
const int PIN_L3    =  5;   // discrete LED 3
const int PIN_L4    =  9;   // discrete LED 4
const int PIN_L5    =  8;   // discrete LED 5
const int PIN_L6    =  7;   // discrete LED 6
const int PIN_L7    =  6;   // discrete LED 7 (top) 
const int PIN_DE    = 16;   // RS-485 driver enable (1=enabled)
const int PIN__RE   = 17;   // RS-485 ~receiver enable (0=enabled)
const int PIN_SPKR  = 12;   // PWM output driving speaker
# ifdef SPEAKER_INSTALLED
#  define HAS_SPEAKER (SPEAKER_INSTALLED)
# else
#  define HAS_SPEAKER (true)
# endif

# if HAS_SPEAKER
#  if HW_MC == HW_MC_DUE
#   define HAS_TONE_SUPPORT (false)
#  else
#   define HAS_TONE_SUPPORT (true)
# endif
# endif

#elif IS_HW_LOGIC(MODEL_LOGIC_B_1xx)
const int PIN_L0    = 16;   // discrete LED 0 (bottom)
const int PIN_L1    = 14;   // discrete LED 1 
const int PIN_L2    =  9;   // discrete LED 2 
const int PIN_L3    =  8;   // discrete LED 3 
const int PIN_L4    =  6;   // discrete LED 4 
const int PIN_L5    =  7;   // discrete LED 5 
const int PIN_L6    = 10;   // discrete LED 6 (top)
# define HAS_SPEAKER (false)
#elif IS_HW_LOGIC(MODEL_LOGIC_B_2xx)
const int PIN_L0    = 16;   // discrete LED 0 (bottom)
const int PIN_L1    = 14;   // discrete LED 1 
const int PIN_L2    =  9;   // discrete LED 2 
const int PIN_L3    =  8;   // discrete LED 3 
const int PIN_L4    =  6;   // discrete LED 4 
const int PIN_L5    =  7;   // discrete LED 5 
const int PIN_L6    = 10;   // discrete LED 6 (top)
const int PIN_DE    =  2;   // RS-485 driver enable (1=enabled)
const int PIN__RE   =  3;   // RS-485 ~receiver enable (0=enabled)
const int PIN_SPKR  =  5;   // PWM output driving speaker
# ifdef SPEAKER_INSTALLED
#  define HAS_SPEAKER (SPEAKER_INSTALLED)
# else
#  define HAS_SPEAKER (true)
# endif

# if HAS_SPEAKER
#  define HAS_TONE_SUPPORT (false)
# endif

#elif IS_HW_LOGIC(MODEL_LOGIC_ADA)
const int PIN_DE  =16; // RS-485 driver enable (1=enabled)
const int PIN__RE =17; // RS-485 ~receiver enable (0=enabled)
const int PIN_A   =62; // Row select bit A (A0)
const int PIN_B   =68; // Row select bit B (A1)
const int PIN_C   =63; // Row select bit C (A2)
const int PIN_D   =67; // Row select bit D (A3)
const int PIN_E   =55; // Row select bit E (A4)
const int PIN_R1  =58; // Col data RED 1
const int PIN_R2  =60; // Col data RED 2
const int PIN_G1  =57; // Col data GRN 1
const int PIN_G2  =56; // Col data GRN 2
const int PIN_B1  =59; // Col data BLU 1
const int PIN_B2  =61; // Col data BLU 2
const int PIN_CLK =64; // Matrix Data clock
const int PIN_OE  =65; // Matrix output enable
const int PIN_LAT =66; // Matrix output latch
# if IS_MODEL_CLASS(MODEL_CLASS_QSCC)
const int PIN_L0  =18; // discrete LED 0
const int PIN_L1  =19; //     |
const int PIN_L2  = 2; //     |
const int PIN_L3  = 3; //     |
const int PIN_L4  = 4; //     |
const int PIN_L5  = 5; //     |
const int PIN_L6  = 6; //     |
const int PIN_L7  = 7; //     |
const int PIN_L8  = 8; //     |
const int PIN_L9  = 9; //     |
const int PIN_L10 =10; //     |
const int PIN_L11 =11; //     |
const int PIN_L12 =12; //     V
const int PIN_L13 =13; // discrete LED 13
#  define HAS_ALPHA_CHARS (true)
#  if HW_MC == HW_MC_MEGA_2560
#    define I2C_ALPHA_CHARS (Wire)
#  elif HW_MC == HW_MC_DUE
#    define I2C_ALPHA_CHARS (Wire1)
#  elif
#    error "unsupported hardware configuration"
#  endif
# else /* not QSCC */
#  define HAS_ALPHA_CHARS (false)
const int PIN_L0  = 2; // discrete LED 0 (bottom)
const int PIN_L1  = 3; //     |
const int PIN_L2  = 4; //     |
const int PIN_L3  = 5; //     |
const int PIN_L4  = 6; //     |
const int PIN_L5  = 7; //     |
const int PIN_L6  = 8; //     V
const int PIN_L7  = 9; // discrete LED 7 (top)
const int PIN_SPKR=12; // PWM output driving speaker
# endif

#else
# error "HW_MODEL not defined to supported logic control model"
#endif

#ifdef SN_B0001
# define HAS_SPEAKER (false)
# define HAS_TONE_SUPPORT (false)
//const int PIN_SPKR = 5;
#endif
#ifdef SN_RB0000
# define HAS_SPEAKER (true)
# define HAS_TONE_SUPPORT (false)
#endif

#if IS_READERBOARD
byte matrix_brightness = 255;
byte led_brightness[8] = {255, 255, 255, 255, 255, 255, 255, 255};
bool led_state[8] = {false, false, false, false, false, false, false, false};
const bool led_dimmable[8] = {true, true, true, true, true, true, true, true};
const int discrete_led_set[8] = {PIN_L0, PIN_L1, PIN_L2, PIN_L3, PIN_L4, PIN_L5, PIN_L6, PIN_L7};
const byte discrete_led_labels[8] = {
    R_STATUS_LED_COLOR_L0,
    R_STATUS_LED_COLOR_L1,
    R_STATUS_LED_COLOR_L2,
    R_STATUS_LED_COLOR_L3,
    R_STATUS_LED_COLOR_L4,
    R_STATUS_LED_COLOR_L5,
    R_STATUS_LED_COLOR_L6,
    R_STATUS_LED_COLOR_L7,
};
const byte column_block_set[8] = {PIN_D0, PIN_D1, PIN_D2, PIN_D3, PIN_D4, PIN_D5, PIN_D6, PIN_D7};
#else
byte led_brightness[7] = {255, 255, 255, 255, 255, 255, 255};
bool led_state[7] = {false, false, false, false, false, false, false};
// The busylight only has PWM dimming on ports 6, 9, and 10, which corresponds to L2, L4, and L6.
const bool led_dimmable[7] = {false, false, true, false, true, false, true};
const int discrete_led_set[7] = {PIN_L0, PIN_L1, PIN_L2, PIN_L3, PIN_L4, PIN_L5, PIN_L6};
const byte discrete_led_labels[7] = {
    B_STATUS_LED_COLOR_L0,
    B_STATUS_LED_COLOR_L1,
    B_STATUS_LED_COLOR_L2,
    B_STATUS_LED_COLOR_L3,
    B_STATUS_LED_COLOR_L4,
    B_STATUS_LED_COLOR_L5,
    B_STATUS_LED_COLOR_L6,
};
#endif

//
// setup_pins()
//   Setup the I/O pin modes and initialize the sign hardware.
//
void setup_pins(void)
{
#if HW_MC != HW_MC_PRO
	pinMode(PIN_STATUS_LED, OUTPUT);
#endif
#if IS_READERBOARD
# if IS_HW_LOGIC(MODEL_LOGIC_3xx)
    pinMode(PIN_D0, OUTPUT);
    pinMode(PIN_D1, OUTPUT);
    pinMode(PIN_D2, OUTPUT);
    pinMode(PIN_D3, OUTPUT);
    pinMode(PIN_D4, OUTPUT);
    pinMode(PIN_D5, OUTPUT);
    pinMode(PIN_D6, OUTPUT);
    pinMode(PIN_D7, OUTPUT);
    pinMode(PIN_SRCLK, OUTPUT);
    pinMode(PIN__SRCLR, OUTPUT);
    pinMode(PIN__G, OUTPUT);
    pinMode(PIN_RCLK, OUTPUT);
    pinMode(PIN_R0, OUTPUT);
    pinMode(PIN_R1, OUTPUT);
    pinMode(PIN_R2, OUTPUT);
    pinMode(PIN_R3, OUTPUT);
    pinMode(PIN_R4, OUTPUT);
# else
#  error "unsupported readerboard control logic"
# endif
#endif
#ifdef SERIAL_485
    pinMode(PIN_DE, OUTPUT);
    pinMode(PIN__RE, OUTPUT);
#endif
    pinMode(PIN_L0, OUTPUT);
    pinMode(PIN_L1, OUTPUT);
    pinMode(PIN_L2, OUTPUT);
    pinMode(PIN_L3, OUTPUT);
    pinMode(PIN_L4, OUTPUT);
    pinMode(PIN_L5, OUTPUT);
    pinMode(PIN_L6, OUTPUT);
#if IS_READERBOARD
    pinMode(PIN_L7, OUTPUT);
#endif
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
void loop(void)
{
#if IS_READERBOARD
    refresh_hw_buffer();
	transitions.update();
//	status_timer.update();
#endif
    /* flash/strobe discrete LEDs as needed */
    flasher.update();
    strober.update();
#if HAS_SPEAKER
    sound_timer.update();
#endif

    /* receive commands via serial port */
    if (Serial.available() > 0) {
        receive_serial_data(FROM_USB);
    }

#ifdef SERIAL_485
    if (RS485_enabled && SERIAL_485.available() > 0) {
        receive_serial_data(FROM_485);
    }
#endif
//
//
//          MEGA    DUE
// Serial   RX/TX   RX/TX       USB Direct
// Serial1  Rx1/Tx1 Rx1/Tx1
// Serial2  Rx2/Tx2 Rx2/Tx2
// Serial3  Rx3/Tx3 Rx3/Tx3     RS-485
// Serial4  --
}

void start_485_reply(void)
{
#ifdef SERIAL_485
    if (!RS485_enabled)
        return;
    
    digitalWrite(PIN_DE, HIGH); // enable driver
    if (my_device_address >= 16) {
        SERIAL_485.write(0xf0 | global_device_address);
        SERIAL_485.write(0x01);
        SERIAL_485.write(my_device_address & 0x3f);
    }
    else {
        SERIAL_485.write(0xd0 | my_device_address);
    }
#endif
}

void send_485_byte(byte x)
{
#ifdef SERIAL_485
    if (!RS485_enabled)
        return;

    if (x == 0x7f || x == 0x7e) {
        SERIAL_485.write(0x7f);
        SERIAL_485.write(x);
    }
    else if ((x & 0x80) == 0) {
        SERIAL_485.write(x);
    }
    else {
        SERIAL_485.write(0x7e);
        SERIAL_485.write(x & 0x7f);
    }
#endif
}

void end_485_reply(void)
{
#ifdef SERIAL_485
    digitalWrite(PIN_DE, LOW); // disable driver
#endif
}

void start_usb_reply(void)
{
}

void send_usb_byte(byte x)
{
    Serial.write(x);
}

void end_usb_reply(void)
{
}

void test_pattern(void) 
{
	flag_test();
#if IS_READERBOARD
    clear_all_buffers();
# if IS_HW_LOGIC(MODEL_LOGIC_3xx)
    //                                  //            _ _____
    //                                  // SRCLK RCLK G SRCLR R4 R3 R2 R1 R0
    digitalWrite(PIN__SRCLR, LOW);	    //   X    X   1   0    X  X  X  X  X    reset shift register
    digitalWrite(PIN__SRCLR, HIGH);	    //   X    X   1   1    X  X  X  X  X    |
    //
	digitalWrite(PIN_D0, HIGH);		//   0    0   1   1    1  1  0  0  0    shift "on" bit in column 0
	digitalWrite(PIN_D1, HIGH);		//   0    0   1   1    1  1  0  0  0    shift "on" bit in column 0
	digitalWrite(PIN_D2, HIGH);		//   0    0   1   1    1  1  0  0  0    shift "on" bit in column 0
	digitalWrite(PIN_D3, HIGH);		//   0    0   1   1    1  1  0  0  0    shift "on" bit in column 0
	digitalWrite(PIN_D4, HIGH);		//   0    0   1   1    1  1  0  0  0    shift "on" bit in column 0
	digitalWrite(PIN_D5, HIGH);		//   0    0   1   1    1  1  0  0  0    shift "on" bit in column 0
	digitalWrite(PIN_D6, HIGH);		//   0    0   1   1    1  1  0  0  0    shift "on" bit in column 0
	digitalWrite(PIN_D7, HIGH);		//   0    0   1   1    1  1  0  0  0    shift "on" bit in column 0
	digitalWrite(PIN_SRCLK, HIGH);	//   1    0   1   1    1  1  0  0  0    clock in bit
	digitalWrite(PIN_SRCLK, LOW);	//   0    0   1   1    1  1  0  0  0    |
	digitalWrite(PIN_RCLK, HIGH);	//   0    1   1   1    1  1  0  0  0    clock data to output buffer
	digitalWrite(PIN_RCLK, LOW);	//   0    0   1   1    1  1  0  0  0    |
	digitalWrite(PIN_D0, LOW);		//   0    0   1   1    1  1  0  0  0    set up to shift "off" bits next
	digitalWrite(PIN_D1, LOW);		//   0    0   1   1    1  1  0  0  0    set up to shift "off" bits next
	digitalWrite(PIN_D2, LOW);		//   0    0   1   1    1  1  0  0  0    set up to shift "off" bits next
	digitalWrite(PIN_D3, LOW);		//   0    0   1   1    1  1  0  0  0    set up to shift "off" bits next
	digitalWrite(PIN_D4, LOW);		//   0    0   1   1    1  1  0  0  0    set up to shift "off" bits next
	digitalWrite(PIN_D5, LOW);		//   0    0   1   1    1  1  0  0  0    set up to shift "off" bits next
	digitalWrite(PIN_D6, LOW);		//   0    0   1   1    1  1  0  0  0    set up to shift "off" bits next
	digitalWrite(PIN_D7, LOW);		//   0    0   1   1    1  1  0  0  0    set up to shift "off" bits next
    for (int i=0; i<8; i++) {
        test_sequence_rows();
        digitalWrite(PIN_SRCLK, HIGH);	//   1    0   1   1    1  1  0  0  0    clock in bit
        digitalWrite(PIN_SRCLK, LOW);	//   0    0   1   1    1  1  0  0  0    |
        digitalWrite(PIN_RCLK, HIGH);	//   0    1   1   1    1  1  0  0  0    clock data to output buffer
        digitalWrite(PIN_RCLK, LOW);	//   0    0   1   1    1  1  0  0  0    |
    }
    test_sequence_rows();

    /* test high-speed full-matrix refresh */
#  if HW_MODEL == MODEL_3xx_MONOCHROME
    test_row(0x04, 0xaa, 0x55);
    test_row(0x04, 0x55, 0xaa);
#  else
    for (byte color=1; color <=7; color++) {
        test_row(color, 0xaa, 0x55);
    }
    for (byte color=1; color <=7; color++) {
        test_row(color, 0x55, 0xaa);
    }
#  endif
    test_row(7, 0x01, 0x01);
    test_row(7, 0x02, 0x02);
    test_row(7, 0x04, 0x04);
    test_row(7, 0x08, 0x08);
    test_row(7, 0x10, 0x10);
    test_row(7, 0x20, 0x20);
    test_row(7, 0x40, 0x40);
    test_row(7, 0x80, 0x80);
	test_sweep();
# else /* LOGIC MODEL 3xx */
#  error "unsupported readerboard logic"
# endif
#endif /* IS_READERBOARD */
}

#if IS_READERBOARD
void test_sweep()
{
#if IS_HW_LOGIC(MODEL_LOGIC_3xx)
	// Run a single column right and then left
	for (int block=0; block<8; block++) {
		digitalWrite(column_block_set[block], LOW);
	}
    //                                  //            _ _____
    //                                  // SRCLK RCLK G SRCLR R4 R3 R2 R1 R0
    digitalWrite(PIN__SRCLR, LOW);	    //   X    X   1   0    X  X  X  X  X    reset shift register
    digitalWrite(PIN__SRCLR, HIGH);	    //   X    X   1   1    X  X  X  X  X    |
	for (int block=0; block<8; block++) {
		for (int col=0; col<8; col++) {
			//                                  //            _ _____
			//                                  // SRCLK RCLK G SRCLR R4 R3 R2 R1 R0
			digitalWrite(column_block_set[block], col==0 ? HIGH : LOW);
			//                                  //            _ _____
			//									// SRCLK RCLK G SRCLR R4 R3 R2 R1 R0
			digitalWrite(PIN_SRCLK, HIGH);		//   1    0   1   1    X  X  X  X  X    clock in bit
			digitalWrite(PIN_SRCLK, LOW);		//   0    0   1   1    X  X  X  X  X    |
			//                                  //            _ _____
			//                                  // SRCLK RCLK G SRCLR R4 R3 R2 R1 R0
			digitalWrite(PIN_RCLK, HIGH);   	//   0    1   1   1    X  X  X  X  X    clock data to output buffer
			digitalWrite(PIN_RCLK, LOW);    	//   0    0   1   1    X  X  X  X  X    |

            for (int i=0; i<10; i++) {
# if HW_MODEL == MODEL_3xx_RGB
                test_sweep_col(LOW, LOW);
                test_sweep_col(LOW, HIGH);
                test_sweep_col(HIGH, LOW);
# elif HW_MODEL == MODEL_3xx_MONOCHROME
                test_sweep_col(HIGH, LOW);
# else
#  error "hw model not set"
# endif
            }
		}
	}
	digitalWrite(PIN_R4, HIGH); // off
	digitalWrite(PIN_R3, HIGH);
#else
# error "unsupported readerboard logic"
#endif /* 3xx logic */
}

void test_sweep_col(int r4, int r3)
{
#if IS_HW_LOGIC(MODEL_LOGIC_3xx)
    digitalWrite(PIN__G, HIGH);
    digitalWrite(PIN_R4, r4);
    digitalWrite(PIN_R3, r3);
    for (int r=0; r<8; r++) {
        digitalWrite(PIN_R2, (r&0x04)?HIGH:LOW);
        digitalWrite(PIN_R1, (r&0x02)?HIGH:LOW);
        digitalWrite(PIN_R0, (r&0x01)?HIGH:LOW);
        digitalWrite(PIN__G, LOW);
        delayMicroseconds(ROW_HOLD_TIME_US);
        digitalWrite(PIN__G, HIGH);
    }
#else
# error "unsupported readerboard logic"
#endif /* 3xx logic */
}
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

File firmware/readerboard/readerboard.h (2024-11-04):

/*
 ____  _____    _    ____  _____ ____  ____   ___    _    ____  ____  
|  _ \| ____|  / \  |  _ \| ____|  _ \| __ ) / _ \  / \  |  _ \|  _ \
| |_) |  _|   / _ \ | | | |  _| | |_) |  _ \| | | |/ _ \ | |_) | | | |
|  _ <| |___ / ___ \| |_| | |___|  _ <| |_) | |_| / ___ \|  _ <| |_| |
|_| \_\_____/_/   \_\____/|_____|_| \_\____/ \___/_/   \_\_| \_\____/ 
                                                                      
Libraries Required:
    EEPROM 2.0
	I2C_EEPROM 1.8.5
	TimerEvent 0.5.0
	Wire 1.0
*/


#ifndef READERBOARD_CORE
#define READERBOARD_CORE


// Readerboard hardware models for HW_MODEL
#define MODEL_LOGIC_MASK        (0xf000)
#define MODEL_LOGIC_3xx         (0x1000)
#define MODEL_LOGIC_B_1xx       (0x2000)
#define MODEL_LOGIC_B_2xx       (0x3000)
#define MODEL_LOGIC_ADA         (0x4000)

#define MODEL_CLASS_MASK        (0x0f00)
#define MODEL_CLASS_RB          (0x0100)

#define MODEL_3xx_MONOCHROME    (0x1103)
#define MODEL_3xx_RGB           (0x1104)

#define MODEL_CLASS_BUSYLIGHT   (0x0200)
#define MODEL_BUSYLIGHT_1       (0x2205)
#define MODEL_BUSYLIGHT_2       (0x3206)

#define MODEL_CLASS_ADA         (0x0300)
#define MODEL_ADA_32x16         (0x4301)
#define MODEL_ADA_32x32         (0x4302)
#define MODEL_ADA_64x16         (0x4303)    // two 32x16 boards
#define MODEL_ADA_64x64         (0x4304)

#define MODEL_CLASS_QSCC        (0x0400)
#define MODEL_QSCC_64x16        (0x4403)

/* LEGACY models NO LONGER supported. Do not use these. */
#define MODEL_CLASS_OBSOLETE         (0x0000)
#define MODEL_LEGACY_64x7            (0x0000)
#define MODEL_LEGACY_64x8            (0x0001)
#define MODEL_LEGACY_64x8_INTEGRATED (0x0002)

// Microcontroller Models for HW_MC
#define HW_MC_MEGA_2560 (0)
#define HW_MC_DUE (1)
#define HW_MC_PRO (2)

#define EE_ADDRESS_DISABLED (0xff) /* use this as the address if the RS-485 interface is not used */


//_____________________________________________________________________________
//   ____ ___  _   _ _____ ___ ____ _   _ ____      _  _____ ___ ___  _   _ 
//  / ___/ _ \| \ | |  ___|_ _/ ___| | | |  _ \    / \|_   _|_ _/ _ \| \ | |
// | |  | | | |  \| | |_   | | |  _| | | | |_) |  / _ \ | |  | | | | |  \| |
// | |__| |_| | |\  |  _|  | | |_| | |_| |  _ <  / ___ \| |  | | |_| | |\  |
//  \____\___/|_| \_|_|   |___\____|\___/|_| \_\/_/   \_\_| |___\___/|_| \_|
//_____________________________________________________________________________
//                                                                          
// BEGIN CONFIGURATION SECTION
// TODO: Set these before compiling for a particular hardware configuration
#define HW_MODEL (MODEL_3xx_RGB)
#define HW_MC (HW_MC_DUE)
//#define HW_MC (HW_MC_MEGA_2560)
//#define HW_MODEL (MODEL_BUSYLIGHT_2)
//#define HW_MC (HW_MC_PRO)
#define HAS_I2C_EEPROM (false)

// TODO: Set these default settings (this will be the "factory default settings")
//       On Due-based systems without EEPROM chip U16 installed, this is the only way to
//       make these settings at all. If the EEPROM is installed (or one is built-in
//       to the microcontroller), this is just the default
//       that can be overridden by configuring the unit since the new configuration
//       values can be saved in EEPROM.
//
// Default baud rate. Allowed values are '0'=300, '1'=600, '2'=1200, '3'=2400,
//                    '4'=4800, '5'=9600, '6'=14400, '7'=19200, '8'=28800,
//                    '9'=31250, 'A'=38400, 'B'=57600, 'C'=115200.
#define EE_DEFAULT_USB_SPEED  ('5')	/* usb connections 9600 baud */
#define EE_DEFAULT_485_SPEED ('5')  /* RS-485 connections 9600 baud */
//
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

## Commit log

2023-08-14 added hardware prototype files
    [matrix64x8.kicad_sch]
2023-09-01 hw 2.0
    [matrix64x8.kicad_sch]
2023-09-03 updated boards
    [matrix64x8.kicad_sch]
2023-12-10 updates to 210 board
2024-02-14 experimental work on new pcbs
2024-08-27 updates to circuit designs and schematics
    [matrix64x8_rgb.kicad_sch]
2024-08-28 protocol notes
    [matrix64x8_rgb.kicad_sch]
2024-08-28 3.2.2 pcb update
2024-08-29 corrected R34 placement on schematic to match what is actually on the PCB 3.2.2
    [matrix64x8_rgb.kicad_sch]
2024-09-17 added 3.3.0 pcb
2024-09-30 fixed image input bug
    [commands.ino]
2024-10-02 pcb 3.3.1 updates, documentation
    [readerboard.kicad_sch]
2024-10-03 device class codes
2024-10-08 morse, etc
    [readerboard.kicad_sch]
2024-10-10 corrected ramp timing for non-dimmable lights
    [readerboard.ino]
2024-10-10 design updates
    [busylight.kicad_sch, readerboard.kicad_sch]
2024-10-13 current, update
2024-10-15 slight adjustment to busylight pcb
2024-10-15 busylight pcb change
2024-10-16 fixed sound player bug
    [commands.ino, readerboard.h, readerboard.ino]
2024-10-16 corrected morse code audio
    [readerboard.h, readerboard.ino]
2024-10-17 board and doc updates
2024-10-27 corrected incorrect trace in readerboard pcb
2024-10-27 pcb designs
2024-10-29 updates for protocol
    [adashield.kicad_sch, adashield_qs.kicad_sch]
2024-11-01 fixed morse code timing error
    [readerboard.ino]
